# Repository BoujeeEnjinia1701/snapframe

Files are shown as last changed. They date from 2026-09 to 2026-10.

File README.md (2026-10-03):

# SnapFrame

     

**Area:** Situational Field Hardware · **TRL:** 3 of 9 (proof of concept on paper) · **Value-engineering target:** about $445 USD for the frame kit · **Difficulty:** 2 of 5

Frame kit of standard EMT conduit joined by printed or cast nodes, with parametric nodes generated for several shelter sizes.

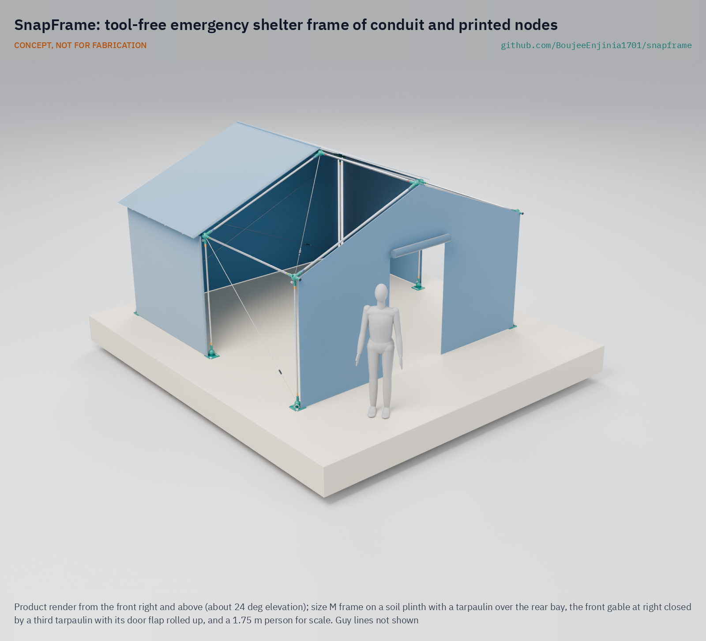
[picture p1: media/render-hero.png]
SnapFrame: tool-free emergency shelter frame of conduit and printed nodes, product render


[Exploded render](media/render-exploded.png) · [Detail render](media/render-detail.png) · [Interactive 3D model](media/viewer.html) · [Concept blueprint (PDF)](media/concept-blueprint.pdf) · [General arrangement (PDF)](cad/drawings/SNF-DWG-001.pdf) · [Calculations](docs/04-calcs/01-sizing.md) · [Prototype build plan](docs/05-build-plan.md) · [Design decisions](docs/06-design-decisions.md) · [Review note](docs/REVIEW.md)

## Concept rationale

A shelter frame has to arrive where the tarpaulins already are, go up by hand on the first day and be fixable by whoever is on site. SnapFrame therefore uses only straight, cut and drilled EMT conduit, a tube sold in hardware stores and electrical wholesalers across much of the world, and puts all the geometry into the nodes. The nodes are generated from a few parameters, so one open model gives the whole family of shelter sizes, and each node locks with the same spring button used in tent poles, so no tools, bolts or skilled labor are needed.

Keeping the design open and garage-buildable matters because relief supply chains break at the moment they are needed most. A local print farm, makerspace or small foundry can make the nodes from the published files, and a fabricator with a saw and a drill can cut the tubes, so a response does not wait for one supplier's crates or spare parts.

## Burning platform

Disasters triggered [45.8 million internal displacements in 2024, up from 26.8 million in 2023 and nearly double the annual average of the past decade](https://news.un.org/en/story/2025/05/1163176), according to the Internal Displacement Monitoring Centre, and a record 83.4 million people were living in internal displacement at the end of the year. Each of those households needs covered space quickly; the humanitarian minimum is [3.5 m² of covered living space per person](https://emergency.unhcr.org/emergency-assistance/shelter-camp-and-settlement/shelter-and-housing/emergency-shelter-solutions-and-standards).

The standard first response is still plastic sheeting. The IFRC and ICRC [shelter kit](https://itemscatalogue.redcross.int/relief--4/shelter-and-construction-materials--23/shelter-and-construction-kits--104/shelter-kit--KRELSHEK02.aspx) supplies two 4 x 6 m tarpaulins, rope, fixings and tools, but leaves the frame to local timber or bamboo, which is often scarce or already used up after a large event. The gap between a tarpaulin and a shelter that stands up to wind is a frame.

## Where it could be used

### By industry

| Industry | Use |
| --- | --- |
| Humanitarian shelter (relief agencies, NGOs) | Pre-positioned frame kits that fit existing tarpaulin stock in the first weeks after a disaster |
| Civil protection and emergency management | Mass care, reception and distribution points put up by volunteers without tools |
| Health and education in emergencies | Size L frames (about 24 m²) for temporary clinics, classrooms and child-friendly spaces |
| Events and temporary structures | Reusable shade and weather cover from one parametric kit, in place of bolted conduit frames |
| Agriculture | Shade, drying and storage shelters that later take better cladding |

### By country or region

| Country or region | Why it matters there |
| --- | --- |
| Pakistan | The 2022 floods affected [an estimated 33 million people and damaged nearly one million homes](https://news.un.org/en/story/2022/08/1125752), a scale at which local timber for frames runs out |
| Türkiye | The February 2023 earthquakes left [about 1.5 million people homeless in southern Türkiye](https://news.un.org/en/story/2023/02/1133717), with at least 500,000 new homes needed for reconstruction, so emergency shelter has to bridge years, not weeks |
| Mozambique | After Cyclone Idai in 2019, [more than 93,000 people were relocated to resettlement sites](https://www.unhcr.org/us/news/stories/one-year-people-displaced-cyclone-idai-struggle-rebuild) in the worst-affected region, and each of them needed a shelter |
| United States | A high-income example: the United States accounted for [about a quarter of the world's disaster displacements in 2024](https://news.un.org/en/story/2025/05/1163176), and EMT is stocked in hardware stores nationwide, so kits could be made near the response |

## What sparked the idea

The idea traces back to the MERO system, the "MEngeringhausen ROhrbauweise" (tube construction method) that Max Mengeringhausen developed in Germany at the end of the 1930s, as [economical building solutions made from industrially prefabricated series elements](https://mero.de/en/the-company/). The company's own patents describe the result: space frames of tubular rods screwed into near-spherical node pieces, citing Mengeringhausen's book *Raumfachwerke aus Stäben und Knoten* (Space frames of bars and nodes) ([EP0475216B1, MERO Raumstruktur](https://patents.google.com/patent/EP0475216B1/de)). MERO showed that when all the angles live in a mass-produced node, the members can be plain, identical tubes. SnapFrame takes that principle down to the scale of a family shelter: the tubes are trade-size conduit from a hardware store, the nodes are printed from a parametric model, and the screwed joints of MERO give way to spring buttons that lock by hand.

## Problem

Emergency shelters need frames that ship flat and go up without tools. Relief agencies stock standard 4 x 6 m tarpaulins, but the frame is usually left to scarce local timber, and purpose-built flat-pack shelters are costly and tied to one supplier. Design with, not for: requirements must come from co-design sessions and field trials with the intended users through a local partner.

## Concept

Frame kit of standard EMT conduit joined by printed or cast nodes, with parametric nodes generated for several shelter sizes.

The reference size M is a 4.0 x 4.0 m (16 m²) gable frame with a 2.6 m ridge: 18 straight EMT tubes (1 in rafters and ridge tubes, 3/4 in posts and eave tubes), 15 printed nodes in four variants with spring-button sockets, cable bracing, hand-turned screw anchors, and standard tarpaulins from agency stock (two, and part of a third for the front gable), and a folding step for the ridge sockets. The TRL 3 calculation note puts the constructable frame kit at about 46.2 kg and $701 ($256 over the $445 value-engineering target, mostly the nodes in filled nylon) and the wind rating at about 19.5 m/s, just short of the 20 m/s target, with the 3/4 in posts governing in the frame analysis. See the [design decisions register](docs/06-design-decisions.md) for decisions and open items.

Full design precis: [docs/02-concept.md](docs/02-concept.md)

## Key components

- EMT conduit in four cut lengths: 1 in rafters and ridge tubes, 3/4 in posts and eave tubes
- Printed nodes in filled PA12-class nylon, three types (four printed variants, none handed), castable in aluminum later
- Spring snap buttons and hitch pins
- Wire-rope brace cables with hand tensioners, clipped to anchor eyes and to steel rings on bolts through the nodes
- Three 4 x 6 m relief tarpaulins (agency stock): two whole, and part of a third, cut with a door flap, for the front gable
- Screw ground anchors (two longer ones at the rear corners) and guy lines
- A folding step to reach the ridge sockets

The working bill of materials is in [bom/bom.csv](bom/bom.csv).

## Building the prototype

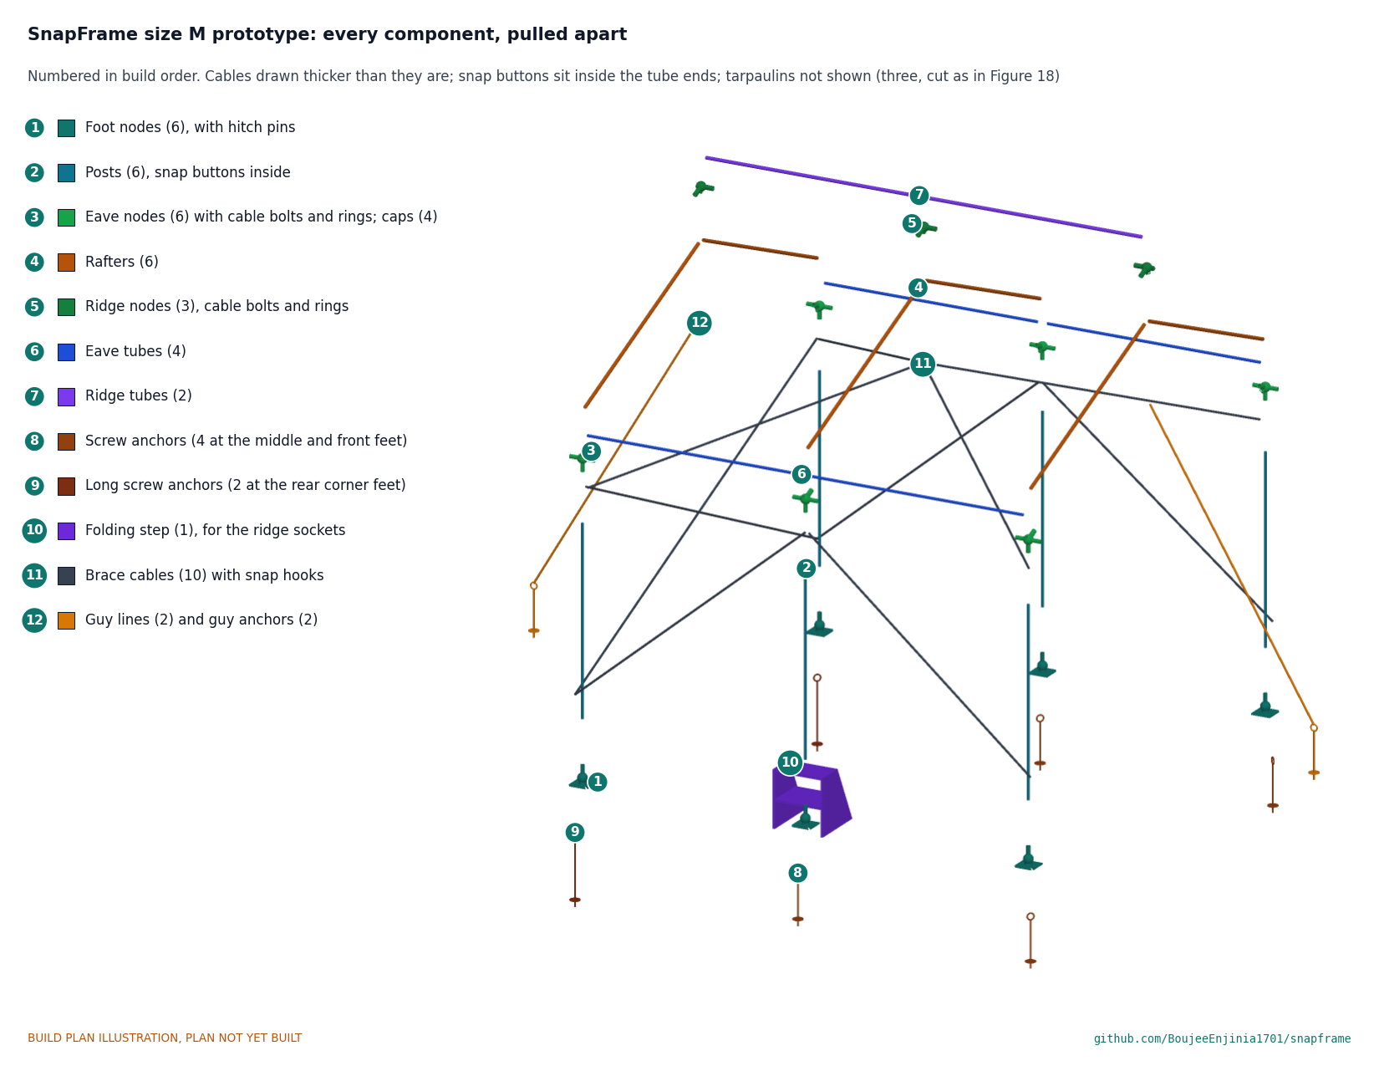
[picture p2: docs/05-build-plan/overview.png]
SnapFrame prototype: every component pulled apart and numbered in build order


The [prototype build plan](docs/05-build-plan.md) (SNF-BLD-001) shows, in pictures, how to make each of the nine made components and put the size M frame up in thirteen steps, with the tarpaulin cutting plan and the packing of the three packages; nothing has been built yet. The tubes are cut and drilled conduit with snap buttons fitted, the nodes are printed and each eave and ridge node gets a stainless cable bolt with a steel ring, and the brace cables are made up from wire rope. Writing the plan made the design buildable: the button and hitch pin moved apart inside the tube ends, the printed cable tabs became through-bolted rings, the cables now clip to the anchor eyes, the foot plate has two anchor slots, and the frames slide onto the tubes before the anchors go in (SNF-DDR-003, open for Amish's review). Every picture is drawn from the model, and the model checks that each part touches what it should and clears what it should not.

## Safety

> **Safety:** SnapFrame is an emergency shelter frame, not a storm refuge. By calculation it stays elastic with a factor of 1.5 only up to gusts of about 19.5 m/s (70 km/h), and about 14.7 m/s (53 km/h) with the door flap open and wind blowing into it, and it is not rated for snow. Leave the shelter in storms, clear snow and standing water, keep open flames outside (polyethylene tarpaulins burn), and rate the frame for local wind and snow before relying on it.

## Repository layout

| Folder | Contents |
| --- | --- |
| `docs/` | Problem, concept, requirements, calculations and design decisions |
| `cad/src/` | build123d Python source, the source of truth for all geometry |
| `cad/step/`, `cad/stl/` | Exported models for FreeCAD, other CAD tools and printing |
| `cad/drawings/` | 2D sketches and dimensioned drawings |
| `bom/` | Bill of materials |
| `electronics/` | KiCad schematics and PCB layouts |
| `firmware/` | Microcontroller code |
| `media/` | Renders, perspectives and photos |
| `build-log/` | Dated prototyping notes |

## Documentation

Controlled documents follow the portfolio [documentation standard](.kit/STANDARDS.md). Each carries a document ID (SNF-PRC-001 for the precis), a version and a revision history. Branded PDFs are built with `python .kit/render.py` and attached to GitHub Releases when a document is tagged, for example `SNF-PRC-001/v1.0`.

## Credits

Designed by Amish Chadha, with contributions from Ashok Kumar Chadha. See [CONTRIBUTORS.md](CONTRIBUTORS.md) for roles. To cite this design, use [CITATION.cff](CITATION.cff) (GitHub shows it as "Cite this repository").

AI assistance (Claude) was used to accelerate concept renders, prototype documentation and first-pass sizing calculations. Design direction and all decisions are Amish Chadha's, recorded in this repository's decision records (`docs/decisions/`).

## Licenses

- **Hardware** (CAD, drawings, BOM, electronics): [CERN-OHL-S v2](LICENSE)
- **Software** (firmware, scripts, notebooks): [MIT](LICENSE-SOFTWARE)

A project of the [Design Molecule](https://designmolecule.com) lab.

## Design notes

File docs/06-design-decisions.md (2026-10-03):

---
doc_id: SNF-DEC-001
title: SnapFrame design decisions register
project: SnapFrame
doc_type: Design decisions register
version: "0.4"
status: Draft
date: '2026-10-03'
author: Amish Chadha
license: CERN-OHL-S-2.0
revisions:
- version: "0.1"
  date: '2026-10-01'
  author: Amish Chadha
  change: Register opened with the build plan; open items from SNF-DDR-001 to SNF-DDR-003 and the review note; budget treated as a value-engineering target
- version: "0.2"
  date: '2026-10-02'
  author: Amish Chadha
  change: "Amish approved the recommendations for all ten open decisions (SNF-DDR-003 accepted); moved to decisions made; To confirm items 4 and 6 and the value engineering note updated"
- version: "0.3"
  date: '2026-10-02'
  author: Amish Chadha
  change: "Decisions carried into the design: value engineering restated at $700.56 (nodes in filled nylon, folding step, long anchors, straps); two new points found while doing so, proposed and awaiting Amish (node print cost, 1 in posts); To confirm items updated"
- version: "0.4"
  date: '2026-10-03'
  author: Amish Chadha
  change: "Amish accepted the cost overrun against the value-engineering target on 2026-10-03; row added to decisions made; value engineering section updated"
---

# SnapFrame design decisions register

Every design decision still to be made, and every decision made, in one place. Each decision is argued in full in its decision record under `docs/decisions/`; this register is the index Amish works from. The build plan (`docs/05-build-plan.md`) describes the design as it stands and does not list open decisions.

## Open decisions

Open decision 11 (cost) was decided on 2026-10-03. One new point found on 2026-10-02 while carrying the decisions of that day into the design is still open:

| # | Decision | Options | Recommendation | What it affects in the build | Source |
| --- | --- | --- | --- | --- | --- |
| 12 | Posts: the frame analysis is run (SNF-CAL-001 v0.6) and the windward 3/4 in post governs at a factor of 1.43 at 20 m/s (rating 19.5 m/s; 20.3 m/s with 1 in posts, about $30 more). The decision of 2026-10-02 fits 1 in posts only if the analysis had not been run, so the posts stay 3/4 in. | (a) keep 3/4 in posts and rate the kit at 19.5 m/s, as decided; (b) fit 1 in posts (6 sticks at $14.00 instead of $9.00, the 12 post sockets of the foot and eave nodes at 30.1 mm) and rate it at 20.3 m/s; (c) keep 3/4 in and test the knee fixity at TRL 4, which would give 20.0 m/s at best | (a) now, with (c) at TRL 4 and (b) held in reserve | Posts, foot nodes and eave nodes (model, BOM lines 1, 5, 6) | SNF-DDR-002 O8; SNF-CAL-001 v0.6 section 5 |

## To confirm when parts are bought

| # | What to confirm | Why it matters | Source |
| --- | --- | --- | --- |
| 1 | Snap buttons for 3/4 in and 1 in EMT: the spring reaches no more than 45 mm deeper than the button, and the button stands at least 3.5 mm above the tube surface | The spring must clear the hitch pin 15 mm from the tube end, and the button must stand proud in its finger recess | SNF-DDR-003, C1 and C2 |
| 2 | Snap hooks: the gate opens at least 14 mm, to pass the 12 mm wire of the anchor eye, and they fit the 6 mm ring | Every cable end clips to an anchor eye or a ring | SNF-DDR-003, C3 and C4 |
| 3 | Welded 6 mm ring of 32 mm bore: working load at least 2 kN; hand tensioner for 4 mm wire: working load at least 1.5 kN | The highest cable tension is 1.21 kN at 20 m/s; the tensioner rating has been unknown since TRL 3 | SNF-CAL-001, section 6 |
| 4 | Screw anchor: eye wire about 12 mm and eye about 56 mm across, so it straddles the 18 mm slot; holding capacity in the soils of the first site; a longer anchor of the same eye for the two rear corner feet | The eye clamps the foot plate; R8 needs 1.5 kN at the two rear corner feet and 1.0 kN at the others (decided 2026-10-02) | SNF-DDR-003, C5; R8 |
| 5 | EMT yield strength and dimensions from the supplier | The wind rating assumes 275 MPa yield | SNF-CAL-001, A3 |
| 6 | Print farm bed at least 230 mm, and that it can print glass- or carbon-filled PA12-class nylon (decided 2026-10-02), with a quote per kilogram | The eave and middle ridge nodes are 220 mm across; the node prices assume $55/kg and $1.50 a node | SNF-DDR-003; decision of 2026-10-02 on the node polymer; SNF-CAL-001 A12 |
| 7 | Folding step: top tread 0.50 m, about 1.5 kg, rated for 100 kg or more, folded 0.50 x 0.45 x 0.08 m | A person standing on the floor reaches about 2.2 m and the ridge sockets are at 2.6 m | SNF-DDR-003 A1 (decided 2026-10-02); BOM line 15 |
| 8 | Long screw anchor, 560 mm, rated 1.5 kN in firm soil, same 12 mm wire eye as the standard anchor | The two rear corner feet carry up to 1.28 kN | SNF-CAL-001 section 6; R8; BOM line 16 |

## Value engineering

Value-engineering target: USD 445. Estimated cost of the constructable design: USD 700.56 (USD 255.56 over the target). This is the size M frame kit; the target is a hypothetical control target, not a limit. Tarpaulins are agency stock and costed separately (three, USD 75.00). The estimate rose from USD 469.14 (SNF-CAL-001 v0.5) because of decisions made on 2026-10-02. Main cost drivers and savings worth trying:

Amish accepted this overrun on 2026-10-03: the estimated cost of USD 700.56 against the USD 445 target (USD 255.56 over), with the nodes in filled nylon (open decision 11, option a). Amish: "Cost over target - i accept all the cost variations and overruns". It stays reported against the target as an accepted overrun, and the savings below remain worth trying.

- The largest lines are the 15 printed nodes (USD 316.16 in filled PA12-class nylon, of which the six foot nodes are USD 160.86), the tubes (USD 202.00 for 18 sticks, 39 % of the tube bought ends up as offcut), the brace cables (USD 42.00), the anchors (USD 36.00, six standard and two long), the folding step (USD 25.00), the buttons, pins and caps (USD 24.00) and the cable bolt sets (USD 23.40).
- What changed on 2026-10-02: the nodes rose by USD 196.42 (filled nylon at USD 55/kg and 1,200 kg/m³ instead of ASA at USD 22/kg and 1,070 kg/m³, and USD 1.50 of machine time a node instead of USD 1.00); the folding step added USD 25.00; the two long anchors added USD 4.00 net of the two standard anchors they replace; the second set of straps added USD 6.00.
- Savings worth trying: a print farm quote for the filled nylon (open decision 11, accepted as an overrun on 2026-10-03, so the quote is optional); lower infill on the low-stress ridge nodes once their coupons are tested; a lighter foot plate, since the foot node is the most expensive print (USD 26.81 each); bulk or 6 m metric tube, which also cuts the offcut (the 39 % offcut is accepted for the prototype, decided 2026-10-02); casting the nodes in aluminum later; and stainless hardware bought by the hundred for the cable bolt sets.

## Decisions made

| Date | Decision | Decided by | Record |
| --- | --- | --- | --- |
| 2026-09-25 | TRL 2 review items D1 to D7: budget covers the frame kit, tarpaulins from agency stock; 1 in EMT rafters; print nodes, design for casting; spring buttons plus hitch pins at the 12 tension joints; gable with cable bracing; sizes S, M and L with M as reference; snow and cyclone out of scope | Amish: "proceed with all of your recommendations across all batches. Make sure we don't proceed to TRL 4 on any of them." | SNF-DDR-001 |
| 2026-09-25 | D8: 1 in EMT ridge tubes, frame analysis before any decision on posts. D9: one four-socket eave node at all six positions, the corner socket past the gable left blank and capped | Amish: "i accept all your recommendations, go with them across all repos." | SNF-DDR-002 |
| 2026-09-26 | Budget set to $445 to cover the priced frame kit (O4 closed) | Amish: "i approve all the budget items." | SNF-DDR-002 v0.2 |
| 2026-09-30 | Prototype build plan in the approved format; outstanding decisions kept out of the build plan and in this register | Amish: "this is the correct build plan ... this is a good quality document format. Extend this across all the other repos"; "don't log outstanding decisions in this build plan - that is not the place for it" | `.kit/STANDARDS.md` section 18 |
| 2026-09-30 | Fix the design where it cannot be built as drawn, keeping what it does | Amish: "If you are realising that the design cannot be built as per concept - fix the design assumptions to match and be physically feasible as you draw the illustrations." | SNF-DDR-003 (the changes themselves are open decision 1) |
| 2026-10-01 | `budget_usd` is a value-engineering target, not a limit; cost reported as over or under it | Amish: "the budgets are a hypothethical control target to ensure we are thinking along a value engineering lens" | `.kit/STANDARDS.md` section 18 |
| 2026-10-02 | Design for construction accepted: the nine changes C1 to C9 as made (open item 1) | Amish: "i approve your recommendations for all 555 open decisions." | SNF-DDR-003, C1 to C9 |
| 2026-10-02 | Ridge tubes: the first prototype uses a folding step; guiding from the ground with a spare tube (option b) is timed in the TRL 4 user trial, and the step stays in the kit if ground guiding is slower or needs a third person (open item 2) | Amish: "i approve your recommendations for all 555 open decisions." | SNF-DDR-003, A1 |
| 2026-10-02 | Front gable closed with part of a third tarpaulin from agency stock, cut to include a door flap; the corner cable hem is settled in the same cutting plan; R7 restated to match (open item 3) | Amish: "i approve your recommendations for all 555 open decisions." | SNF-DDR-001, O3; SNF-DDR-003, A2; SNF-REQ-001 R7 |
| 2026-10-02 | Posts: the frame analysis is run now, as paper work at TRL 3; if it has not been run when the prototype tubes are bought, 1 in posts are fitted (open item 4) | Amish: "i approve your recommendations for all 555 open decisions." | SNF-DDR-002, O8 |
| 2026-10-02 | Packages: the tubes are split into two bundles (16.5 and 12.1 kg) and R5 restated as three packages of 25 kg or less; R11 is counted on the frame kit alone (43.3 kg against 50 kg), since the tarpaulins are issued separately from agency stock (open item 5) | Amish: "i approve your recommendations for all 555 open decisions." | SNF-DDR-002, O5; SNF-DDR-003 |
| 2026-10-02 | Node polymer: a glass- or carbon-filled nylon of the PA12 class, with printed coupons tested for pin bearing at 70 °C at TRL 4; PETG dropped (open item 6) | Amish: "i approve your recommendations for all 555 open decisions." | SNF-DDR-002, O6 |
| 2026-10-02 | Anchors: the target at the two rear corner feet is raised to 1.5 kN, with longer anchors there; 1.0 kN is kept at the other feet (open item 7) | Amish: "i approve your recommendations for all 555 open decisions." | SNF-DDR-002, O7 |
| 2026-10-02 | Tube offcut of 39 % accepted for the prototype on US 10 ft stock; the choice between 1.50 m posts and 6 m metric stock is made once the first region's tube source is known (open item 8) | Amish: "i approve your recommendations for all 555 open decisions." | SNF-DDR-001, O1 |
| 2026-10-02 | Partners: the IFRC Shelter Research Unit is the first candidate to approach for a technical review of the kit with standard relief tarpaulins, and Field Ready as the printing partner; the region is taken from the first warm-climate response the review points to (open item 9) | Amish: "i approve your recommendations for all 555 open decisions." | SNF-DDR-001, O2 |
| 2026-10-02 | Renders: the first three render choices accepted (tube split at the detail node, hero without guy lines, foot plate grip ribs and size mark as appearance only); the fourth (brace cable start at the detail node) withdrawn when the renders are redone (open item 10) | Amish: "i approve your recommendations for all 555 open decisions." | `docs/REVIEW.md`, 2026-09-26 render session, items 1 to 4 |
| 2026-10-03 | Cost overrun accepted: the estimated cost of USD 700.56 against the USD 445 target (USD 255.56 over), with the nodes in filled nylon (open decision 11, option a) | Amish: "Cost over target - i accept all the cost variations and overruns" | [REVIEW.md](REVIEW.md), session 2026-10-03 |

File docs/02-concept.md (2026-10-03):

---
doc_id: SNF-PRC-001
title: SnapFrame design precis
project: SnapFrame
doc_type: Design precis
version: "0.8"
status: Draft
date: '2026-10-02'
author: Amish Chadha
license: CERN-OHL-S-2.0
revisions:
- version: "0.1"
  date: '2026-09-24'
  author: Amish Chadha
  change: Initial scaffold
- version: "0.2"
  date: '2026-09-25'
  author: Amish Chadha
  change: Populate to TRL 2 (architecture, sizes, first-order numbers, design choices, safety, media)
- version: "0.3"
  date: '2026-09-25'
  author: Amish Chadha
  change: Apply SNF-DDR-001 (1 in rafters, frame kit budget, decided design choices); numbers from SNF-CAL-001; parametric model and SNF-DWG-001
- version: "0.4"
  date: '2026-09-25'
  author: Amish Chadha
  change: Recommendations accepted by Amish (DDR-002)
- version: "0.5"
  date: '2026-09-26'
  author: Amish Chadha
  change: Budget approved by Amish ($445, SNF-DDR-002); cost figure restated against it
- version: "0.6"
  date: '2026-10-01'
  author: Amish Chadha
  change: Design for construction (SNF-DDR-003, Draft) applied; erection order, joints and cable fixings updated; cost against the value-engineering target
- version: "0.7"
  date: '2026-10-02'
  author: Amish Chadha
  change: "Gable, packages, polymer, anchors, posts, offcut and partner decided by Amish on 2026-10-02 (SNF-DEC-001)"
- version: "0.8"
  date: '2026-10-02'
  author: Amish Chadha
  change: "Decisions of 2026-10-02 carried into the design: folding step, three tarpaulins with the cutting plan, long rear anchors, filled nylon nodes, frame analysis (rating 19.5 m/s), two tube bundles; mass, packages and cost from SNF-CAL-001 v0.6"
---

# SnapFrame design precis

SnapFrame is a gable-roof shelter frame of straight EMT conduit joined by printed nodes: 1 in EMT rafters and ridge tubes, and 3/4 in EMT posts and eave tubes. Each tube end carries a spring button that snaps into a hole in the node socket, so two adults can put the frame up by hand. The reference size M covers 4.0 x 4.0 m (16 m²) with a 2.6 m ridge and takes three standard 4 x 6 m relief tarpaulins from agency stock as its skin (two for the roof, side walls and rear gable, the third cut for the front gable with a door flap). The TRL 3 calculation note SNF-CAL-001 v0.6 puts the constructable frame kit (SNF-DDR-003) at about 46.2 kg and $701, $256 over the $445 value-engineering target (the nodes are in filled PA12-class nylon), and rates the frame at about 19.5 m/s (70 km/h, 44 mph), just short of the 20 m/s target, with the 3/4 in posts governing in the frame analysis.

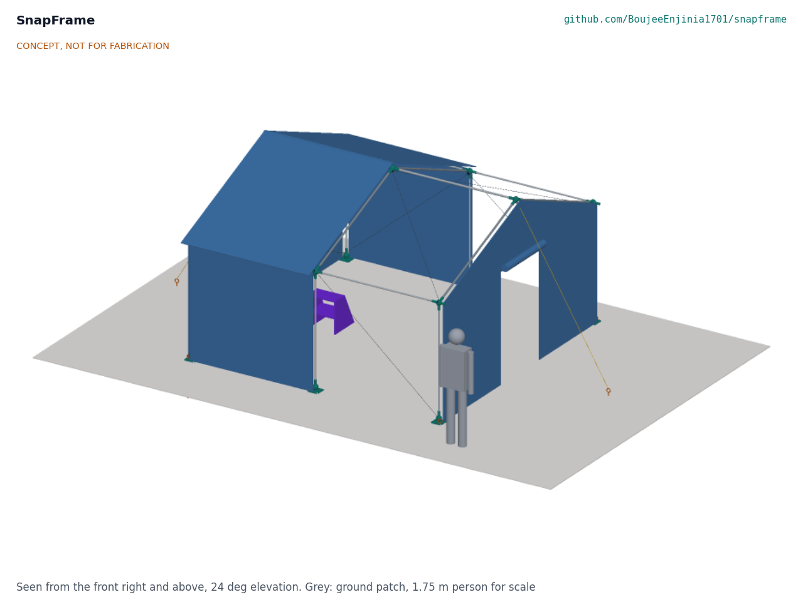
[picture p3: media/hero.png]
Hero render


*Figure 1. SnapFrame size M with a 1.75 m person for scale. The tarpaulin skin is shown on the rear bay and the front gable (door flap rolled up), so the frame, nodes and bracing stay visible between them. Generated from the parametric model `cad/src/model.py`.*

## How it works

1. **Unpack.** The frame kit arrives as two strapped bundles of straight tubes (18 in all, four types, color-coded at the ends, snap buttons fitted) and a bag with 15 nodes (three families, four printed variants, cable bolts fitted to the eave and ridge nodes), 10 brace cables, 8 screw anchors (two of them longer), 2 guy lines, a folding step, hitch pins and caps. Three tarpaulins come from agency stock.
2. **Mark out.** Six pegs mark the feet with a knotted layout cord (4.0 x 4.0 m, diagonals equal).
3. **Build the frames.** Each of the three gable frames is two posts, two rafters, two eave nodes, one ridge node and two foot nodes, assembled flat on the ground. Every joint closes with a click as the spring button finds its hole; hitch pins go in at the feet and the eave post sockets.
4. **Stand and join the frames.** The rear frame is walked up and stood on its marks. The ridge and eave tubes go into it, and the middle frame, stood 70 mm short of its marks, slides 65 mm on its feet onto the three tube ends; the front bay follows the same way (SNF-DDR-003 C7). A folding step in the kit reaches the ridge sockets at 2.6 m (decided 2026-10-02; guiding from the ground is timed at TRL 4). Then the frame is squared, and a screw anchor is turned in by hand through a slot in each foot plate, using a spare tube through its eye as a lever, until the eye sits down on the plate.
5. **Brace.** Brace cables with hand tensioners go into the rear gable, one bay of each side wall and one diagonal per bay in each roof plane. Their snap hooks clip to the anchor eyes at the feet and to the steel ring on each eave and ridge node's cable bolt, and they are pulled snug. Guy lines run from the rings of the two end ridge nodes to anchors 1.5 m beyond each gable.
6. **Skin.** One tarpaulin goes over the ridge as the roof; the second is cut into three strips that close both side walls and the lower rear gable. Part of a third tarpaulin from agency stock, cut to include a door flap, closes the front gable, and the gable tops come from its offcut (R7, decided 2026-10-02; cutting plan in the build plan, Figure 18). The blank socket on each corner eave node takes a push-in cap. Tarpaulins are tied through their eyelets to the tubes, never to the nodes.
7. **Strike and reuse.** Pressing each button in its finger recess releases its joint. Tubes and nodes go back in the bundle and bag, or the frame stays and carries better cladding later.

## Main components

Table 1. Main components. Numbers match `bom/bom.csv`, Figure 2 and drawing SNF-DWG-001.

| # | Component | Choice | Notes |
| --- | --- | --- | --- |
| 1 | Posts (6) | 3/4 in EMT, 1.650 m | One 3.05 m (10 ft) stick each |
| 2 | Rafters (6) | 1 in EMT, 2.064 m | SNF-DDR-001 D2; second socket bore on eave and ridge nodes |
| 3 | Ridge tubes (2) | 1 in EMT, 1.910 m | SNF-DDR-002 D8 (were 3/4 in and governed the wind rating) |
| 4 | Eave tubes (4) | 3/4 in EMT, 1.910 m | Same length as item 3, smaller tube; different end color for the guide |
| 5 | Foot nodes (6) | Printed in filled PA12-class nylon, one socket, 170 x 170 x 12 mm plate with two anchor slots at 45° | About 460 g each |
| 6 | Eave nodes (6) | Printed, four sockets and a cable bolt hole, one variant | At the corners the socket past the gable stays blank and capped (SNF-DDR-002 D9); about 287 g |
| 7 | Ridge nodes (3) | Printed, three or four sockets, all 30.1 mm bore, and a cable bolt hole | About 277 to 304 g |
| 8 | Brace cables (10) | 4 mm galvanized wire rope, thimble loop, hand tensioner, snap hook at each end | 29.5 m eye to eye |
| 9 | Screw ground anchors (6) | 380 mm galvanized screw anchor with eye | Four at the middle and front feet, two for guys |
| 10 | Guy lines (2) | 6 mm polyester rope with slide tensioner | From end ridge nodes |
| 11 | Skin | Three 4 x 6 m reinforced polyethylene tarpaulins | Agency stock, outside the kit budget (SNF-DDR-001 D1); the third closes the front gable with a door flap |
| 12 | Snap buttons, hitch pins and caps | 36 spring buttons (one per tube end), 12 hitch pins on lanyards, 4 socket caps | Hitch pins at the 12 tension joints (SNF-DDR-001 D4) |
| 13 | Bundle straps and bag | Four cam straps, two for each tube bundle; one duffel bag | |
| 14 | Cable bolt sets (9) | Stainless M10 bolt through each eave and ridge node, with spacer, washers, nyloc nut and a welded 6 mm ring | The cables and guy lines clip to the ring (SNF-DDR-003 C3) |
| 15 | Folding step (1) | Two-tread steel or aluminum step, top tread 0.50 m, about 1.5 kg | Reaches the ridge sockets at 2.6 m (SNF-DDR-003 A1, decided 2026-10-02) |
| 16 | Long screw anchors (2) | 560 mm galvanized screw anchor with the same eye, rated 1.5 kN | One at each rear corner foot (R8, raised 2026-10-02) |

### Node concept

A node is a spherical core (84 mm diameter) with one socket per member. Each socket is 110 mm long from the node center; the tube end stops 45 mm from the center, so it engages 65 mm. The bore is the tube outside diameter plus 0.6 mm (24.0 mm for 3/4 in, 30.1 mm for 1 in) and the socket wall is 5 mm. One eave node serves all six eave positions; it is symmetric about its own frame line, so it is not handed, and at the corners its outward socket stays empty under a cap. A 6 mm spring button hole sits 40 mm from the tube end, in a 16 mm finger recess so the button can be pressed by hand; at the feet and eave post sockets an 8 mm hitch pin hole sits 15 mm from the tube end, clear of the button's spring inside the tube (SNF-DDR-003 C1, C2). Each socket mouth has a lead-in chamfer. Each eave and ridge node carries a through-bolted M10 cable bolt with a steel ring, and the foot plate has two anchor slots, so the cables never load the print in bending (SNF-DDR-003 C3 to C6). Socket axes are computed from the node positions, so a new width, length or pitch produces a new set of printable nodes. The prototype prints the nodes, and the printed node is intended to become a pattern for sand-cast aluminum later (SNF-DDR-001 D3); castability is not checked at TRL 3.

## Sizes

Table 2. Size family generated from the same parameters (SNF-DDR-001 D6). The model exports the node set of every size.

| Size | Floor | Bays | Eave and ridge | People at 3.5 m² each | Members | Nodes |
| --- | --- | --- | --- | --- | --- | --- |
| S | 3.0 x 3.0 m (9 m²) | 2 x 1.5 m | 1.8 m, 2.4 m | 2 | 18 | 15 (new angles) |
| M (reference) | 4.0 x 4.0 m (16 m²) | 2 x 2.0 m | 1.8 m, 2.6 m | 4 | 18 | 15 |
| L | 4.0 x 6.0 m (24 m²) | 3 x 2.0 m | 1.8 m, 2.6 m | 6 | 25 | 20 (same types as M) |

## Key numbers

All values are from SNF-CAL-001, which lists its assumptions. They are calculations on paper, not measurements.

Table 3. Geometry, mass, cost and wind, size M.

| Quantity | Value | Requirement |
| --- | --- | --- |
| Floor area | 16.0 m² | R1 met |
| Headroom 2.0 m or more | 73 % of floor | R2 met |
| Tube length in the kit | 33.7 m (54.9 m bought, 39 % offcut) | |
| Frame kit mass | 46.2 kg (102 lb); 59.9 kg with three tarpaulins | R11 met: frame kit alone counted since 2026-10-02 (tarpaulins issued separately) |
| Packages | Two tube bundles, 16.7 and 12.3 kg, 0.017 and 0.013 m³; bag 17.2 kg, 0.075 m³ (30.9 kg with three tarpaulins) | R5 met (three packages, restated 2026-10-02) |
| Erection time | About 46 min for two adults (estimate) | R4 not verifiable at TRL 3 |
| Skin area | 51.4 m² for full enclosure; the cutting plan uses 59.6 m² of the 72 m² in three tarpaulins | R7 met, cutting plan drawn (third tarpaulin decided 2026-10-02) |
| Frame kit cost | About $701; value-engineering target $445 | R10: $256 over the value-engineering target (nodes $316 in filled nylon, $120 in ASA) |
| Dynamic pressure at 20 m/s | 245 Pa | |
| Rafter (1 in) at 20 m/s | 142 N·m, 166 MPa, factor 1.66 | Meets 1.5 |
| Ridge tube (1 in) at 20 m/s | 106 N·m, 124 MPa, factor 2.22 | Meets 1.5 (1.18 with 3/4 in) |
| Post (3/4 in) at 20 m/s | 86 N·m and 369 N axial, 192 MPa, factor 1.43 (frame analysis; 1.46 bending only) | R6 **not met** |
| Wind rating | 19.5 m/s (70 km/h, 44 mph); 14.7 m/s with the door flap open and wind into it | R6 **not met** (posts govern) |
| Worst foot anchor uplift | 1.28 kN at a rear corner, before pretension | R8 at risk (1.5 kN target at the rear corner feet since 2026-10-02) |
| Snow | Not rated; 0.5 kPa would put 416 MPa in a 1 in rafter | Out of scope |

The TRL 2 estimates (factor 1.70 for posts, 1.26 for 3/4 in rafters, about 18 m/s) spread half of each panel uniformly over the frames. SNF-CAL-001 uses 45° tributary lines, which peak at midspan and give higher moments. On that basis, a 3/4 in rafter would reach only 0.89.

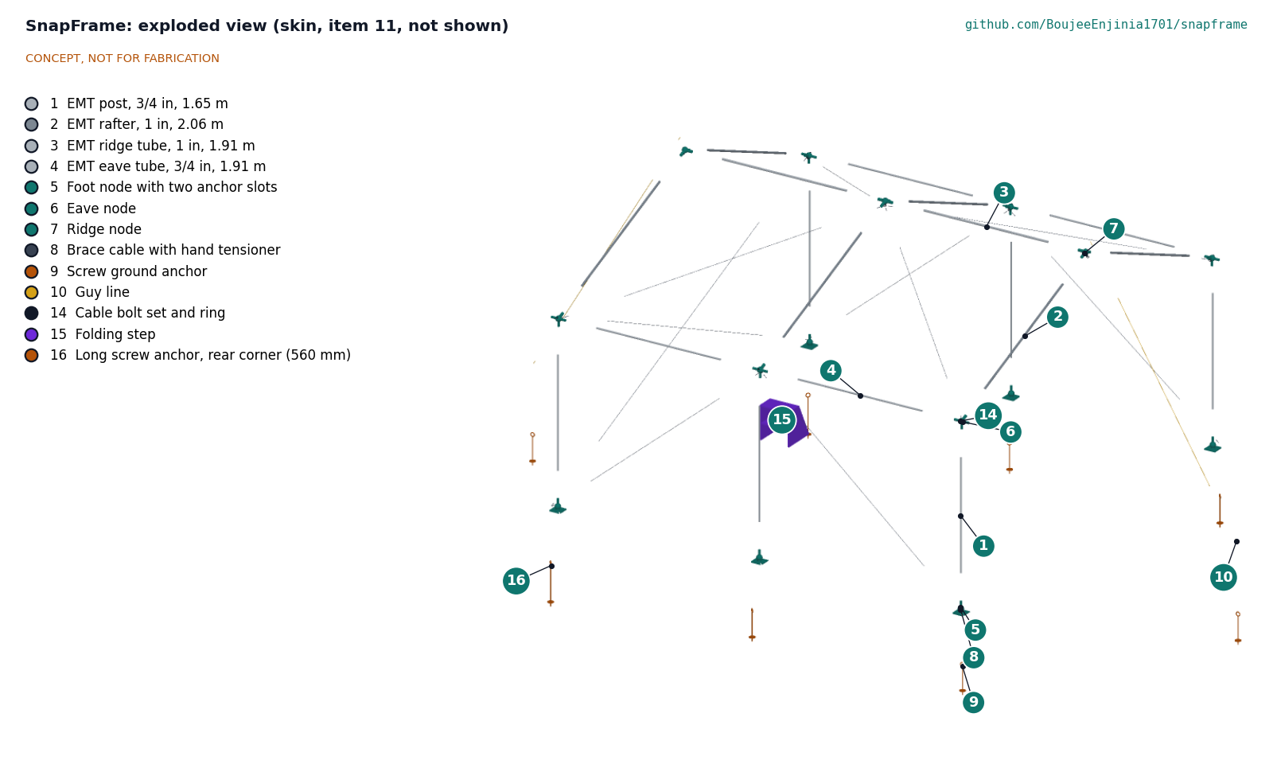
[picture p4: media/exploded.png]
Exploded view


*Figure 2. Exploded view with BOM numbers. The skin (item 11) is left out so the frame parts stay visible; items 12 and 13 are not modeled; item 15 is the folding step and item 16 the long rear anchors.*

## Design choices

Decided by Amish on 2026-09-25 (SNF-DDR-001):

- **Tube size (D2).** 1 in EMT rafters, with the wind rating stated on the kit.
- **Budget scope (D1).** The budget covers the frame kit; Amish set it at $445 on 2026-09-26 (SNF-DDR-002) and on 2026-10-01 made it a value-engineering target, not a limit. Tarpaulins come from agency stock and are costed separately.
- **Node process (D3).** Print for the first prototype, design every node to be castable from the printed pattern.
- **Joint locking (D4).** Spring buttons at every tube end, hitch pins at the 12 tension joints.
- **Frame form (D5).** Gable roof with pinned nodes and cable bracing, not a dome, barrel vault or rigid nodes.
- **Sizes (D6)** S, M and L, with M as the reference, and **scope (D7)** without snow or cyclone rating in the first release.

Decided by Amish on 2026-09-25, going with the recommendations (SNF-DDR-002):

- **Ridge tubes (D8).** 1 in EMT ridge tubes as well, which lifts the rating from 17.8 to 19.7 m/s by the member check, and to 19.5 m/s once the frame analysis (run 2026-10-02) adds axial force. The posts stay 3/4 in; 1 in posts would give 20.3 m/s for about $30 more.
- **One eave node (D9).** The four-socket eave node is used at the corners with one blank, capped socket, so there are no handed nodes and R12 is met.
- **Wind rating on the kit (D2 with D8).** Until R6 is met the kit label states 19.5 m/s (70 km/h) and about 14.7 m/s with the door flap open and wind into it.

Decided by Amish on 2026-10-02 (SNF-DEC-001): the design for construction changes of SNF-DDR-003 are accepted; the 39 % tube offcut is accepted for the prototype, with 1.50 m posts or 6 m metric stock chosen once the first region's tube source is known; the IFRC Shelter Research Unit is the first candidate to approach for a technical review and Field Ready for printing; part of a third tarpaulin closes the front gable (R7); the frame analysis is run now (done in SNF-CAL-001 v0.6, posts stay 3/4 in) (R6); a folding step joins the kit for the first prototype; the tubes go in two bundles, R5 is three packages and R11 counts the frame kit alone; the nodes are printed in glass- or carbon-filled PA12-class nylon (R9); and the rear corner anchors are rated 1.5 kN (R8). Cost is followed against the value-engineering target in the register rather than as a decision.

## Safety

> **Safety:** SnapFrame is an emergency shelter frame, not a storm refuge. By calculation (SNF-CAL-001) it stays elastic with a factor of 1.5 only up to gusts of about 19.5 m/s (70 km/h, 44 mph), and about 14.7 m/s (53 km/h) when wind blows into the open door. Above that, or when a storm warning is issued, occupants should drop the skin, leave the shelter and follow local evacuation guidance. A collapsing steel frame can injure people inside.

> **Safety:** The frame is not rated for snow. Snow or ponding water on the roof can overload the rafters within hours. Clear the roof, or leave the shelter, whenever snow or standing water collects.

> **Safety:** Polyethylene tarpaulins burn quickly and drip. Keep cooking fires, candles, kerosene lamps and stoves outside the shelter or behind a non-combustible screen, keep at least 2 m between shelters where the site allows, and keep the doorway clear. A fire-retardant tarpaulin option is an open requirement (R13).

- **Erection.** Walking a frame up takes two people. Keep hands clear of sockets as tubes drop in (pinch points), and never erect or strike the frame in strong wind, when the tarpaulin acts as a sail.
- **Tube ends.** Cut EMT ends are sharp. Every tube is deburred during kit preparation, and ends sit inside sockets once assembled.
- **Guy lines and anchors.** Guy lines are a trip hazard at night; mark them with reflective tape. Screw anchors must be clear of buried cables and pipes.
- **Electrical.** The frame is conductive steel. Any lighting inside must be low-voltage DC (for example solar lanterns); mains cables must not be run on or near the frame.
- **Lightning.** A steel frame gives no reliable lightning protection. Leave it during thunderstorms where a solid building is available.

## Open questions

- R6: with 1 in ridge tubes the 3/4 in posts (factor 1.43 in the frame analysis) still fall short at 20 m/s. Whether a real socket gives the knee fixity that would lift the factor to 1.49 or more is a TRL 4 test; 1 in posts remain an option (SNF-CAL-001 v0.6).
- R5 and R11: decided 2026-10-02, two tube bundles of 16.7 and 12.3 kg (three packages) and the carried mass counted on the frame kit alone, 46.2 kg (SNF-DEC-001).
- Confirm EMT yield strength and dimensions from supplier data for the first region, and whether metric thin-wall tube of about 25 mm is stocked where EMT is not.
- Node polymer: glass- or carbon-filled PA12-class nylon chosen on 2026-10-02; printed coupons to be tested for pin bearing at 70 °C, and its strength under UV over two years confirmed (R9).
- Anchor holding capacity in sand, clay and gravel, and the rating of the hand cable tensioners (R8).
- Fire-retardant tarpaulin sources and cost (R13).
- Picture-only erection guide: test with users who have not seen the kit.
- Validate floor area, headroom, erection time, wind exposure and price with users through a local partner.

Drawings and media: [prototype build plan SNF-BLD-001](05-build-plan.md), [design decisions register SNF-DEC-001](06-design-decisions.md), [general arrangement SNF-DWG-001](../cad/drawings/SNF-DWG-001.pdf), [blueprint sheet](../media/concept-blueprint.pdf), [interactive 3D model](../media/viewer.html).

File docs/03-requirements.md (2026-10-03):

---
doc_id: SNF-REQ-001
title: SnapFrame requirements
project: SnapFrame
doc_type: Requirements
version: "0.8"
status: Draft
date: '2026-10-02'
author: Amish Chadha
license: CERN-OHL-S-2.0
revisions:
- version: "0.1"
  date: '2026-09-24'
  author: Amish Chadha
  change: Initial scaffold
- version: "0.2"
  date: '2026-09-25'
  author: Amish Chadha
  change: First measurable requirements for TRL 2, with status against the concept estimates
- version: "0.3"
  date: '2026-09-25'
  author: Amish Chadha
  change: Apply SNF-DDR-001 (R10 redefined as the frame kit; 1 in rafters); status from SNF-CAL-001
- version: "0.4"
  date: '2026-09-25'
  author: Amish Chadha
  change: Recommendations accepted by Amish (DDR-002)
- version: "0.5"
  date: '2026-09-26'
  author: Amish Chadha
  change: Budget approved by Amish
- version: "0.6"
  date: '2026-10-01'
  author: Amish Chadha
  change: Status from SNF-CAL-001 v0.4 after the design for construction (SNF-DDR-003); R10 reported against the value-engineering target
- version: "0.7"
  date: '2026-10-02'
  author: Amish Chadha
  change: "R5, R7, R8 and R11 restated and R6 and R9 status notes updated after Amish's decisions of 2026-10-02 (SNF-DEC-001)"
- version: "0.8"
  date: '2026-10-02'
  author: Amish Chadha
  change: "Status from SNF-CAL-001 v0.6 after the approved decisions were carried into the design: frame analysis run (R6 19.7 to 19.5 m/s), cutting plan drawn (R7 met), long rear anchors (R8), nodes in filled nylon, folding step, packages and mass (R5, R11), cost $700.56 (R10)"
---

# SnapFrame requirements

These are first-pass requirements for the concept. Targets are proposals for review, not user-validated needs, and will be revised after co-design sessions. The status column comes from the TRL 3 calculation note SNF-CAL-001 v0.6, for the constructable size M frame of SNF-DDR-003 with 1 in EMT rafters (SNF-DDR-001 D2) and ridge tubes (SNF-DDR-002 D8), 3/4 in EMT posts and eave tubes, and one eave node variant (SNF-DDR-002 D9). Two requirements are **not met**: R6 (wind) and R13 (fire). Two are at risk: R8 (anchors) and R9 (nodes). R1, R2, R3, R5, R7, R11 and R12 are met, R5, R7 and R11 as restated by Amish on 2026-10-02 (SNF-DEC-001): three packages, a third tarpaulin for the front gable, and the carried mass counted on the frame kit alone. R8 was restated the same day (1.5 kN at the two rear corner feet). R10 is reported against its value-engineering target: the constructable frame kit is $255.56 over it, mostly because the nodes are now in filled PA12-class nylon ($316 against $120 in ASA).

| ID | Requirement | Target | Status (SNF-CAL-001) | Verification (TRL 3 or later) |
| --- | --- | --- | --- | --- |
| R1 | Give enough covered living space | Size M: 16 m² floor or more, which is 3.5 m² per person for four people (Sphere minimum) | Met: 4.0 x 4.0 m = 16.0 m² | Geometry |
| R2 | Give standing headroom | 2.0 m or more over at least 60 % of the floor | Met: 73 % of the floor, measured to the rafter underside | Geometry |
| R3 | Cover several sizes from one design | At least three sizes (S about 9 m², M 16 m², L about 24 m²) generated from one parametric node model; M and L share every tube length | Met: `cad/src/model.py` generates and exports the S, M and L node sets | Parametric model |
| R4 | Go up without tools | Two adults with no tools and no prior training, using a picture guide, erect frame and skin of size M in 60 min or less | Not verifiable at TRL 3: estimate about 46 min | Time study in a later user trial (TRL 4 or later) |
| R5 | Ship flat | No member longer than 2.1 m; all members straight; kit in three packages (two tube bundles and a bag), each 25 kg (55 lb) or less and 0.10 m³ or less (restated 2026-10-02, SNF-DEC-001) | Met on paper: longest member 2.064 m; tube bundles about 16.7 and 12.3 kg (0.017 and 0.013 m³); bag 17.2 kg and 0.075 m³ without tarpaulins, which are issued from agency stock | Massing model, then weighing |
| R6 | Resist wind with the skin on | Every member stays elastic with a safety factor of 1.5 or more on yield in gusts of 20 m/s (72 km/h, 45 mph) | **Not met:** rating about 19.5 m/s (70 km/h, 44 mph) with 1 in ridge tubes (SNF-DDR-002 D8); by the frame analysis run on 2026-10-02 (axial force added to bending) 3/4 in posts reach 1.43 at 20 m/s (1.46 bending only); 1 in rafters 1.62 and 1 in ridge tubes 2.22. The analysis has been run, so the posts stay 3/4 in; 1 in posts would give 20.3 m/s for about $30 | Wind load calculation (CAL), then frame analysis |
| R7 | Fit standard relief tarpaulins | Two 4 x 6 m tarpaulins close the roof, both side walls and the rear gable, and part of a third, cut to include a door flap, closes the front gable; all from agency stock (restated 2026-10-02, SNF-DEC-001) | Met: the cutting plan is drawn and checked (build plan Figure 18); full enclosure needs about 51.4 m² and the pieces use 59.6 m² of the 72 m² in three tarpaulins, with a door flap of 1.0 x 1.7 m and corner cable hems of 0.40 x 0.20 m | Cutting and folding plan |
| R8 | Anchor without a hammer | Every foot and guy anchored by hand; each anchor holds 1.0 kN uplift in firm soil, and each of the two rear corner feet 1.5 kN with longer anchors (raised 2026-10-02, SNF-DEC-001) | **At risk:** estimated demand up to 1.28 kN at a rear corner foot before cable pretension (the gable and side wall cables clip to that anchor's eye), inside the 1.5 kN target there, where the kit now has two longer 560 mm anchors rated 1.5 kN (BOM item 16); holding capacity not verifiable at TRL 3 | Anchor pull-out data for the chosen anchor and soils |
| R9 | Keep nodes strong in sun and cold | Nodes carry the socket forces from R6 with a factor of 2 after two years outdoors, from -10 to 70 °C surface temperature | **At risk:** hitch pin bearing on the socket about 32 MPa with the factor of 2; polymer chosen on 2026-10-02 (glass- or carbon-filled PA12-class nylon, SNF-DEC-001), printed coupons to be tested for pin bearing at 70 °C at TRL 4 | Material data, then node load tests (TRL 4) |
| R10 | Keep to the value-engineering target | Size M frame kit at or below the $445 value-engineering target (`budget_usd`, a control target, not a limit; Amish, 2026-10-01) in prototype quantities, excluding tarpaulins, which come from agency stock and are costed separately (SNF-DDR-001 D1; SNF-DDR-002) | Frame kit about $701 for the constructable design ($700.56), $255.56 over the value-engineering target; three tarpaulins about $75 extra | Priced BOM |
| R11 | Be carried by two people | Complete size M frame kit, 50 kg (110 lb) or less; tarpaulins are issued separately from agency stock and not counted (restated 2026-10-02, SNF-DEC-001) | Met on paper: frame kit about 46.2 kg (59.9 kg with three tarpaulins) | Massing model, then weighing |
| R12 | Be repairable in the field | Any member or node replaced by hand in 5 min or less; four tube types and three node types only | Met: four tube types; three node types in four printed variants, none handed (one eave node with a blank capped socket at the corners, SNF-DDR-002 D9). Replacement time not verifiable at TRL 3 | Design review |
| R13 | Limit fire spread | Skin meets a recognized flame spread test for tents (for example CPAI-84) or the kit ships with a fire-retardant tarpaulin option | **Not met** with standard polyethylene relief tarpaulins, which are usually not flame retardant | Material data for the chosen tarpaulin |

## Assumptions

- Reference size M (SNF-DDR-001 D6): 4.0 x 4.0 m floor, two 2.0 m bays, eave 1.8 m, ridge 2.6 m (roof pitch 21.8°), three gable frames.
- Tube (SNF-DDR-001 D2, SNF-DDR-002 D8): 1 in EMT rafters and ridge tubes (OD 29.54 mm, wall 1.448 mm, 1.003 kg/m) and 3/4 in EMT posts and eave tubes (OD 23.42 mm, wall 1.245 mm, 0.681 kg/m), ANSI C80.3 nominal dimensions. Yield strength assumed 275 MPa, to be confirmed from supplier data.
- Wind: q = ½ρv² with ρ = 1.225 kg/m³; windward wall +0.8, leeward wall -0.5, roof suction -0.7 (first-order values in the style of ASCE/SEI 7, not a code check). Each tarpaulin panel shares its load between its four edge members by 45° tributary lines. See SNF-CAL-001 for the full list.
- Members are treated as simply supported between node centers; node fixity is ignored, which is conservative for bending. The frame analysis of the middle frame (SNF-CAL-001 v0.6) keeps pinned knees as its design basis and shows rigid knees only as a bound.
- Snow and cyclone rating are out of scope for the first release (SNF-DDR-001 D7).
- Value-engineering target: $445 is the `budget_usd` in `project.yaml` (raised from $400 when Amish approved the budget on 2026-09-26), applied to one size M frame kit including anchors, cables, cable bolt sets and bags, and excluding tarpaulins (SNF-DDR-001 D1). It is a hypothetical control target, not a limit (Amish, 2026-10-01).

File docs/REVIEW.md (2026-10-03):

# Review note: SnapFrame

## Session 2026-09-25: /populate to a strong TRL 2

### What was done

- `docs/01-problem.md` (SNF-PRB-001 v0.2): problem, users (displaced households, agency shelter teams, local fabricators, transitional shelter, public buildings), constraints, out of scope, prior work with sources, open questions; co-design checklist added in the portfolio's standard form (the scaffold had none).
- `docs/03-requirements.md` (SNF-REQ-001 v0.2): 13 measurable requirements (R1 to R13) with targets, estimated status and assumptions.
- `docs/02-concept.md` (SNF-PRC-001 v0.2): how it works, numbered components, node concept, size family (S, M, L), first-order numbers (geometry, mass, cost, wind, anchors, snow), design choices, safety, open questions.
- `cad/src/concept_media.py`: massing model of size M (18 EMT members, 15 nodes, 10 brace cables, 8 screw anchors, 2 guy lines, tarpaulin skin on the rear bay), each part carrying its BOM number. Hero uses a ground patch and a 1.75 m person as context parts so the below-ground anchors do not shift the figure's floor.
- `media/`: `hero.png`, `concept-blueprint.png`, `.pdf` and `.svg`, `exploded.png` with callouts 1 to 10, `model.glb` and `viewer.html`. Temporary `_views` folders deleted.
- `bom/bom.csv`: 13 lines with indicative prices, numbered to match the exploded view; `bom/bom-notes.md` updated with totals.
- `README.md`: hero image and links line before "## Problem"; problem, concept, key components and safety brought in line with the concept.
- `docs/pdf/`: branded PDFs of the three controlled documents.

### Key results (estimates, to be checked at TRL 3)

| Quantity | Estimate | Requirement |
| --- | --- | --- |
| Floor, size M | 4.0 x 4.0 m, 16 m² (four people at 3.5 m²) | R1 met |
| Headroom 2.0 m or more | 75 % of floor | R2 met |
| Members, nodes | 18 tubes (4 types), 15 nodes (3 types) | R12 met |
| Longest member, packages | 2.06 m; tube bundle about 24 kg, bag about 21 kg | R5 met |
| Kit mass | about 45 kg | R11 met |
| Erection time, two adults | about 40 min | R4 unverified |
| Rafter safety factor at 20 m/s gusts, 3/4 in EMT | about 1.26 (218 MPa against assumed 275 MPa yield) | **R6 not met** |
| Wind rating with 3/4 in rafters | about 18 m/s (65 km/h, 41 mph) | |
| Rafter safety factor at 20 m/s, 1 in EMT | about 2.4 | Would meet R6 |
| Skin area for full enclosure | about 51 m² against 48 m² from two tarpaulins | **R7 partly met** |
| Parts cost, complete kit | about $437 | **R10 not met, 9 % over** |
| Frame kit without tarpaulins | about $387 | Would meet R10 |
| Tube offcut | 39 % of 18 sticks bought | |
| Anchor uplift | up to about 0.6 kN per foot anchor, before pretension | R8 unverified (1.0 kN target) |

Requirements not met or at risk:

- **R6 (wind) not met:** 3/4 in rafters reach a factor of about 1.26 at 20 m/s; rating about 18 m/s.
- **R10 (cost) not met:** about $437 against $400.
- **R13 (fire) not met:** standard polyethylene relief tarpaulins are usually not flame retardant.
- **R7 (skin) partly met:** two tarpaulins close the roof, both side walls and one gable only.
- **R3 (sizes) partly met:** only size M is modeled; S and L are defined by parameters.
- **R4, R8, R9 unverified:** erection time, anchor holding and node material need data or trials.

### Proposed, awaiting Amish

1. **Budget (R10).** Options: (a) define the $400 as the frame kit and treat tarpaulins as agency stock (about $387, meets); (b) cut cost with bulk EMT or cheaper filament; (c) raise `budget_usd` to about $450. Recommendation: (a), reporting tarpaulin cost separately. `project.yaml` budget is unchanged.
2. **Rafter tube size (R6).** Options: 3/4 in everywhere with an 18 m/s rating; 1 in EMT rafters (about $30 more per kit, second socket bore); four frames at 1.33 m spacing. Recommendation: 1 in rafters.
3. **Node material and process.** Printed polymer first, cast aluminum from printed patterns later. Recommendation: print for the prototype, design for casting.
4. **Joint locking.** Spring buttons everywhere plus hitch pins at the 12 tension joints. Recommendation as stated.
5. **Frame form.** Gable with cable bracing, rather than a dome, barrel vault or rigid nodes. Recommendation: gable.
6. **Tube offcuts.** Accept 39 % offcut, shorten posts to 1.50 m (eave 1.65 m), or use 6 m metric stock. Recommendation: decide once the first region's tube source is known.
7. **Reference size and size family** (S 9 m², M 16 m², L 24 m²), with M as reference.
8. **Out of scope:** snow and cyclone rating in the first release.
9. **First partner and region** for co-design.

No change was made to `pitch` or `problem` in `project.yaml`; the numbers found do not contradict them.

### Safety concerns

- Frame collapse in wind above about 18 m/s, or under snow or ponded water; the frame is an emergency shelter, not a storm refuge.
- Fire: polyethylene tarpaulins burn and drip; cooking and open flames must stay outside.
- Pinch points while dropping tubes into sockets, sharp cut tube ends, trip hazards from guy lines, and buried services when turning in anchors.
- A conductive steel frame near mains cables, and no lightning protection.

### Problems and notes

- **Sources not re-verified this session.** Web search had reached its session limit and page fetches were blocked, so the citations in SNF-PRB-001 (IFRC, UNHCR, Sphere, Better Shelter, Desert Domes, ASCE) and the EMT dimensions and prices come from prior knowledge. Several links point to an organization's home page rather than the exact document. Check each figure and deep link before release.
- No cutaway: at shelter scale the section shows nothing that the hero and exploded views do not. The node interior matters, but belongs in a TRL 3 node drawing.
- No flow diagram: the concept does not move energy or material. A wind load path diagram could be added as a suggestion at TRL 3.
- The exploded view leaves out the skin (item 11) because it hid the frame; it is rendered with a kit helper called after `render_all`. Items 12 and 13 are not modeled.
- The legacy `cad/src/model.py` placeholder is untouched (TRL 3 work).

### Recommended next step

Review this note and the media, then decide items 1 and 2. If approved, run `/advance-trl3` to verify EMT properties and sources, do the wind and anchor calculation note, model the parametric nodes for S, M and L with STEP export, and produce the drawing sheet.

## Session 2026-09-25: TRL 3

Amish approved the TRL 2 review on 2026-09-25 ("proceed with all of your recommendations across all batches. Make sure we don't proceed to TRL 4 on any of them."). This session advanced SnapFrame to TRL 3 and stopped there.

### What was done

- `docs/decisions/0001-trl2-review-decisions.md` (SNF-DDR-001 v0.1): decisions D1 to D7 recorded as "Decided by Amish, 2026-09-25: go with recommendation"; items O1 to O3 left open.
- `docs/04-calcs/01-sizing.md` (SNF-CAL-001 v0.1) and `docs/04-calcs/sizing.py`: geometry, EMT sections, wind with 45° tributary load share, bracing, anchors, joints, node mass and cost, mass, packages, cost, skin and erection time, with a results table for R1 to R13. The script imports the CAD model and prints every number the note quotes.
- `cad/src/model.py`: parametric build123d model (sizes S, M, L; tube, node and anchor parameters). Exports `cad/step/snapframe-M-assembly.step`, `cad/step/snapframe-{S,M,L}-nodes.step` and 18 node STLs in `cad/stl/` (six variants per size).
- `cad/src/sheets.py` and `cad/drawings/SNF-DWG-001.svg`, `.pdf`, `.png`: general arrangement at Rev P1, 1:50, with node details and key dimensions; marked "CONCEPT, NOT FOR FABRICATION" and "PRELIMINARY, NOT FOR FABRICATION". The concept sheet keeps SNF-DWG-010, so DWG-001 was free.
- `bom/bom.csv` and `bom/bom-notes.md`: all 13 lines priced with supplier types; node prices from the model volumes.
- `cad/src/concept_media.py`: now built from `model.py`; `media/hero.png`, `exploded.png`, `concept-blueprint.*`, `model.glb` and `viewer.html` regenerated and checked. Temporary `_views` folders deleted.
- `docs/01-problem.md`, `docs/02-concept.md`, `docs/03-requirements.md` moved to v0.3; `README.md` and `project.yaml` (trl 3, trl_target 3, evidence list) updated. `pitch`, `problem` and `budget_usd` (400) are unchanged, as the TRL 2 review recommended.

### Requirements (SNF-CAL-001, size M)

4 met, 5 not met, 3 at risk, 1 not verifiable at TRL 3.

| ID | Value | Target | Status |
| --- | --- | --- | --- |
| R5 | Tube bundle 27.4 kg | 25 kg per package | **Not met** |
| R6 | Rating 17.8 m/s; ridge tube 1.18, post 1.46 at 20 m/s | Factor 1.5 at 20 m/s | **Not met** |
| R7 | One gable open (51.4 m² needed, 48 m² available) | Both gables closed | **Not met** (open item O3) |
| R10 | Frame kit $431 | $400, tarpaulins excluded | **Not met** (7.8 % over) |
| R13 | Standard polyethylene tarpaulins | Fire-retardant option | **Not met** |
| R8 | Anchor demand up to 1.28 kN | 1.0 kN per anchor | At risk |
| R9 | Pin bearing on polymer 32 MPa with factor 2 | Factor 2 at 70 °C after two years | At risk |
| R12 | Six printed node variants (handed corners) | Three node types | At risk |
| R4 | About 46 min estimated | 60 min | Not verifiable at TRL 3 |
| R1, R2, R3, R11 | 16.0 m²; 73 % headroom; S, M, L generated; 40.6 kg (49.8 kg with tarpaulins) | | Met |

Key finding: the TRL 2 wind estimate spread half of each tarpaulin panel uniformly over the frames. The 45° tributary rule used here peaks at midspan, so the 3/4 in ridge tubes (not the rafters) now govern, and 1 in rafters alone do not reach 20 m/s. With the open gable facing the wind, the rating falls to about 13.3 m/s. The TRL 2 figures in SNF-PRC-001 v0.2 (post factor 1.70, 18 m/s, $437 complete, 45 kg, 0.6 kN anchors) were replaced with the CAL values.

### Decisions recorded (SNF-DDR-001)

Decided by Amish, 2026-09-25, going with the recommendation: D1 budget covers the frame kit, tarpaulins are agency stock; D2 1 in EMT rafters; D3 print nodes, design for casting; D4 buttons plus hitch pins at 12 tension joints; D5 gable with cable bracing; D6 S, M, L with M as reference; D7 snow and cyclone out of scope.

### Still awaiting Amish

1. **O1 Tube offcuts** (39 %): the recommendation was to decide once the first region's tube source is known, so it stays open.
2. **O2 First co-design partner and region**: no recommendation.
3. **O3 Open gable (R7)**: no recommendation; the open gable also sets the 13.3 m/s open-door wind case.
4. **New, R6 wind.** Options: (a) 1 in ridge tubes as well (+2 sticks, about $10; rating 19.7 m/s, posts then govern); (b) 1 in ridge tubes and posts (about $40 more; 20.3 m/s); (c) keep D2 and rate the kit at 17.5 m/s. Recommendation: (a) now and a frame analysis before deciding on posts. Decided by Amish, 2026-09-25: go with recommendation (SNF-DDR-002 D8).
5. **New, R10 cost ($431).** Options: bulk EMT pricing, a lighter foot plate (foot nodes are $10.29 each), or raise `budget_usd`. No change was made. Decided by Amish, 2026-09-26: budget set to $445 (SNF-DDR-002 v0.2).
6. **New, R5 tube bundle (27.4 kg).** Options: two tube bundles (15.2 kg and 12.1 kg, three packages), or relax R5 to 30 kg for a two-person carry. Proposed, awaiting Amish.
7. **New, R12 node variants.** Using the four-socket middle eave node at the corners with one blank socket would remove the handed corner nodes. Decided by Amish, 2026-09-25: go with recommendation (SNF-DDR-002 D9).
8. **New, node polymer (R9)** and **R8 anchor target**: the 1.0 kN target is below the 1.28 kN calculated demand. Proposed, awaiting Amish.

### Safety concerns

- Frame collapse above about 17.8 m/s, or about 13 m/s with wind into the open gable; not a storm refuge. Snow at 0.5 kPa would yield a 1 in rafter.
- Fire: polyethylene tarpaulins burn and drip (R13 not met).
- Anchor pull-out at the rear corner feet under combined suction and cable forces (R8).
- Printed sockets at 70 °C in sun may lose strength at the hitch pins (R9).
- Pinch points, sharp tube ends, guy line trip hazards, buried services, a conductive frame near mains and no lightning protection, as before.

### Citations

Checked this session with web search and fetch: IFRC and ICRC shelter kit (two 4 x 6 m tarpaulins), UNHCR family tent (16 m² plus vestibules), Better Shelter RHU (17.5 m²; panel and frame life), Zurich 2015 fire concerns (Humanosphere), UNHCR shelter standards citing Sphere (3.5 m² per person), and EMT OD and ID (Engineering ToolBox). Links in SNF-PRB-001 now point to those pages. Not verified: the Domerama strut-flattening page (found by search, not fetched), the ASCE link (home page only), the 275 MPa EMT yield, the 8.0 kN wire rope rating and all prices.

### Problems and notes

- No TRL 4 material exists in the repo (`build-log/` holds only its README and `.gitkeep`).
- The model uses hollow tubes and bored sockets, so `concept_media.py` takes about 8 min to run.
- The exploded view leaves out the skin; items 12 and 13 are not modeled.

### Recommended next step

TRL 4 is on hold by Amish's instruction; do not start it. Next, Amish decides items 4 to 8 above, and SNF-CAL-001 is revised to v0.2 if the tube sizes change. For reference only, TRL 4 would need: a built frame kit and printed nodes, node and anchor load tests with a test report (TST, `environment: lab`), a timed erection with users, and build log entries.

## Session 2026-09-25: recommendations accepted

On 2026-09-25 Amish wrote: "i accept all your recommendations, go with them across all repos." Every item from the TRL 3 session that carried a recommendation is now "Decided by Amish, 2026-09-25: go with recommendation" and is recorded in `docs/decisions/0002-recommendations-accepted.md` (SNF-DDR-002 v0.1). Items without a recommendation stay "Proposed, awaiting Amish". The trl and trl_target stay at 3.

### Decisions applied and what changed

| # | Decision | Before | After |
| --- | --- | --- | --- |
| D8 (item 4, R6 wind) | Decided by Amish, 2026-09-25: go with recommendation. (a) 1 in EMT ridge tubes now; frame analysis before deciding on posts | 3/4 in ridge tubes; rating 17.8 m/s, ridge tube governs (factor 1.18); open-gable case 13.3 m/s | 1 in ridge tubes; rating 19.7 m/s, 3/4 in post governs (factor 1.46); ridge tube 2.22; open-gable case 14.7 m/s |
| D9 (item 7, R12 node variants) | Decided by Amish, 2026-09-25: go with recommendation. Four-socket eave node at the corners with one blank, capped socket | Six printed variants per size (handed corner eave nodes) | Four printed variants per size, none handed; R12 at risk to met |

Knock-on numbers, size M (SNF-CAL-001 v0.1 to v0.2): frame kit $431.09 to $443.30 (7.8 % to 10.8 % over the $400 budget); frame kit mass 40.6 to 42.0 kg; with tarpaulins 49.8 to 51.1 kg (R11 met to **not met**); tube bundle 27.4 to 28.6 kg; nodes 4.87 kg and $122.09 to 4.97 kg and $124.30. `budget_usd` stays 400 under SNF-DDR-001 D1; `pitch` and `problem` are unchanged because no accepted recommendation touched them.

Files changed: `cad/src/model.py` (1 in ridge tubes, single eave node), `cad/step/` and `cad/stl/` re-exported (the six `eave-corner-L/R` and three `eave-middle` STLs replaced by `snapframe-{S,M,L}-eave.stl`), `cad/src/sheets.py` and SNF-DWG-001 Rev P1 to P2, `docs/04-calcs/sizing.py` and SNF-CAL-001 v0.1 to v0.2, SNF-PRC-001 v0.3 to v0.4, SNF-REQ-001 v0.3 to v0.4, SNF-PRB-001 v0.3 to v0.4 (updated rating; MERO added to prior work), `bom/bom.csv` (items 3, 6, 7, 12) and `bom/bom-notes.md`, `cad/src/concept_media.py` and all of `media/`, `README.md` (numbers, and the new sections Concept rationale, Burning platform, Where it could be used and What sparked the idea), `project.yaml` (DDR-002 added to trl_evidence). All PDFs in `docs/pdf/`, the drawing and the concept media were regenerated so every footer shows designmolecule.com.

### Requirement status (SNF-CAL-001 v0.2, size M)

4 met, 6 not met, 2 at risk, 1 not verifiable at TRL 3 (was 4, 5, 3, 1).

| ID | Value | Target | Status |
| --- | --- | --- | --- |
| R5 | Tube bundle 28.6 kg | 25 kg per package | **Not met** |
| R6 | Rating 19.7 m/s; post 1.46 at 20 m/s | Factor 1.5 at 20 m/s | **Not met** (frame analysis pending) |
| R7 | One gable open (51.4 m² needed, 48 m² available) | Both gables closed | **Not met** |
| R10 | Frame kit $443 | $400, tarpaulins excluded | **Not met** (10.8 % over) |
| R11 | 51.1 kg with tarpaulins | 50 kg | **Not met** (new, from the 1 in ridge tubes) |
| R13 | Standard polyethylene tarpaulins | Fire-retardant option | **Not met** |
| R8 | Anchor demand up to 1.28 kN | 1.0 kN per anchor | At risk |
| R9 | Pin bearing on polymer 32 MPa with factor 2 | Factor 2 at 70 °C after two years | At risk |
| R4 | About 46 min estimated | 60 min | Not verifiable at TRL 3 |
| R1, R2, R3, R12 | 16.0 m²; 73 % headroom; S, M, L generated; four node variants, none handed | | Met |

### Still awaiting Amish

1. **O1 Tube offcuts** (39 %): decide once the first region's tube source is known.
2. **O2 First co-design partner and region**: no recommendation.
3. **O3 Open front gable (R7)**: no recommendation.
4. **O4 R10 cost ($443)**: bulk EMT pricing, a lighter foot plate, or raise `budget_usd`; no recommendation. Decided by Amish, 2026-09-26: budget set to $445 (SNF-DDR-002 v0.2).
5. **O5 R5 package and R11 carried mass**: two tube bundles (16.5 and 12.1 kg) or relax R5 to 30 kg; R11 is now 1.1 kg over and needs a choice too; no recommendation.
6. **O6 Node polymer (R9)** and **O7 R8 anchor target** (1.0 kN against 1.28 kN demand): no recommendation.
7. **O8 1 in posts**: per D8, after the frame analysis (20.3 m/s by member check, about $30 more).

### Cross-repo actions

None. No accepted recommendation for SnapFrame needs another repo to change.

### TRL 4

TRL 4 remains on hold by Amish's instruction. No build, test, purchasing or build-log material was created. The frame analysis that D8 calls for is TRL 3 paper work; it was not run in this session and is the recommended next step.

## Session 2026-09-26: sources strengthened

- **What sparked the idea (README):** the Wikipedia "Space frame" link (and the "first space truss system" claim it carried) was removed. The MERO account now rests on the company's own history page ([mero.de](https://mero.de/en/the-company/)), restated to what that page says (end of the 1930s, industrially prefabricated series elements), plus MERO Raumstruktur's patent [EP0475216B1](https://patents.google.com/patent/EP0475216B1/de) for the tubular rods and near-spherical node pieces.
- **`docs/01-problem.md` (SNF-PRB-001 v0.5):** the same MERO prior-work line now cites the patent for the tube and node description, since the MERO history page does not describe the nodes.
- `INSPIRATIONS.md`: the SnapFrame line now names the patent as a source. Country rows were already cited; no rows replaced. No budget change.

## Session 2026-09-26: budget approved

On 2026-09-26 Amish wrote: "i approve all the budget items." Open item O4 (R10 cost) is decided: budget set to $445 to cover the priced BOM, recorded in SNF-DDR-002 v0.2.

- `project.yaml`: `budget_usd` 400 to 445. The priced frame kit is $443.32 (tarpaulins excluded, SNF-DDR-001 D1), so the figure covers it.
- R10: **not met** (10.8 % over $400) to **met** ($1.70 under $445). Requirement status is now 5 met, 5 not met, 2 at risk and 1 not verifiable.
- `docs/04-calcs/sizing.py` now checks against $445 and was rerun; SNF-CAL-001 v0.3, SNF-REQ-001 v0.5, SNF-PRC-001 v0.5, SNF-PRB-001 v0.6, `README.md` and `bom/bom-notes.md` quote the new figure. The concept blueprint key figure now reads "budget $445", and `media/` was regenerated.
- Still awaiting Amish: O1 tube offcuts, O2 co-design partner, O3 open gable, O5 packages and carried mass, O6 node polymer, O7 anchor target, O8 1 in posts.

## Session 2026-09-26: product appearance model and photoreal renders

Amish chose this repo for the first batch of product renders on 2026-09-26. This session added `cad/src/product_model.py`, an appearance model of the size M frame for photoreal renders, and pointed the README hero image at `media/render-hero.png` with a link to `media/render-exploded.png`. The render files are produced later by the orchestrator.

What `product_model.py` adds:

- `product_parts()`: 144 parts in four groups (shell, internal, accessory, context), each with a colour, material, BOM line and exploded-view offset; `TITLE` and three `RENDER_VIEWS` (hero, exploded, detail).
- Galvanized EMT tubes with colour bands just outside each socket mouth, one colour per tube type (posts, rafters, ridge tubes, eave tubes), as the BOM's "color band at ends".
- The printed nodes from `model.node_variants()` in the kit teal, with fillets at the core-to-socket junctions, the socket mouths and the foot plate edges; grip ribs and a size mark on each foot plate.
- Stainless spring buttons showing in every tube socket hole, hitch pins with pull rings at the 12 tension joints, and ribbed push-in caps on the four blank corner eave sockets (item 12).
- Brace cables with hand cam tensioners and swaged sleeves, a snap hook on the front right corner eave node's cable tab, screw anchors at the feet, and guy lines with slide tensioners and reflective tape.
- Context: a compact soil plinth, one tarpaulin fitted over the rear bay with a hem and eyelets (agency stock, item 11, as in `concept_media.py`), and the shared clay mannequin standing beside the open front gable for scale.
- A "detail" view of one joint: the front right corner eave node and the ends of its post, rafter and eave tube, with buttons, hitch pin, cap and snap hook.

Places where the appearance model differs from `model.py`:

1. **Tube ends at the detail node.** The three tubes that meet the front right corner eave node are drawn as two pieces each, split 300 mm from the node centre, so the detail view can frame the joint alone. The joint between the two pieces is a flush butt that does not show in the renders; tube lengths and positions are unchanged. Proposed, awaiting Amish: keep the split as a render device. Recommendation: keep it; no document quotes it.
2. **Guy lines and guy anchors not in the hero.** They sit in the "accessory" group, so the hero shows the frame on a compact plinth; they appear in the exploded view. Proposed, awaiting Amish: accept the hero without guy lines, or add them and a wider plinth (the frame then fills less of the image). Recommendation: accept, with the hero caption saying guy lines are not shown.
3. **Appearance hardware not modeled in `model.py`.** Colour bands, spring buttons, hitch pins with rings, socket caps, cable tensioners, sleeves and snap hook, guy tensioners and foot plate ribs and marks are appearance additions with indicative sizes; the foot plate size mark and grip ribs are not in the BOM spec. Proposed, awaiting Amish: whether the foot plate ribs and size mark should become part of the node concept. Recommendation: keep them as appearance only until the node polymer (O6) is chosen.
4. **Brace cable at the detail node** starts 48 mm outside the node core rather than at the node centre, so it does not cross the snap hook in close-ups. Proposed, awaiting Amish. Recommendation: accept; the node-to-node cable length in SNF-CAL-001 is unchanged.

This is an appearance model only: no tolerances, no fabrication detail and no change to `model.py`, the BOM or the controlled documents. `trl` stays 3, and TRL 4 remains on hold.

## Session 2026-09-27: kit 1.5.0 and image quality

- Kit 1.5.0 synced: STANDARDS v1.5 (sections 12 to 15: product renders, storefront images and image quality, public release, authorship and signing), `.kit/cards.py`, `.kit/image_qc.py`, `.kit/release_gate.py`, issue templates, and the `/render-product` and `/release` commands. `CLAUDE.md` now matches `.kit/CLAUDE.md`.
- Every `media/render-*.png` recaptioned from its original render with the new layout: the title, concept label and repository sit in a band above the render and the view note in a band below it, each line wrapped to the image width, so no text overlaps other text or the render or runs off the image. `media/card.png` and `media/social-preview.png` regenerated with the same rules.
- `python .kit/image_qc.py` and `python .kit/release_gate.py` pass. trl stays 3.

## Session 2026-10-01: design for construction and illustrated build plan (BLD-001)

Kit 1.7.0 installed (`.kit/`, `.claude/commands/`, `CLAUDE.md`). Amish approved the build plan format on 2026-09-30 and asked for it across all repos, with outstanding decisions kept in a separate register; on 2026-10-01 he set `budget_usd` as a value-engineering target. This session made the SnapFrame design constructable, wrote the illustrated build plan and opened the design decisions register. No hardware was built; `trl` stays 3.

### What was done

- `cad/src/model.py`: constructable model with the bought hardware (snap buttons with their spring envelope, hitch pins, caps, cable bolt sets with rings, snap hooks, anchors turned down onto the plates) and 203 constructability checks (`python cad/src/model.py --check`): all 203 pass. STEP (`cad/step/`) and STL (`cad/stl/`) regenerated.
- `docs/decisions/0003-design-for-construction.md` (SNF-DDR-003 v0.1, Draft): every change, made under Amish's 2026-09-30 instruction to make the design physically buildable; open for his review.
- `docs/05-build-plan.md` (SNF-BLD-001 v0.1): plain-English build plan, components in build order, 13 assembly steps, first checks, safety stops, tools; no open decisions.
- `docs/06-design-decisions.md` (SNF-DEC-001 v0.1): 10 open decisions, 6 items to confirm when parts are bought, a value-engineering section and the decisions made with Amish's words.
- `cad/src/build_plan_media.py`: overview, nine making sketches `cad/drawings/SNF-DWG-101` to `109`, six joint close-ups, 13 step pictures and a cable make-up picture in `docs/05-build-plan/`.
- `docs/04-calcs/sizing.py` and SNF-CAL-001 v0.4 (cable bolt check, pin shear-out, cable lengths, mass and cost); SNF-REQ-001 v0.6; SNF-PRC-001 v0.6; `bom/bom.csv` (lines 1 to 10 and 12 updated, new line 14) and `bom/bom-notes.md`; SNF-DWG-001 Rev P4 (`cad/src/sheets.py`); concept media regenerated (`cad/src/concept_media.py`).
- `project.yaml`: `design_state: constructable`; DDR-003, the build plan, the register, the overview picture and the picture script added to `trl_evidence`. `budget_usd` unchanged (445). `README.md`: links line, value-engineering target in the header line, and a "Building the prototype" section before "Safety".

### Design changes made for construction (SNF-DDR-003)

1. **C1** Spring button moved from 25 to 40 mm and hitch pin from 50 to 15 mm from the tube end: the button's spring ran through the pin.
2. **C2** A 16 mm finger recess round every button hole and a 1.5 mm chamfer at every socket mouth: the button can be pressed by hand and rides in.
3. **C3** Printed cable and guy tabs replaced by a through-bolted stainless M10 cable bolt with a spacer and a welded 6 mm ring on every eave and ridge node (171 MPa in the shank, factor 2.6).
4. **C4** Lower cable ends clip to the anchor eyes at the feet.
5. **C5** Anchor eyes turned down onto the foot plates (they stood 32 mm clear).
6. **C6** Two anchor slots at 45° in the foot plate, so the gable cable clears the foot node; still one foot node, not handed.
7. **C7** Erection order: frames stand unanchored and slide 65 mm onto the eave and ridge tubes; anchors go in last (a 1,910 mm tube cannot fit between fixed sockets 1,780 mm apart).
8. **C8** Guy lines tie to the end ridge node rings.
9. **C9** One drilling rule: the two button holes of every tube on opposite sides of one marked line.

### Key results and requirements

- Frame kit 43.3 kg (was 42.0); 52.5 kg with tarpaulins, so R11 is **not met** by 2.5 kg (was 1.1 kg).
- Frame kit cost $469.14 against the $445 value-engineering target: $24.14 over (was $443.30). R10 is reported against the target.
- Not met: R5, R6, R7, R11, R13. At risk: R8, R9. Not verifiable: R4. Met: R1, R2, R3, R12.
- Wind, anchor and snow figures are unchanged; EMT shear-out behind the pin falls to 9.0 kN, seven times the 1.28 kN worst foot load.

### Proposed, awaiting Amish (all in SNF-DEC-001)

1. Accept the design for construction changes C1 to C9 (recommended).
2. A1: guiding the ridge tubes at 2.6 m during the slide-on (R4). Recommendation: from the ground with a spare tube, timed at TRL 4; the first prototype uses a step.
3. A2: the side wall tarpaulin passing the cables at the corner anchors; settle in the R7 tarpaulin plan (O3).
4. Carried over: O1 offcuts, O2 partner and region, O3 open gable, O5 packages and carried mass, O6 node polymer, O7 anchor target, O8 1 in posts, and the four appearance-model choices of 2026-09-26.

### Pictures and checks

- Every build plan picture, making sketch and the general arrangement was looked at one by one; leaders that pointed at the wrong part, labels sitting on lines, a duplicated footer on SNF-DWG-109, the general arrangement's isometric view running under its revision table and its title block date were fixed and redrawn. `python3 .kit/drawing.py --check-text` finds no overlapping text.
- Known limit: the title block of SNF-DWG-109 (cable make-up, not to scale) reads "1:1"; the kit's title block has no "not to scale" entry. The picture itself is labelled "Not to scale".
- PDFs of every controlled document are in `docs/pdf/`.
- Concept media regenerated from the constructable model (`media/hero.png`, `media/exploded.png`, `media/concept-blueprint.*`, `media/model.glb`). The cable bolts and rings roughly double the viewer model, to about 19.9 MB (was 9.4 MB); worth a coarser export setting if the website load time matters.

### Stale, to regenerate on Amish's Mac

- `media/render-hero.png`, `media/render-exploded.png`, `media/render-detail.png` (not in this cloud copy) and `media/card.png`, `media/social-preview.png` show the printed cable tabs, the old button and pin positions and the single anchor slot.
- `cad/src/product_model.py` still draws the concept tabs and the snap hook on the eave node tab; update it to the cable bolt, ring, anchor slots and new hole positions before re-rendering.

### Safety concerns

- Raising and joining frames: a standing frame is unbraced until step 9; one person holds it until the next frame is joined, and nobody works in strong wind.
- Tensioning cables: stand out of line with a cable; hand tension only.
- Anchors: check for buried services before turning one in.
- Printing ASA-class polymer gives off fumes; print in a ventilated space.
- The shelter safety notes (wind rating, snow, fire, lightning) are unchanged.

### Recommended next step

Amish reviews SNF-DDR-003, the illustrated plan and the register, and decides open decisions 1 and 2. The renders and `product_model.py` can then be brought up to the constructable design on his Mac. Building to the plan is TRL 4 work and stays on hold.

## Session 2026-10-02: open decisions decided

Amish approved every recommendation for the open decisions on 2026-10-02: "i approve your recommendations for all 555 open decisions."

### Decisions recorded

Ten, all moved to "Decisions made" in SNF-DEC-001 (open items 1 to 10): design for construction accepted (SNF-DDR-003, C1 to C9); a folding step for the first prototype, with ground guiding timed at TRL 4; the front gable closed with part of a third tarpaulin cut to include a door flap, and R7 restated; the frame analysis run now, with 1 in posts if it has not been run when the tubes are bought; two tube bundles, R5 restated as three packages and R11 counted on the frame kit alone; nodes in glass- or carbon-filled PA12-class nylon, PETG dropped; 1.5 kN anchors at the two rear corner feet; the 39 % offcut accepted for the prototype; the IFRC Shelter Research Unit as the first candidate to approach for a technical review and Field Ready for printing; the first three render choices accepted and the fourth withdrawn.

### Documents changed

- `docs/06-design-decisions.md` SNF-DEC-001 v0.2: decisions made; open decisions section now reads "None"; To confirm items 4 and 6 and the value engineering note updated.
- `docs/decisions/0003-design-for-construction.md` SNF-DDR-003 v0.2: accepted (status Draft kept); A1 sharpened, A2 as recommended.
- `docs/03-requirements.md` SNF-REQ-001 v0.7: R5, R7, R8 and R11 restated; R6 and R9 status notes; now 7 met, 2 not met (R6, R13), 2 at risk, 1 not verifiable.
- `docs/04-calcs/01-sizing.md` SNF-CAL-001 v0.5: status table and summary against the restated targets; polymer assumption noted; no figures changed.
- `docs/02-concept.md` SNF-PRC-001 v0.7 and `docs/01-problem.md` SNF-PRB-001 v0.7: skin, packages, polymer, anchors, posts, offcut and first candidate partners.
- `docs/05-build-plan.md` SNF-BLD-001 v0.2: node polymer, printer and fume notes.
- `README.md`: key components and summary name the third tarpaulin for the front gable.
- `bom/bom-notes.md`: offcut, polymer, anchors, step, bundles and third tarpaulin noted.

### Follow-up actions to carry approved decisions into the design

1. Decision 2 (BOM, pictures): add the folding step to the bill of materials for the first prototype and show it in steps 5 to 7.
2. Decision 3 (drawings, pictures): draw the cutting plan for three tarpaulins with the door flap and the corner cable hem; redraw step 13 and the skin in the model and concept media.
3. Decision 3 (BOM): tarpaulins line from two to three (agency stock, outside the frame kit), with its separate cost.
4. Decision 4 (calculations): run the frame analysis named in SNF-DDR-002 D8; if it has not been run when the prototype tubes are bought, change the posts to 1 in in the model, foot nodes, eave node post sockets and BOM.
5. Decision 5 (BOM, pictures): a second set of bundle straps (line 13) and the packing picture for two tube bundles.
6. Decision 6 (calculations, BOM): re-estimate node masses and print prices for filled PA12-class nylon (assumption A12, node lines of the BOM); add coupon tests for pin bearing at 70 °C to the TRL 4 plan.
7. Decision 7 (BOM, model): longer screw anchors at the two rear corner feet, rated 1.5 kN.
8. Decision 10 (pictures): re-render on Amish's Mac with the first three choices kept and the brace cable start at the detail node withdrawn.

### Points found in the review

- Five requirements are not met (R5, R6, R7, R11, R13); R13 (fire spread) has no open decision, though the problem statement asks whether partners stock a fire-retardant tarpaulin. It should be added to the register.
- Item 3 and item 5 interact: a third tarpaulin adds several kilograms to whatever carries it, which is why R11 is best counted on the frame kit alone.
- Cost is $469.14 against the $445 target, $24.14 over, and the frame analysis item may add about $30 more.

## Session 2026-10-02: approved follow-ups carried out

Amish approved on 2026-10-02 that every follow-up action from the open-decision sign-off be carried out. The eight follow-ups listed above were worked through; this section records them.

### Approved follow-ups carried out

1. Decision 2, folding step: done. Model part and checks (214 checks pass, was 203), BOM line 15 ($25.00, 1.5 kg), shown in steps 5 to 7 and the overview.
2. Decision 3, cutting plan: done. `cad/src/skin_plan.py` (19 checks), `docs/05-build-plan/cutting-plan.png`, build plan section 3.11, step 13 and the concept media redrawn with the front gable and door flap; corner cable hem 0.40 x 0.20 m settled (SNF-DDR-003 A2).
3. Decision 3, BOM: done. Tarpaulins line 11 from two to three ($75.00, outside the frame kit).
4. Decision 4, frame analysis: done. Section 5 of SNF-CAL-001 v0.6: windward post 1.43 at 20 m/s, rating 19.7 to 19.5 m/s. The analysis has been run, so the 1 in post fallback is not triggered and the posts stay 3/4 in. 1 in posts (20.3 m/s, about $30) are proposed in the register as open decision 12.
5. Decision 5, straps and packing: done. BOM line 13 now four straps ($26.00); `docs/05-build-plan/packing.png` and build plan section 3.12 (bundles 16.7 and 12.3 kg, bag 17.2 kg).
6. Decision 6, nodes in filled nylon: done for the re-estimate (A12: 5.34 kg and $316.16, was 4.76 kg and $119.74; BOM lines 5 to 7). Not done: coupon tests for pin bearing at 70 °C in the TRL 4 plan, because it is TRL 4 work.
7. Decision 7, long anchors: done. Model, BOM line 16 (two at $6.00, 560 mm, 1.5 kN), line 9 cut to six.
8. Decision 10, re-render: render scenes exported for Amish's Mac (hero, exploded, detail) from the updated appearance model; photoreal images, `card.png` and `social-preview.png` not regenerated, as instructed.

### Key results

- Requirement changes: R6 stays not met, rating 19.7 to 19.5 m/s. R7 from "met by area" to met, cutting plan drawn. R5 and R11 stay met (bundles 16.7 and 12.3 kg, bag 17.2 kg; frame kit 46.2 kg, was 43.3 kg). R8, R9 stay at risk. R10: frame kit $700.56, $255.56 over the $445 target (was $24.14); budget_usd unchanged.
- Cost basis: the nodes in filled nylon assume $55/kg, 1,200 kg/m3 and $1.50 a node, all indicative.
- Appearance model `cad/src/product_model.py` updated: front gable with rolled-up door flap, long rear anchors with the eye down on the plate, folding step in the exploded view.

### Documents changed

SNF-CAL-001 v0.6, SNF-REQ-001 v0.8, SNF-PRC-001 v0.8, SNF-BLD-001 v0.3, SNF-DEC-001 v0.3 (value engineering restated; open decisions 11 and 12 proposed, awaiting Amish), `bom/bom.csv`, `bom/bom-notes.md`, README, SNF-DWG-001 Rev P5, concept media (SNF-DWG-010 Rev P2), build plan pictures (overview, steps 5 to 8 and 13, SNF-DWG-101, 103, 105 and 106, cutting plan, packing).

### Decisions proposed and awaiting Amish

- Open decision 11: the $255.56 overrun from filled nylon nodes (recommended: print farm quote first).
- Open decision 12: 3/4 in or 1 in posts now that the analysis is run (recommended: keep 3/4 in, test knee fixity at TRL 4).

### Cross-repo actions

None for this repo.

### Recommended next step

Amish re-renders on his Mac from the exported scenes, and decides open decisions 11 and 12.

## 2026-10-02: photoreal renders redone on the constructable design

Rendered with Blender Cycles on Amish's Mac from the updated appearance model; captioned with `.kit/photo_caption.py`; `media/card.png` and `media/social-preview.png` regenerated with `.kit/cards.py`. Views: hero, exploded, detail. image_qc passes. Appearance deviations are those logged above as proposed, awaiting Amish.

## 2026-10-03: decisions recorded

Amish decided on 2026-10-03: "Cost over target - i accept all the cost variations and overruns". Recorded for this repo: the estimated cost of USD 700.56 against the USD 445 target (USD 255.56 over), with the nodes in filled nylon (open decision 11, option a).

- `docs/06-design-decisions.md`: row added to decisions made; value engineering section says the overrun was accepted by Amish on 2026-10-03.

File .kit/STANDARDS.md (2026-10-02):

---
doc_id: OHP-STD-001
title: Documentation and drawing standard
project: Open Hardware Portfolio
doc_type: Standard
version: "1.7"
status: Released
date: 2026-09-30
author: Amish Chadha
license: CC-BY-SA-4.0
revisions:
  - version: "1.0"
    date: 2026-09-24
    author: Amish Chadha
    change: First release of the standard
  - version: "1.1"
    date: 2026-09-24
    author: Amish Chadha
    change: Adopt Technology Readiness Levels (section 9) for project maturity
  - version: "1.2"
    date: 2026-09-24
    author: Amish Chadha
    change: Portfolio phase cap (section 10), concept media standard (section 11), CLAUDE.md guardrails
  - version: "1.3"
    date: 2026-09-24
    author: Amish Chadha
    change: Scale figure, interactive 3D viewer and flow diagrams added to concept media; session slash commands
  - version: "1.4"
    date: 2026-09-26
    author: Amish Chadha
    change: Every sheet and render names the project and its GitHub repository; overall dimensions, ISO centre lines and 300 dpi PNG on sheets; titles name the device and view labels state the viewing direction; optional photoreal renders with Blender
  - version: "1.5"
    date: 2026-09-27
    author: Amish Chadha
    change: Product renders (section 12), storefront images and image quality check (section 13), public release and release gate (section 14), authorship, citation and commit signing (section 15)
  - version: "1.6"
    date: 2026-09-29
    author: Amish Chadha
    change: Licensing metadata with REUSE (section 16), Zenodo DOI and Software Heritage archiving (section 17), release gate checks REUSE and a single CITATION.cff license, archive.py
  - version: "1.7"
    date: 2026-09-30
    author: Amish Chadha
    change: Concept and constructable design states; design decisions register (DEC) kept apart from the build plan; prototype build plan (BLD, section 18) with pictures by component is required TRL 3 evidence; every repo targets TRL 3 during the populate phase; build_views.py; /to-trl3 and /build-plan commands
---

# Documentation and drawing standard

Every project in the portfolio uses this standard, so that each precis, write-up and sketch looks the same and carries its own version history. The standard ships as a kit in each repo's `.kit/` folder. The kit version is in `.kit/KIT_VERSION`.

## 1. Document types and IDs

Every controlled document has a unique ID in the form `PRJ-TYP-NNN`.

- `PRJ` is the three-letter project code listed in section 7.
- `TYP` is the document type code from the table below.
- `NNN` is a sequence number within that project and type, starting at 001.

| Code | Type | Typical file |
| --- | --- | --- |
| PRC | Design precis | `docs/02-concept.md` |
| PRB | Problem statement | `docs/01-problem.md` |
| REQ | Requirements | `docs/03-requirements.md` |
| CAL | Calculation or sizing note | `docs/04-calcs/*.md` |
| DDR | Design decision record | `docs/decisions/*.md` |
| BOM | Bill of materials | `bom/bom.csv` |
| DWG | Drawing or sketch sheet | `cad/drawings/*.svg` |
| BLD | Prototype build plan (section 18) | `docs/05-build-plan.md` |
| DEC | Design decisions register (section 18) | `docs/06-design-decisions.md` |
| TST | Test plan or test report (front matter adds `environment: lab` or `relevant`) | `docs/05-tests/*.md` |

Example: `TBK-PRC-001` is the ThermaBrick design precis.

## 2. Revision scheme

| Artifact | While in draft | When released | Change after release |
| --- | --- | --- | --- |
| Documents | 0.1, 0.2, 0.3 ... | 1.0 | 1.1 for minor edits, 2.0 for a design change |
| Drawings | Rev P1, P2 ... (preliminary) | Rev A | Rev B, C ... |

- Every change to a controlled document adds a row to its revision history before the commit.
- The `version` field in front matter always equals the newest row in `revisions`. The renderer rejects a document where they differ.
- Status is one of `Draft`, `In review`, `Released` or `Superseded`. Draft and In review documents print with a status band on every page.
- Every release is tagged in Git as `<doc_id>/v<version>`, for example `TBK-PRC-001/v1.0`. Drawings are tagged `TBK-DWG-001/revA`.
- Git history is the full audit trail. The in-document revision table is the human-readable summary.

## 3. Document front matter

Every Markdown document under version control starts with this block:

```yaml
---
doc_id: TBK-PRC-001
title: ThermaBrick design precis
project: ThermaBrick
doc_type: Precis
version: "0.1"
status: Draft
date: 2026-09-24
author: Amish Chadha
license: CERN-OHL-S-2.0
revisions:
  - version: "0.1"
    date: 2026-09-24
    author: Amish Chadha
    change: Initial draft
---
```

Quote version numbers so YAML keeps `1.0` as text instead of turning it into a number. List revisions newest last.

## 4. Writing style

- Chicago Manual of Style.
- No em dashes. Restructure the sentence instead.
- Lead each section with its conclusion, then support it.
- SI units throughout, in the form `12 kW`, `450 °C`, `3.2 m`. Imperial values may follow in parentheses.
- Number every figure and table ("Figure 2", "Table 1") and give each a caption.
- State every assumption in the calculation that depends on it.
- Put safety notes in a blockquote starting with **Safety:**.

## 5. Visual identity

| Element | Specification |
| --- | --- |
| Typeface | IBM Plex Sans for text, IBM Plex Mono for code and values (SIL Open Font License, bundled in `.kit/fonts`) |
| Ink | `#111827` |
| Secondary text | `#4B5563` |
| Rules and grid | `#D1D5DB` |
| Accent (one only) | `#0F766E` teal |
| Document page | US Letter, 20 mm margins |
| Drawing sheet | ANSI B landscape (431.8 x 279.4 mm) |
| Footer | Document ID, version, status, license and designmolecule.com on every page |

## 6. Drawing and sketch conventions

- Units are millimeters unless the title block says otherwise.
- Third-angle projection, marked with the symbol in the title block.
- Line weights: visible outlines 0.5 mm, hidden lines 0.25 mm dashed, center lines 0.18 mm chain.
- The title block contains the project, title, drawing number, revision, scale, units, projection, sheet, author, date, material or notes, and license.
- Every sheet and every render names the project and its GitHub repository (from `repo:` in `project.yaml`), at the top of the sheet and in the title block, so a printed or forwarded sheet is never anonymous.
- The drawing title names the device, not only the drawing type (for example "Handheld near-infrared resin scanner: general arrangement").
- Every view label states its scale and viewing direction (for example "Scale 1:1; side elevation looking along +Y"), and every isometric or render states where it is seen from.
- Orthographic views generated with `add_ortho` carry overall dimensions (length and depth on the top view, height on the front view) and ISO 128 centre lines on cylinders; hidden lines are dashed. Tolerances are not shown before TRL 4.
- Sheets are exported as SVG, PDF and a 300 dpi PNG.
- The revision table in the top right of the sheet lists every revision.
- Concept sketches use the same sheet and title block and carry the label "CONCEPT, NOT FOR FABRICATION".
- Geometry comes from `cad/src/*.py` (build123d). Sheets are generated by `.kit/drawing.py` and never edited by hand.

## 7. Project codes

| Code | Project | Code | Project | Code | Project |
| --- | --- | --- | --- | --- | --- |
| TBK | ThermaBrick | PCF | PicoFlow | HLT | HelioLite |
| CCB | CharCube | DRN | DustRunner | TRT | TremorTrace |
| STC | StepCue | FXH | FlexHand | CPD | ColdPod |
| SCL | SunClave | STR | SteamRoot | GGD | GrainGuard |
| SDL | SeedLine | ZBX | ZeerBox | RMS | RootMesh |
| DWD | DewDrive | SSK | StillStack | PPR | PotPress |
| WWT | WaterWatch | LMF | LumaFlow | FCL | FieldCell |
| CNP | ConePro | CVC | CulvertCrawl | EGD | EmberGuard |
| SNF | SnapFrame | CGM | CargoMule | SCM | StepClimber |
| SWC | SwapCell | PLP | PalletPilot | FTK | FlatTrike |
| WWK | WaterWalker | GRR | GrowRider | SSP | SunSpoke |
| SGN | StepGen | PBX | PowerBox | WML | WasteWise-ml |
| WSC | WasteWise Scan | RFE | ReflowEconomy | | |
| OHP | Portfolio-wide | | | | |

## 8. Build and publish

- `python .kit/render.py` checks every controlled document and renders it to `docs/pdf/<doc_id>_v<version>.pdf`.
- `python .kit/drawing.py` (called from each project's `cad/src/sheets.py`) builds drawing sheets as SVG and PDF in `cad/drawings/`.
- The GitHub Action in `.github/workflows/docs.yml` runs the checks on every push and attaches PDFs to a GitHub Release whenever a release tag is pushed.
- Public releases follow section 14: `python .kit/release_gate.py` must pass, and the release tag is `v0.<TRL>.0` (for example `v0.3.0` at TRL 3).

## 9. Technology Readiness Level (TRL)

Each project states its maturity as a Technology Readiness Level on the NASA and US DOE 1 to 9 scale. The TRL rates this specific design, not the underlying technology. A sand battery is commercial elsewhere, but a new sand battery design starts at TRL 2 until evidence shows otherwise.

| TRL | Definition | Evidence the repo must contain |
| --- | --- | --- |
| 1 | Basic principles observed | Problem statement (PRB) |
| 2 | Technology concept formulated | Draft precis (PRC) and requirements (REQ) |
| 3 | Analytical or experimental proof of concept | Calculation note (CAL), working build123d model with STEP export, drawing sheet (DWG), priced BOM with every unit cost filled in, prototype build plan (BLD) with pictures, `design_state: constructable` |
| 4 | Components validated in the lab | Test report (TST) with `environment: lab`, build log entries |
| 5 | Validated in a relevant environment | Test report (TST) with `environment: relevant` |
| 6 | System prototype demonstrated in a relevant environment | Precis at version 1.0 or later with status Released, a drawing at a lettered revision (Rev A or later), and a system-level TST with `environment: relevant` |
| 7 to 9 | Operational demonstration through proven in service | Beyond portfolio scope; claim only with a named deployment partner and evidence |

Rules:

- `project.yaml` records `trl` (current level), `trl_target` (the level the current effort aims for) and `trl_evidence` (the files that support the claim).
- `python .kit/render.py --check` fails if the evidence for the claimed TRL is missing. CI runs this check on every push.
- Documentation alone cannot go past TRL 3. TRL 4 and above require hardware and a test report.
- TRL and visibility are independent. A repo can be public at TRL 3 as a documented design ready to build.
- A change of TRL is recorded in the build log with the date and the evidence that justified it.

## 10. Portfolio phase and TRL cap

`.kit/PHASE.yaml` sets the current phase. During the **populate** phase every repo is capped at **TRL 3**: `trl` and `trl_target` may not exceed 3, and the check fails if they do. Every repo targets the cap: `trl_target` must equal 3, so a new repo is taken all the way to TRL 3 (scaffold, populate and advance, see `/to-trl3`). Work that belongs to TRL 4 or later (building or testing hardware, test articles, test plans and reports, build-log entries, purchasing lists, PCB layouts) must not be started. The prototype build plan (BLD, section 18) is TRL 3 paper work and is required. Where it already exists it is kept, flagged in the check output, and not extended. Only Amish changes `PHASE.yaml`.

Every repo carries a `CLAUDE.md` with the working rules for AI sessions: the TRL cap, decision rights (nothing is recorded as decided unless Amish decided it), one step per session, and a mandatory `docs/REVIEW.md` before stopping.

## 11. Concept media

Every repo at TRL 2 or above explains its idea visually. Media are generated from a build123d massing model with `.kit/concept.py`, never drawn by hand, so they stay in step with the design.

| File | Required | Purpose |
| --- | --- | --- |
| `media/hero.png` | TRL 2+ | Shaded isometric render with a 1.75 m person for scale; the website card image |
| `media/concept-blueprint.png` and `.pdf` | TRL 2+ | Blueprint concept sheet: orthographic and isometric views, scale, key figures, title block |
| `media/model.glb` and `media/viewer.html` | TRL 2+ | Interactive 3D viewer (glTF plus model-viewer) for the website |
| `media/cutaway.png` | When the inside matters | Section view showing internal parts |
| `media/exploded.png` | Recommended | Exploded view with numbered callouts matching the BOM |
| `media/flow.png` | When energy or material moves | System, energy or material flow diagram with losses |

Session commands in `.claude/commands/` (`/populate`, `/advance-trl3`, `/rein-in`, `/refresh-media`) carry the standard prompts, so every Claude Code session starts from the same instructions.

At TRL 2 a massing model is enough: correct overall proportions and main components. All concept media carry "CONCEPT, NOT FOR FABRICATION". The check warns when required media are missing at TRL 2 and fails at TRL 3.

## 12. Product renders

Every repo at TRL 3 shows the product as it would look, not only as a massing model.

- `cad/src/product_model.py` is the appearance model. It defines `product_parts()` (named parts with a shape and a material), `TITLE` ("Name: what it is") and `RENDER_VIEWS`. It is for renders only: every main dimension comes from `cad/src/model.py`, never typed in again.
- Where the appearance model departs from `model.py` (a chamfer, a label, a fastener drawn for realism), record the deviation in `docs/REVIEW.md` as "Proposed, awaiting Amish".
- Scale comes from context, not from a floating figure: a hand or forearm for handheld objects, and the posed mannequin (`mannequin()` in `.kit/context_parts.py`: stand, walk, push, ride, sit, reach) for anything a person uses at body scale.
- Renders are made with `.kit/export_views.py` (one scene per view) and `.kit/photoreal.py` (Blender Cycles), then captioned with `.kit/photo_caption.py`. Files are `media/render-<view>.png`; `media/render-hero.png` is required.
- Every caption names the project, the repository and the viewing direction, and carries "CONCEPT, NOT FOR FABRICATION".
- Captions never sit on the render. `.kit/photo_caption.py` adds a header band (title, concept label, repository) above the render and a footer band (view note) below it, wraps every line to the image width, and steps the font down to a floor before adding a line.
- The README opens with `media/render-hero.png`.
- Software-only and scene repositories (no single product) may use a scene render as the hero instead of a product model.

## 13. Storefront images

Two images, both made from `media/render-hero.png` by `python .kit/cards.py .`:

| File | Size | Purpose |
| --- | --- | --- |
| `media/card.png` | 800 x 800 | Square thumbnail for the organization profile page |
| `media/social-preview.png` | 1280 x 640, under 1 MB | GitHub social preview, shown when a repository link is shared |

- The social preview shows the area, name, one-line description, the first sentence of the pitch, the brand line and the repository address. Design Molecule repos read "Design Molecule · open hardware concept, TRL n"; OpenRatio repos read "OpenRatio · research and educational prototype, TRL n".
- GitHub has no API for the social preview. Upload it under the repository's Settings, Social preview, on release day.
- Regenerate both images whenever `render-hero.png` changes.

### Image quality

Every render, card and social preview must be clear and readable. `python .kit/image_qc.py` checks each one, and the release gate blocks on any failure:

| Check | Rule |
| --- | --- |
| Layout | Made by the current `photo_caption.py` or `cards.py`, which store the text layout in the PNG |
| Text inside the image | Every line at least 1.2 % of the image width from each edge; nothing runs off the side |
| No overlap | No line of text touches another line, and no caption text sits on the render |
| Text size | Render captions at least 1.05 % of the image width in pixel height (17 px at 1600 px); social preview text at least 16 px |
| Resolution | Renders at least 1200 px wide; card 800 x 800; social preview 1280 x 640 and under 1 MB |
| Sharpness | The render is not blurred or upscaled (edge sharpness at least 15 on the `image_qc.py` scale) |

Long titles and notes wrap to more lines rather than shrinking below the floor. The social preview shortens the pitch sentence with an ellipsis only if it cannot fit at the smallest size.

## 14. Public release

A repository goes public only when Amish approves it, and only after `python .kit/release_gate.py` passes. The gate checks:

1. `render.py --check` passes (document control, TRL cap, concept media).
2. Storefront: hero render, card, social preview under 1 MB, README leading with the hero, and every image passing the image quality check (section 13).
3. Issue templates in `.github/ISSUE_TEMPLATE/`: question, build report, design suggestion. The build report template restates that the design is a TRL 3 concept, not released for fabrication (OpenRatio: a research and educational prototype, not a medical device).
4. `CITATION.cff` valid, with an author ORCID.
5. License files match `project.yaml`.
6. No em dashes in the repository's own text.
7. BioMedical and OpenRatio repos use soft, non-clinical wording: "research and educational prototype, not a medical device".
8. No secrets anywhere in the history (gitleaks).
9. No links to sibling repositories that are still private.
10. REUSE files present (`REUSE.toml`, `LICENSES/`, `.github/workflows/reuse.yml`) and `reuse lint` passes (section 16).
11. `CITATION.cff` names exactly one license, because Zenodo rejects a list (section 17).

It warns, without blocking, when the README lacks a Safety heading or a "not for fabrication" statement, when `CITATION.cff` has no DOI yet, and when the README lacks the Zenodo DOI, REUSE or Software Heritage badge, so a person can confirm.

On release day, per repository:

- A signed, annotated tag `v0.<TRL>.0` on `main`.
- A GitHub release with short notes (what it is, TRL, status, licenses, how to cite) and a design pack, `<repo>-v0.<TRL>.0-design-pack.zip`, holding `cad/step`, `cad/drawings`, `docs/pdf`, `bom`, README, licenses and `CITATION.cff`.
- Description from the first sentences of `pitch` (350 characters at most), website `https://designmolecule.com` (OpenRatio: `https://openratio.ai`), topics from `project.yaml`.
- Before the first release, the repository is switched on in Zenodo (section 17), so the release is archived and gets a DOI.
- Visibility switched to public last, after the release exists.
- The social preview uploaded and the organization profile updated with the new cards.
- After the release: the concept DOI written to `CITATION.cff` and a Software Heritage save requested (section 17).

The internal working files (`CLAUDE.md`, `.kit/CLAUDE.md`, `.claude/commands/`, `docs/REVIEW.md`) stay public, and open "Proposed, awaiting Amish" items stay visible as open questions (Amish, 2026-09-27).

## 15. Authorship, citation and signing

- Amish Chadha is the author of every design, ORCID 0009-0000-8079-7141. Commits are authored as Amish Chadha <amish@designmolecule.com>.
- `CITATION.cff` lists Amish (with ORCID) first, then any credited contributors; `CONTRIBUTORS.md` and the README Credits section agree with it.
- `CITATION.cff` names one license: the hardware license (CERN-OHL-S-2.0), or the software license in a software-only repository. The full split between hardware and software licenses lives in `REUSE.toml` and the README. Once the repository is archived, `CITATION.cff` carries the concept DOI in `doi:`.
- Work done with Claude carries the trailer `Co-Authored-By: Claude <noreply@anthropic.com>` (with the model name), and the README Credits section says designs are developed with AI assistance.
- Every commit and tag pushed to GitHub is signed with Amish's SSH signing key, so GitHub shows it as Verified. Commits prepared elsewhere are re-signed on Amish's Mac before they are pushed.
- Once a repository is public, its history is never rewritten.

## 16. Licensing metadata (REUSE)

Every file states its copyright and license in a machine-readable way, following the REUSE Specification 3.3 (https://reuse.software). A repository is set up with:

```
python .kit/archive.py reuse
```

This writes three things and adds the REUSE and Software Heritage badges to the README badge line:

- `REUSE.toml`, built from the licenses in `project.yaml`. Everything is under the hardware license by default. Scripts, firmware, notebooks, web viewers, workflows and agent commands are under the software license. `cad/` and `electronics/` stay under the hardware license even where they are written as Python. The bundled IBM Plex fonts are OFL-1.1 (IBM Corp.). Copyright is "<first commit year> Amish Chadha".
- `LICENSES/`, with the full text of each license used (`reuse download`). The root `LICENSE` and `LICENSE-SOFTWARE` files stay for GitHub's license detection.
- `.github/workflows/reuse.yml`, which runs the REUSE check (fsfe/reuse-action) on every push and drives the README badge.

A new kind of file that falls outside these rules gets a new annotation in `REUSE.toml` rather than a header comment. `reuse lint` must pass before every commit that adds files, and the release gate enforces it.

## 17. Archiving and DOI (Zenodo and Software Heritage)

Every public repository is archived twice, so the design stays citable and retrievable if GitHub changes.

Zenodo (a citable DOI for each release):

1. Amish's Zenodo account is linked to GitHub. Before the first release, Amish switches the repository on in Zenodo (Account, GitHub). Only Amish changes Zenodo or GitHub settings.
2. Run `python .kit/archive.py zenodo`: it makes sure `CITATION.cff` names one license and adds the Zenodo DOI badge, which uses the GitHub repository ID and always points at the latest version. Zenodo reads its metadata (title, authors with ORCID, license, keywords) from `CITATION.cff`, and rejects the whole archive when that file lists several licenses.
3. Publish the GitHub release (section 14). Zenodo archives it within minutes and mints two DOIs: a version DOI for that release and a concept DOI that stands for all versions.
4. Check the Zenodo record: title, author and ORCID, license, keywords. If Zenodo shows "Citation metadata load failed", fix `CITATION.cff`, validate it with cffconvert and publish a new patch release (for example `v0.3.2`); a failed release is never re-used.
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

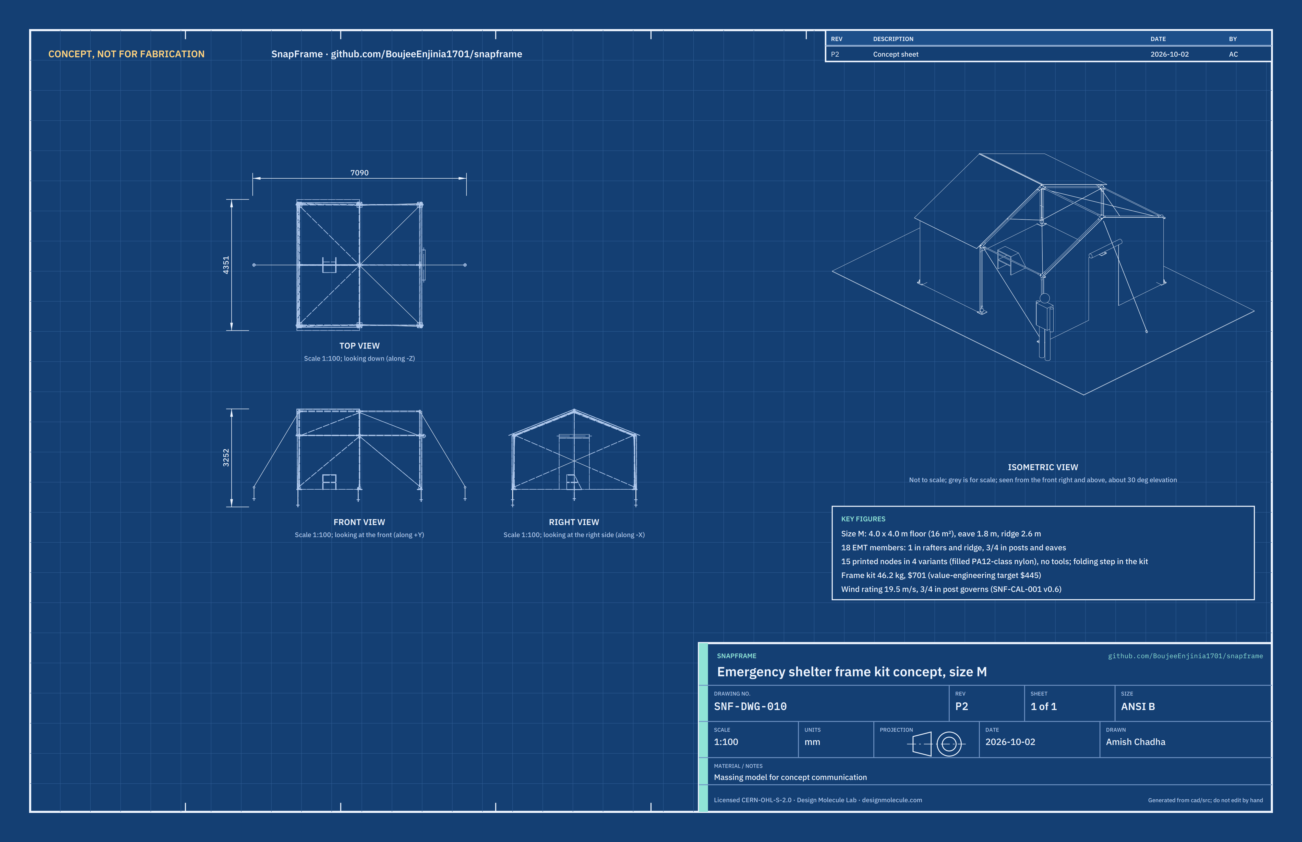
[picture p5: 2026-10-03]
media/concept-blueprint.png

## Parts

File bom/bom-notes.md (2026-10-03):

# BOM notes

Costs are indicative prototype prices for one size M kit (September 2026 estimates), not quotes. Line numbers match the callouts in `media/exploded.png`, Table 1 of SNF-PRC-001 and drawing SNF-DWG-001. Node prices come from the model volumes in SNF-CAL-001 v0.6: filled PA12-class nylon at 1,200 kg/m3 and 55 % effective fill, filament at $55/kg plus $1.50 machine time and hardened nozzle wear per node.

- Frame kit (every line except item 11): **$700.57**. Value-engineering target: USD 445 (`budget_usd`, a hypothetical control target, not a limit). Estimated cost of the constructable design: USD 700.57 (USD 255.57 over the target). SNF-CAL-001 v0.6 quotes $700.56; the 1 cent difference comes from rounding node prices to the cent here.
- Carried out on 2026-10-02 from the decisions of that day (SNF-DEC-001), the frame kit rose from $469.13 to $700.57: lines 5 to 7, the nodes, repriced for filled nylon ($13.09 a node on average, of which $0.50 is machine time; $196.42 in all); new line 15, the folding step ($25.00); new line 16, two long rear corner anchors ($12.00) with line 9 cut from eight anchors to six ($8.00 less); line 13 now four cam straps, two for each tube bundle ($26.00, was $20.00).
- Design for construction (SNF-DDR-003, 2026-10-01) had changed the frame kit from $443.32 to $469.13: new line 14, nine cable bolt sets with rings ($23.40); line 8 now has a snap hook at each end, a thimble and clips ($4.20 a cable, was $3.50); lines 5 to 7 repriced from the new node volumes (printed tabs removed, finger recesses and bolt holes added: $4.56 less in all).
- Tarpaulins (item 11, three at $25): $75.00, from agency stock and outside the frame kit (SNF-DDR-001 D1). Two cover the roof, side walls and rear gable and the third is cut for the front gable with a door flap; the cutting plan is in docs/05-build-plan.md section 3.11.
- All 16 lines: $775.57.
- Price bases: the folding step ($25.00) is an indicative retail price for a light two-step folding step of about 1.5 kg; the long anchor ($6.00) scales the $4.00 standard anchor by length (560/380 x $4.00 = $5.89); the two extra cam straps are about $3.00 each; the nylon filament price and density are indicative until a print farm quotes (open decision 11 in SNF-DEC-001).
- Tube is priced per 3.05 m (10 ft) stick, one member per stick: 10 sticks of 3/4 in at $9.00 and 8 sticks of 1 in at $14.00. About 39 % of the tube bought is offcut; accepted for the prototype on US 10 ft stock on 2026-10-02, with 1.50 m posts or 6 m metric stock chosen once the first region's tube source is known (SNF-DEC-001). The posts stay 3/4 in: the frame analysis was run (SNF-CAL-001 v0.6); 1 in posts would add about $30 (open decision 12).
- The four push-in caps for the blank corner eave sockets are included in item 12 at no extra line cost.
- Items to confirm when buying (snap button spring length, snap hook gate opening, ring and tensioner ratings, anchor eye size, the 1.5 kN rating of the long anchors, the filled nylon quote) are listed in the design decisions register, SNF-DEC-001.
- Mass: frame kit 46.2 kg (SNF-CAL-001 v0.6), in two tube bundles of 16.7 and 12.3 kg and a bag of 17.2 kg; the three tarpaulins add 13.7 kg.

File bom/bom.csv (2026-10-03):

item | qty | spec | supplier | unit_cost_usd | make_buy | notes
1 EMT post | 6 | 3/4 in EMT (ANSI C80.3, OD 23.42 mm, wall 1.245 mm), cut to 1650 mm, deburred; 6 mm button hole 40 mm from each end, the two on opposite sides of the tube; 8 mm hitch pin hole through both walls 15 mm from each end, on the same line; color band at ends; 3/4 in snap button in each end | Hardware store or electrical wholesaler | 9.00 | buy | Indicative price per 3.05 m (10 ft) stick; one member per stick; offcut 1.40 m; hole layout per SNF-DDR-003 C1 and C9 (SNF-DWG-102)
2 EMT rafter | 6 | 1 in EMT (ANSI C80.3, OD 29.54 mm, wall 1.448 mm), cut to 2064 mm, deburred; 6 mm button hole 40 mm from each end on opposite sides; no pin holes; color band at ends; 1 in snap button in each end | Hardware store or electrical wholesaler | 14.00 | buy | Indicative price per 3.05 m stick; 1 in rafters per SNF-DDR-001 D2 (SNF-DWG-104)
3 EMT ridge tube | 2 | 1 in EMT (ANSI C80.3, OD 29.54 mm, wall 1.448 mm), cut to 1910 mm, drilled as item 2, color banded | Hardware store or electrical wholesaler | 14.00 | buy | Indicative price per 3.05 m stick; 1 in ridge tubes per SNF-DDR-002 D8 (SNF-DWG-108)
4 EMT eave tube | 4 | 3/4 in EMT cut to 1910 mm, drilled as item 2 (no pin holes), color banded | Hardware store or electrical wholesaler | 9.00 | buy | Indicative price per stick (SNF-DWG-107)
5 Foot node | 6 | Printed node: 84 mm core, one 24.0 mm bore socket 110 mm long with flat stop, mouth chamfer, 6 mm button hole in a 16 mm finger recess and 8 mm pin hole; 170 x 170 x 12 mm plate with two 18 mm anchor slots at 45 degrees open to the corners; model volume 697 cm3, about 460 g at 55 % fill in filled PA12-class nylon | Local print farm or makerspace | 26.81 | make | Filled PA12-class nylon (glass- or carbon-filled, decided 2026-10-02, SNF-DEC-001) at 1,200 kg/m3 and 55 % effective fill; price basis: filament $55/kg plus $1.50 machine time and hardened nozzle wear per node (SNF-CAL-001 v0.6, A12); castable in aluminum later (SNF-DWG-101)
6 Eave node | 6 | Printed node, one variant for all six: 84 mm core, 24.0 mm bores for the post and two eave tubes, 30.1 mm bore for the rafter, each with flat stop, mouth chamfer and button hole in a finger recess; 10.5 mm cable bolt hole with spot face and nut recess; at the four corners the socket past the gable stays blank and takes a push-in cap; model volume 434 cm3, about 287 g in filled PA12-class nylon | Local print farm or makerspace | 17.27 | make | One variant replaces the handed corner nodes (SNF-DDR-002 D9); cable bolt, item 14 (SNF-DDR-003 C3; SNF-DWG-103); price basis as item 5 (filament $55/kg plus $1.50, 1,200 kg/m3, 55 % fill)
7 Ridge node | 3 | Printed node: 84 mm core, two 30.1 mm rafter bores, one or two 30.1 mm ridge bores, flat stops, mouth chamfers, button holes in finger recesses; 10.5 mm cable bolt hole straight down; about 277 to 304 g in filled PA12-class nylon | Local print farm or makerspace | 17.23 | make | Mean of end ($16.72) and middle ($18.25) variants (SNF-CAL-001 v0.6); cable bolt, item 14 (SNF-DWG-105, 106); price basis as item 5
8 Brace cable with hand tensioner | 10 | 4 mm galvanized 7x19 wire rope, eye to eye: 2 at 4230 mm (rear gable), 4 at 2520 mm (side walls), 4 at 2750 mm (roof); one end looped round a thimble with two wire rope clips, the other through a hand tensioner; a snap hook at each end with a gate opening of 14 mm or more | Rigging or hardware supplier | 4.20 | buy | Indicative price per assembled cable; tensioner rating unknown (to confirm, SNF-DEC-001); lower ends clip to the anchor eyes, upper ends to the cable bolt rings (SNF-DDR-003 C3, C4; SNF-DWG-109)
9 Screw ground anchor | 6 | 380 mm galvanized screw anchor (standard) with 90 mm helix and eye (about 12 mm wire, 56 mm across), turned by hand with a tube as lever until the eye sits on the foot plate | Hardware or farm supplier | 4.00 | buy | Indicative price; four at the front and middle feet and two for guys; holding capacity unverified; demand up to 0.63 kN at a middle foot (SNF-CAL-001); eye down on the plate per SNF-DDR-003 C5; the two rear corner feet take item 16
10 Guy line | 2 | 6 mm polyester rope, 3.5 m, slide tensioner, reflective tape; tied to the ring on the end ridge node's cable bolt | Outdoor or hardware supplier | 3.00 | buy | Indicative price
11 Tarpaulin | 3 | 4 x 6 m reinforced woven polyethylene with eyelets, relief agency specification class; two cover the roof, side walls and rear gable, the third is cut for the front gable with a door flap (SNF-DEC-001, 2026-10-02) | Relief supplier or agency stock | 25.00 | buy | Agency stock per SNF-DDR-001 D1; $25 each, $75.00 for three, excluded from the frame kit budget total; not flame retardant; cutting plan in docs/05-build-plan.md section 3.11; left out of the exploded view
12 Snap buttons and hitch pins | 1 | 36 stainless spring snap buttons (20 for 3/4 in EMT, 16 for 1 in EMT; spring no more than 45 mm beyond the button, button at least 3.5 mm proud), 12 hitch pins 8 mm with lanyards, 4 push-in caps for the blank corner eave sockets | Outdoor gear or hardware supplier | 24.00 | buy | Indicative price for the set; button fit per SNF-DDR-003 C1 and C2
13 Bundle straps and bag | 1 | Four 25 mm cam straps, two on each of the two tube bundles; one duffel bag about 0.08 m3 for nodes, cables, anchors, folding step and the cable bolt sets | Outdoor or hardware supplier | 26.00 | buy | Indicative price: four cam straps at about $3.00 each ($12.00 in all, $6.00 of it the second set added 2026-10-02) and the duffel at about $14.00; no exploded-view callout
14 Cable bolt set | 9 | Stainless A4-70 M10 x 90 hex bolt (26 mm thread), M10 nyloc nut, washers 30 mm, 24 mm and 20 mm OD, 14 mm OD x 10 mm spacer, welded 6 mm stainless ring of 32 mm bore | Fastener or rigging supplier | 2.60 | buy | Indicative price per set; one through each eave and ridge node; the cable snap hooks and guy lines clip to the ring (SNF-DDR-003 C3)
15 Folding step | 1 | Two-tread folding step of steel or aluminum, top tread 500 mm above the floor, about 450 x 500 mm footprint and 80 mm folded, about 1.5 kg, rated for 100 kg or more | Hardware or home supplier | 25.00 | buy | Indicative retail price for a light two-step folding step; decided 2026-10-02 for the first prototype (SNF-DDR-003 A1); stays in the kit if guiding from the ground is slower or needs a third person (timed at TRL 4); used at steps 5 and 7 to reach the ridge sockets
16 Long screw anchor | 2 | 560 mm galvanized screw anchor, same 90 mm helix and 12 mm wire eye (56 mm across) as item 9, rated for 1.5 kN uplift in firm soil | Hardware or farm supplier | 6.00 | buy | Indicative price scaled from item 9 by length (560/380 x $4.00 = $5.89, rounded to $6.00); one at each rear corner foot where demand is up to 1.28 kN (SNF-CAL-001; R8 raised to 1.5 kN there, SNF-DEC-001); rating to be confirmed when bought (SNF-DEC-001, to confirm item 4)

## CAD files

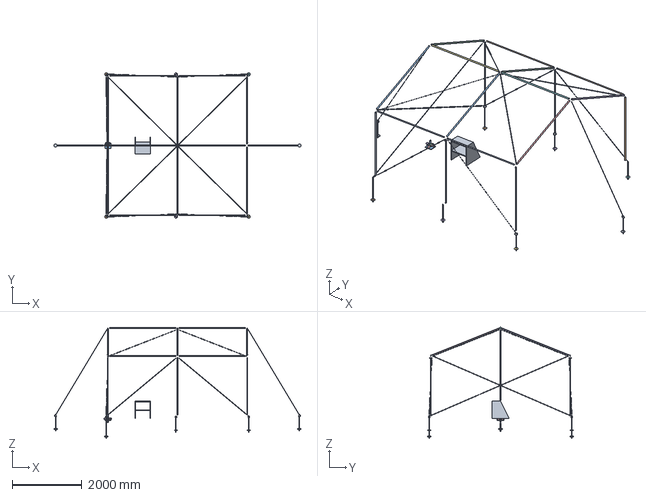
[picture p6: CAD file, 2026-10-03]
cad/step/snapframe-M-assembly.step
7089.9 x 4177.6 x 3188.0 mm

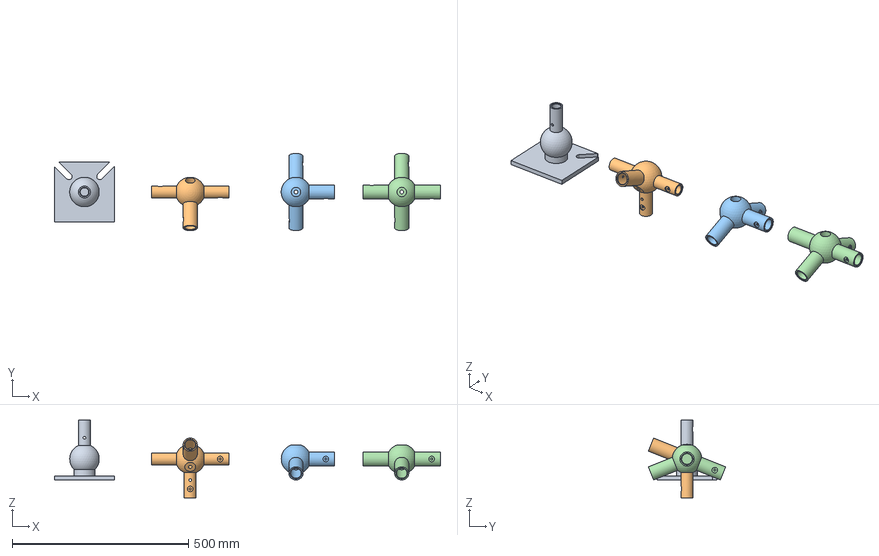
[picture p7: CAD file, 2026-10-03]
cad/step/snapframe-M-nodes.step
1095.0 x 219.2 x 220.0 mm
M foot x6
M eave x6
M ridge-end x2
M ridge-middle x1

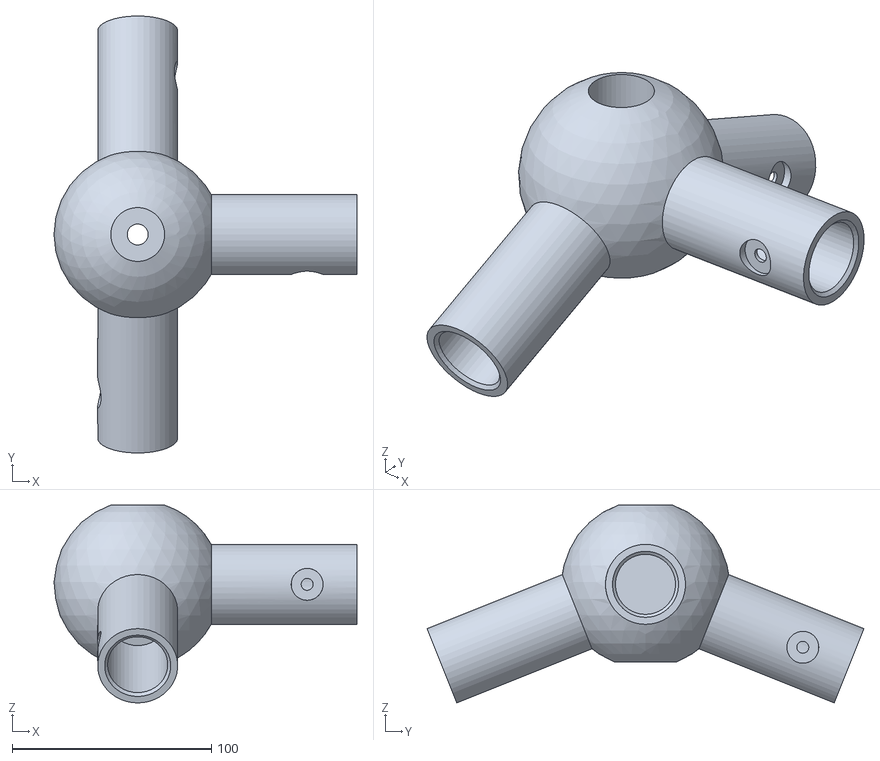
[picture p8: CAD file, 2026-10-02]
cad/stl/snapframe-L-ridge-end.stl
152.0 x 219.2 x 99.3

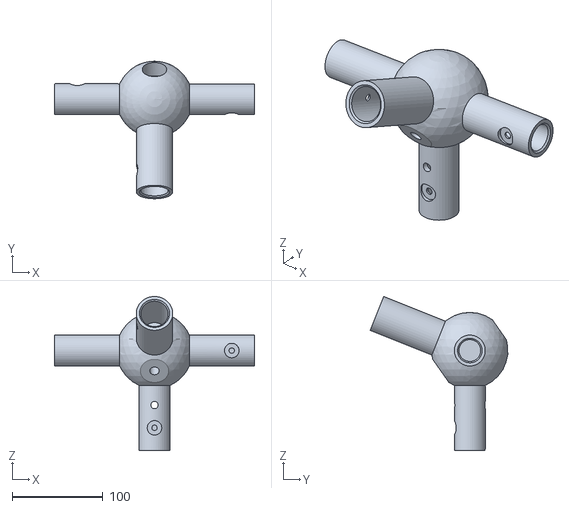
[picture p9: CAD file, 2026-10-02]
cad/stl/snapframe-L-eave.stl
220.0 x 151.4 x 169.5

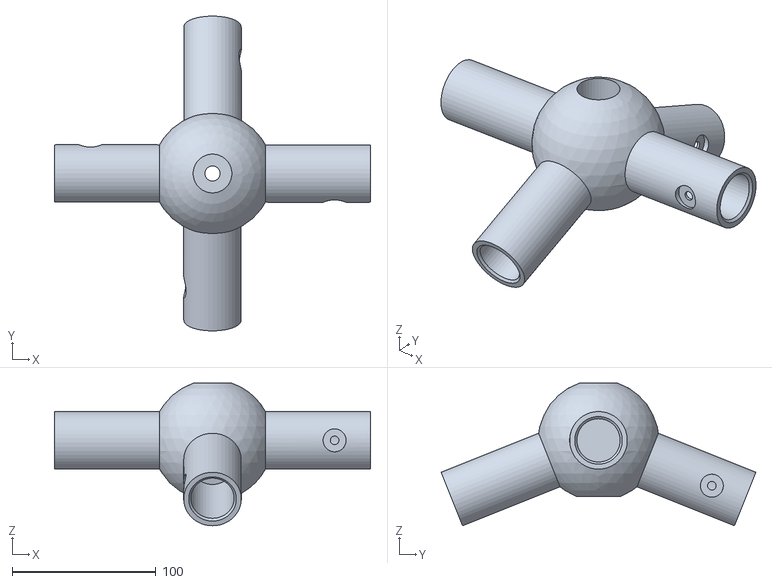
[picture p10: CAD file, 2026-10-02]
cad/stl/snapframe-M-ridge-middle.stl
220.0 x 219.2 x 99.3

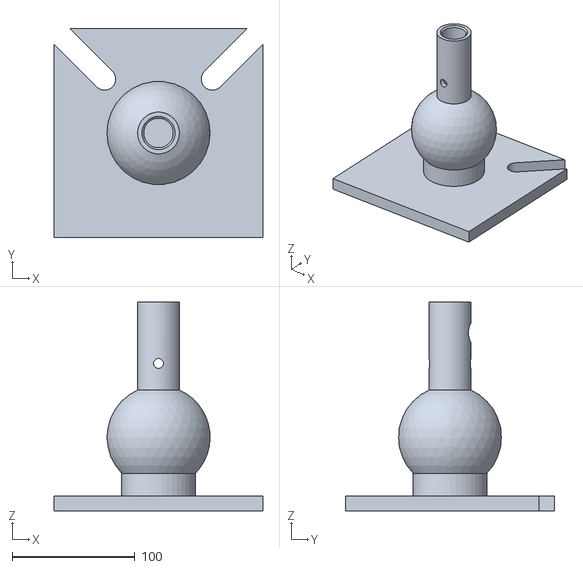
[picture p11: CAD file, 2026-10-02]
cad/stl/snapframe-S-foot.stl
170.0 x 170.0 x 170.0

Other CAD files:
cad/step/snapframe-S-nodes.step
cad/step/snapframe-L-nodes.step

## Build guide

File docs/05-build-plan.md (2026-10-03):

---
doc_id: SNF-BLD-001
title: SnapFrame prototype build plan
project: SnapFrame
doc_type: Build plan
version: "0.3"
status: Draft
date: '2026-10-02'
author: Amish Chadha
license: CERN-OHL-S-2.0
revisions:
  - version: "0.1"
    date: '2026-10-01'
    author: Amish Chadha
    change: First build plan, from the template with pictures by component and step; design made constructable (SNF-DDR-003)
  - version: "0.2"
    date: '2026-10-02'
    author: Amish Chadha
    change: "Node polymer changed to glass- or carbon-filled PA12-class nylon (decided by Amish on 2026-10-02); printer and fume notes to match"
  - version: "0.3"
    date: '2026-10-02'
    author: Amish Chadha
    change: "Decisions of 2026-10-02 carried into the plan: folding step, long rear anchors, three tarpaulins with a cutting plan and a door flap, two tube bundles and a packing picture, node masses in filled nylon; figures redrawn"
---

# SnapFrame prototype build plan

**Plan, not yet built.** How to build the first proof-of-concept prototype, component by component. Building and testing to it is TRL 4 work. Decisions still to be made are kept in the design decisions register ([docs/06-design-decisions.md](06-design-decisions.md)), not here.

## 1. What you are building

Figure 1. Every component, pulled apart and numbered in build order

*Figure 1. Every component of the size M frame kit, pulled apart and numbered in build order. The cables are drawn thicker than they are so they show.*

The prototype is one size M SnapFrame: a gable-roofed frame 4.0 m square, 1.8 m to the eaves and 2.6 m to the ridge, made of 18 straight steel conduit tubes that click into 15 printed nylon nodes, braced with ten steel cables and held down by eight screw anchors, with three relief tarpaulins tied over it and a folding step to reach the ridge. Figure 1 shows the components in the order you make or fit them. Nine kinds are made: the foot, eave and ridge nodes (printed, then fitted with a steel cable bolt), the posts, rafters, eave tubes and ridge tubes (cut and drilled conduit), and the brace cables (made up from wire rope). The anchors, guy lines, snap buttons, hitch pins, caps, folding step and tarpaulins are bought, and the tarpaulins are cut to a plan (section 3.11). The work is sawing and drilling thin-wall tube, 3D printing, bolting, and making up wire rope ends with clips. The frame kit's parts cost about $701 from the bill of materials, most of it the printed nodes in filled nylon.

> **Safety:** The finished frame is an emergency shelter frame, not a storm refuge: by calculation it stays elastic only up to gusts of about 19.5 m/s (70 km/h), and less with the door flap open and wind blowing into it. Never put it up, take it down or fit the tarpaulins in strong wind, when the tarpaulin acts as a sail. Cut conduit ends are sharp: deburr every end and wear gloves. Raising a frame takes two people; keep fingers out of the sockets as tubes go in. Check for buried cables and pipes before turning in an anchor.

## 2. What changed to make it buildable

The concept showed what the frame does; some of its parts could not be made, fixed or put up as drawn. Each change below keeps what the frame does. The first six are recorded in decision record SNF-DDR-003 and the last four are decisions Amish made on 2026-10-02 (SNF-DEC-001); both are accepted.

*Table 1. Changes from the concept.*

| Component | The concept had | The buildable design has | Why |
| --- | --- | --- | --- |
| Tube ends | Spring button 25 mm and hitch pin 50 mm from the tube end | Button 40 mm and hitch pin 15 mm from the end (Figure 6) | The button's spring runs about 45 mm into the tube; the pin went through it |
| Sockets | Button hole straight through a 5 mm wall; square socket mouths | A 16 mm finger recess round each button hole and a chamfer at each mouth (Figure 5) | A fingertip can press the button to undo the joint, and the button rides in |
| Eave and ridge nodes | A thin printed tab for the cables on the eave nodes, pointing away from them; nothing on the middle ridge node; cables drawn through the node cores | A stainless bolt through each node with a steel ring on a spacer; every cable and guy clips into a ring (Figures 8, 9 and 13) | A printed tab would bend and break; the bolt takes any pull and the ring swings to it |
| Foot nodes | Cables drawn to the node centres; the anchor eye 32 mm above the plate; one anchor slot, straight out | The lower cable ends clip to the anchor eye; the eye is turned down onto the plate; two slots, at 45° either way (Figure 3) | The cable pull goes straight into the anchor, the plate is held from the first turn, and the gable cable passes clear of the foot |
| Erection order | Anchors first, frames dropped onto the anchored feet, then the tubes between them | Frames stand unanchored; each next frame slides 65 mm on its feet onto the tube ends; anchors go in last (steps 4 to 8) | A tube cannot be fitted between two fixed sockets that are closer together than the tube is long |
| Tube drilling | Not stated | The two button holes of every tube on opposite sides, on one marked line (Figure 4) | One drilling rule; every tube of a kind fits any position |
| Reaching the ridge | A person guiding the ridge tubes in from the ground | A folding step in the kit, used at steps 5 to 7 (Figure 1 and the pictures of those steps) | The ridge sockets are at 2.6 m and a person on the ground reaches about 2.2 m |
| Front gable | Left open as the doorway | Closed by part of a third tarpaulin with a door flap, and the corner cable hems cut in the same plan (Figure 18) | One skin that closes the whole shelter from agency stock |
| Rear corner anchors | The same anchor at every foot | A longer 560 mm anchor at each rear corner foot (Figure 3) | The gable and side wall cables both pull on that anchor: up to 1.28 kN against 1.5 kN wanted |
| Packages | One strapped tube bundle of 28.6 kg | Two tube bundles of 16.7 and 12.3 kg, and a bag (Figure 19) | Each package is 25 kg or less |

## 3. Making the components

Make and check each component before the assembly step that needs it. Sizes are in millimetres. "Inboard" means toward the middle of the shelter and "outboard" away from it; the "rear" gable is the one without a door and the "front" gable is the one with the door flap. Workshop tolerance is 1 mm on tube lengths and 0.5 mm on hole positions unless a step says otherwise; drawings do not carry tolerances before TRL 4.

### 3.1 Foot nodes (make 6)

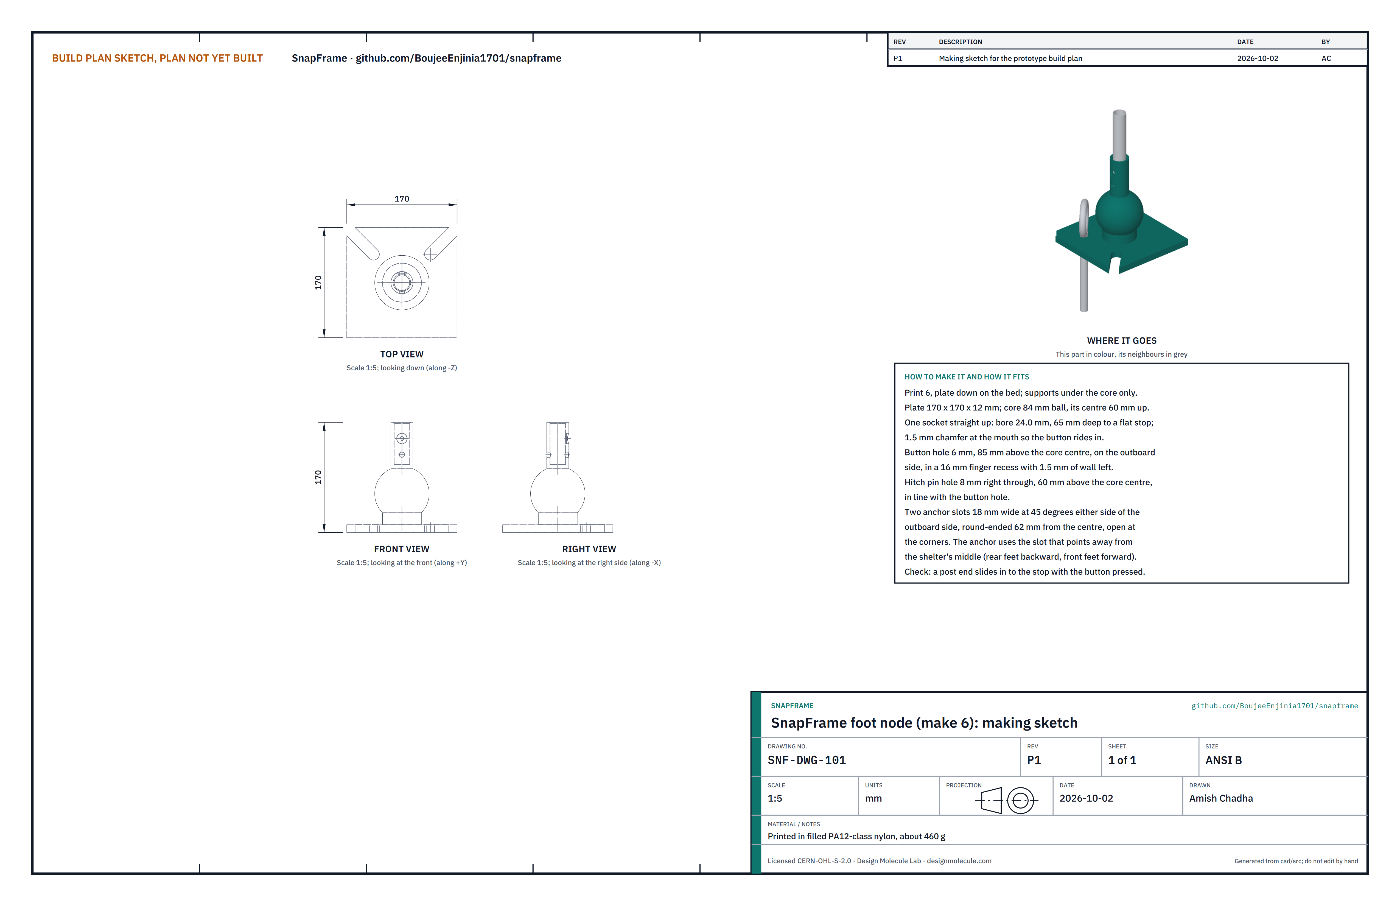
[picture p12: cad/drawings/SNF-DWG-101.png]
Figure 2. Making sketch of the foot node


*Figure 2. Foot node making sketch (SNF-DWG-101).*

**What it is and what it is made from.** The node the bottom of each post stands in: an 84 mm ball with one socket pointing straight up, on a square plate that lies on the ground and is held down by a screw anchor. Printed in a glass- or carbon-filled nylon of the PA12 class (decided 2026-10-02, SNF-DEC-001), about 460 g each.

**How to make it.**

1. Print six, plate down on the bed, with supports under the ball only. Use the print settings that give the calculation note's assumption of about 55 % solid: four or more walls, and 40 % infill or more.
2. Let each print cool on the bed so the plate stays flat. Remove the supports and clean the socket bore.
3. Check the socket bore with a short offcut of 3/4 in conduit: it must slide in to the flat stop at the bottom of the bore without force. Ream lightly if the print is tight.
4. Check the button hole and its finger recess on the outboard side of the socket, and the hitch pin hole through the socket in line with it; clear any stringing with a 6 mm and an 8 mm drill turned by hand.
5. Check both anchor slots: 18 mm wide, open to the plate corners at 45° either side of the outboard side, round-ended 62 mm from the centre.

**How it fits the parts next to it.** A post goes into the socket until its end sits on the flat stop; its button clicks into the hole and a hitch pin goes through (Figure 6, in section 3.2). The plate lies flat on the ground on its mark. A screw anchor goes down through one slot, the one that points away from the middle of the shelter (backward at the rear feet, forward at the front feet, either at the middle feet), and its eye is turned down until it sits on the plate across the slot. The two rear corner feet take the longer anchors:

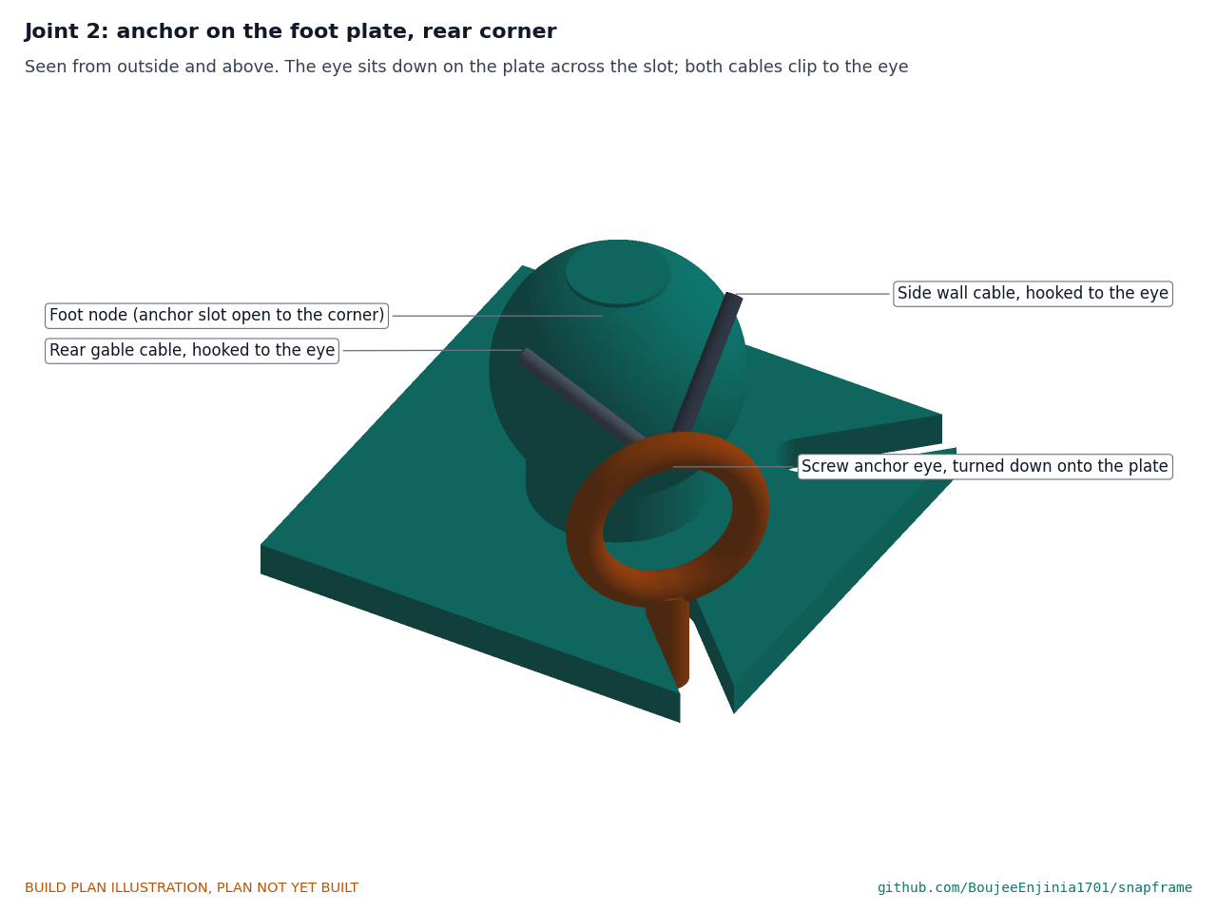
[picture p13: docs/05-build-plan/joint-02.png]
Figure 3. Joint 2: anchor eye on the foot plate, rear corner


*Figure 3. The anchor eye sits down on the plate across the slot; at a corner, the gable cable and the side wall cable clip to the same eye.*

**Check before moving on.** The plate lies flat on a flat floor without rocking; a post offcut clicks in and the hitch pin goes through.

### 3.2 Posts (make 6)

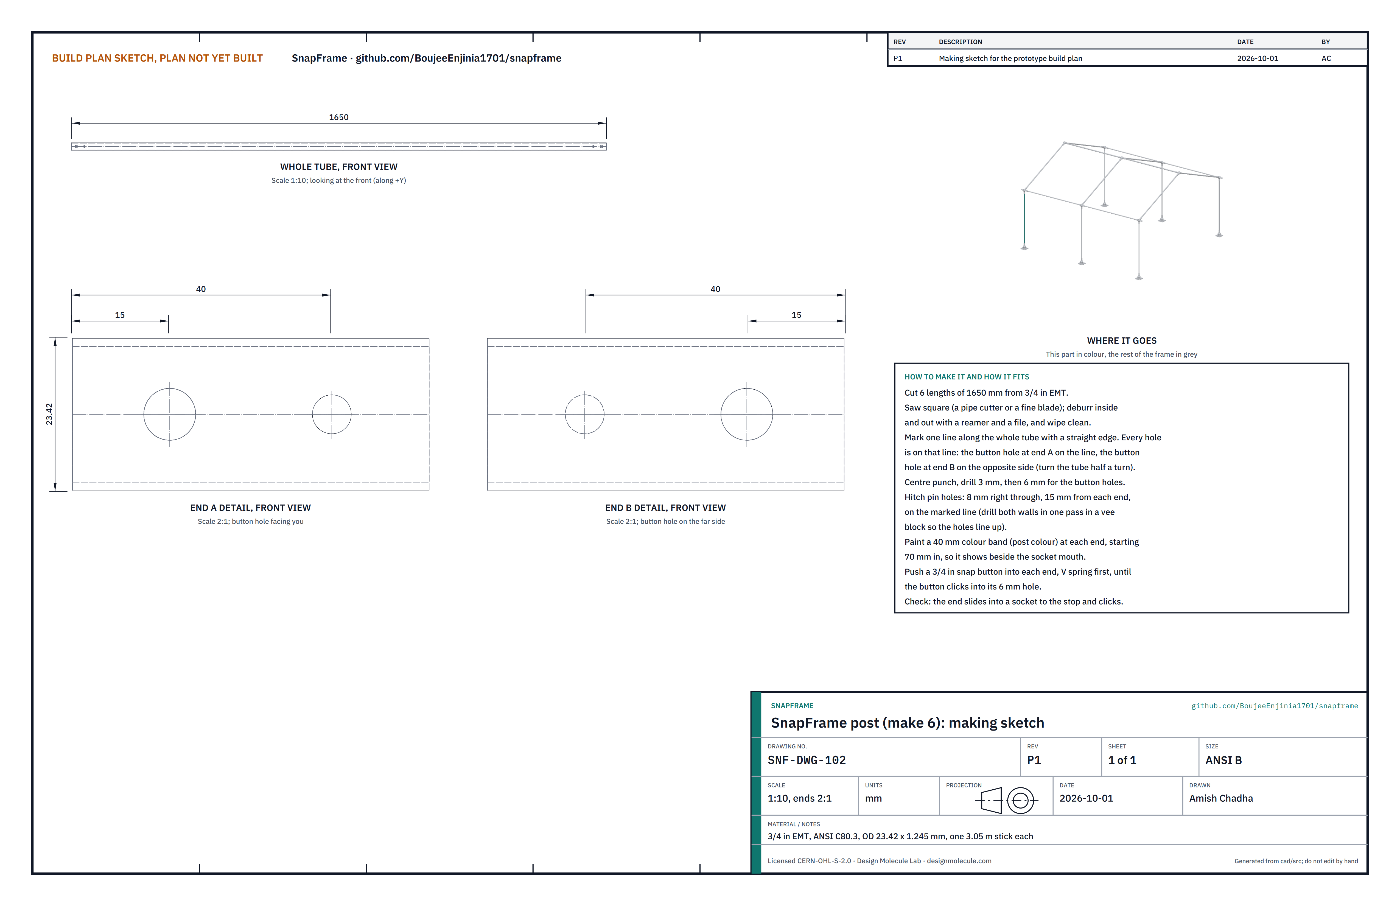
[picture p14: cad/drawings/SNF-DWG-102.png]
Figure 4. Making sketch of the post


*Figure 4. Post making sketch (SNF-DWG-102): the whole tube, and both ends drawn twice full size, with the button hole facing you at one end and on the far side at the other.*

**What it is and what it is made from.** The upright at each corner and in the middle of each side wall. 3/4 in EMT conduit (23.42 mm outside, 1.245 mm wall), cut to 1,650 mm, one from each 3.05 m stick.

**How to make it.**

1. Cut six lengths of 1,650 mm, square, with a pipe cutter or a fine-tooth blade. Ream the inside and file the outside edge of each end smooth, and wipe off the swarf.
2. Lay each tube on a straight edge and draw one line along its whole length.
3. Mark the holes on the line: a hitch pin hole 15 mm from each end, and a button hole 40 mm from end A. Turn the tube half a turn and mark the button hole 40 mm from end B, on the opposite side.
4. Centre punch every mark. In a vee block, drill the hitch pin holes 3 mm, then 8 mm, straight through both walls in one pass so the two sides line up. Drill the button holes 3 mm, then 6 mm, through one wall only.
5. Deburr every hole inside and out.
6. Paint a 40 mm colour band in the post colour round each end, starting 70 mm from the end, so it shows beside the socket mouth.
7. Squeeze a 3/4 in snap button, spring first, into each end and slide it in until the button clicks out through its hole.

**How it fits the parts next to it.**

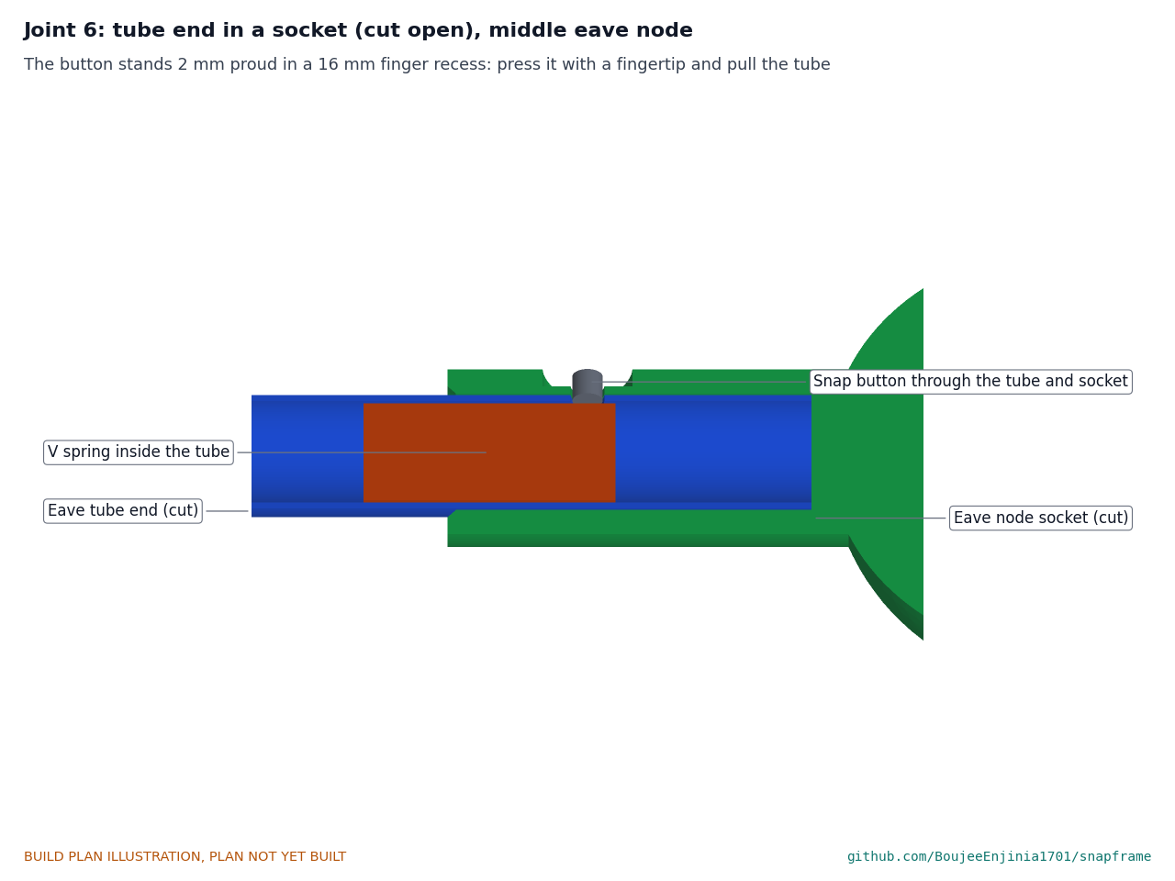
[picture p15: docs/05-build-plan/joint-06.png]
Figure 5. Joint 6: a tube end in its socket, cut open


*Figure 5. Every tube end fits its socket the same way (an eave tube shown): the end sits on the flat stop, the button stands about 2 mm proud in the finger recess, and the spring lies inside the tube.*

Each end slides into its socket with the button pressed, until the end sits on the flat stop 65 mm in, and the button clicks out into the socket's hole. The bore is 0.6 mm larger than the tube, so the tube slides by hand. To undo a joint, press the button down into its recess with a fingertip and pull the tube out. Both ends of a post are pinned: a hitch pin goes through the socket and the tube 15 mm from the tube end, clear of the button's spring:

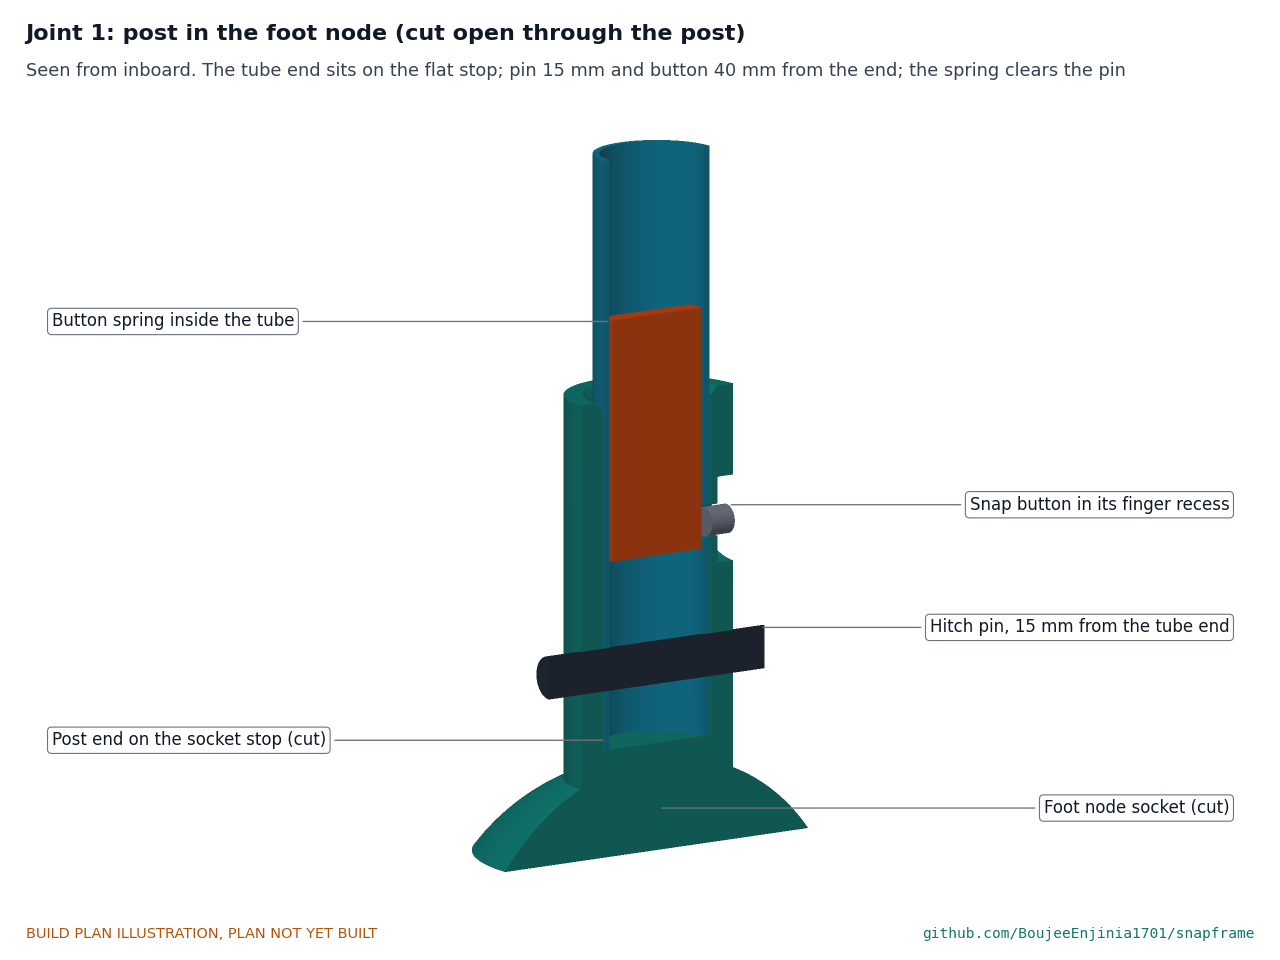
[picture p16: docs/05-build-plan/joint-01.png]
Figure 6. Joint 1: post in the foot node, cut open


*Figure 6. The bottom of a post in the foot node, cut open through the post. The eave end is pinned the same way.*

**Check before moving on.** Lengths within 1 mm; each end clicks into a test socket and comes out by hand; both hitch pin holes take an 8 mm pin straight through.

### 3.3 Eave nodes and their cable bolts (make 6)

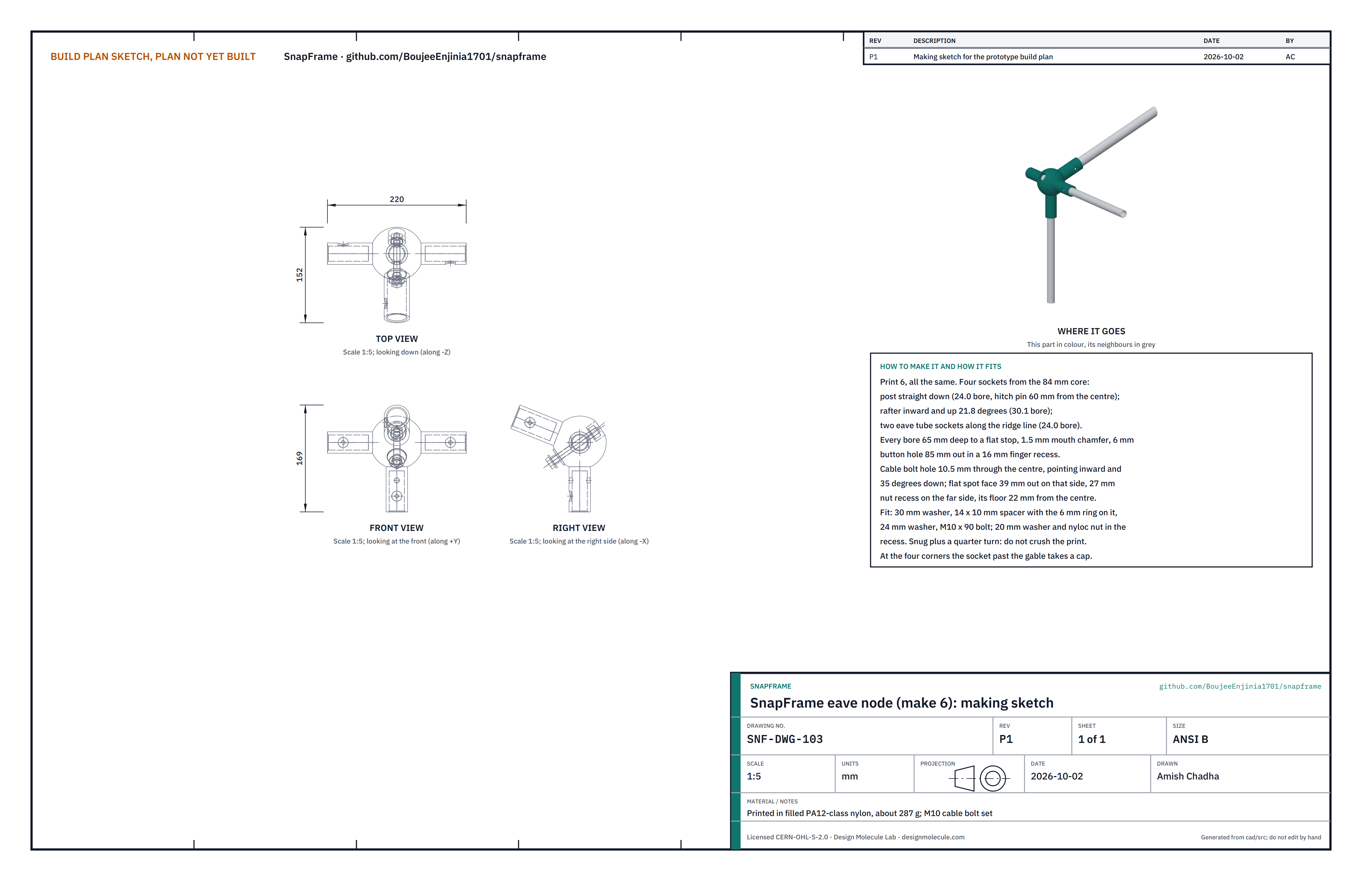
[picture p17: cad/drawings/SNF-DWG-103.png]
Figure 7. Making sketch of the eave node


*Figure 7. Eave node making sketch (SNF-DWG-103), with its cable bolt set.*

**What it is and what it is made from.** The node at the top of each post, where the post, the rafter and the eave tubes meet. One design serves all six places: at the four corners the socket that points past the gable is left empty and capped. Printed in the same nylon, about 287 g, with a bought stainless cable bolt set through it.

**How to make it.**

1. Print six, with supports. The node measures 220 x 152 x 169 mm, so the printer bed must be at least 230 mm across.
2. Clean and check each socket as for the foot node: the post socket (straight down) and the two eave tube sockets (level, along the ridge line) take 3/4 in conduit; the rafter socket (inboard, rising 21.8°) takes 1 in conduit. The post socket has a hitch pin hole.
3. Check the cable bolt hole: 10.5 mm, straight through the ball, pointing inboard and 35° down, with a flat spot face on that side and a 27 mm recess on the far side.
4. Fit the cable bolt set from the spot face side: the 30 mm washer on the spot face, the 14 mm spacer with the 6 mm steel ring threaded on it, the 24 mm washer, then the M10 x 90 bolt through all of them and the ball. In the recess fit the 20 mm washer and the M10 nyloc nut.
5. Tighten the nut with a deep socket until snug, then a further quarter turn. Do not crush the print: the bolt clamps the washer and spacer, not the ring.

**How it fits the parts next to it.**

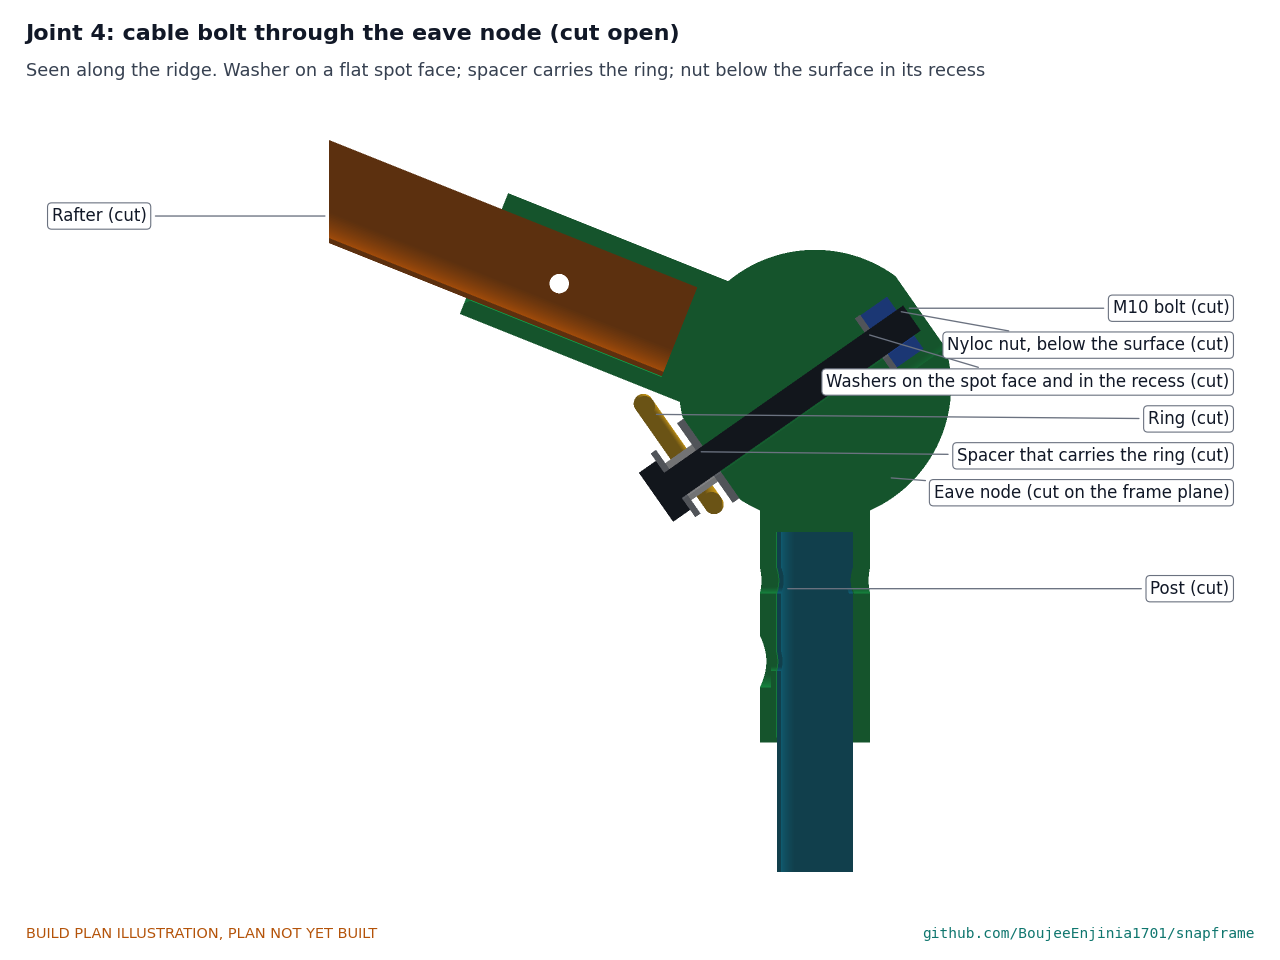
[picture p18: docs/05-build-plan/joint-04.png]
Figure 8. Joint 4: the cable bolt through the eave node, cut open


*Figure 8. The cable bolt through the eave node, cut open along the frame. The washer sits on a flat spot face, the spacer carries the ring, and the nut sits below the surface in its recess.*

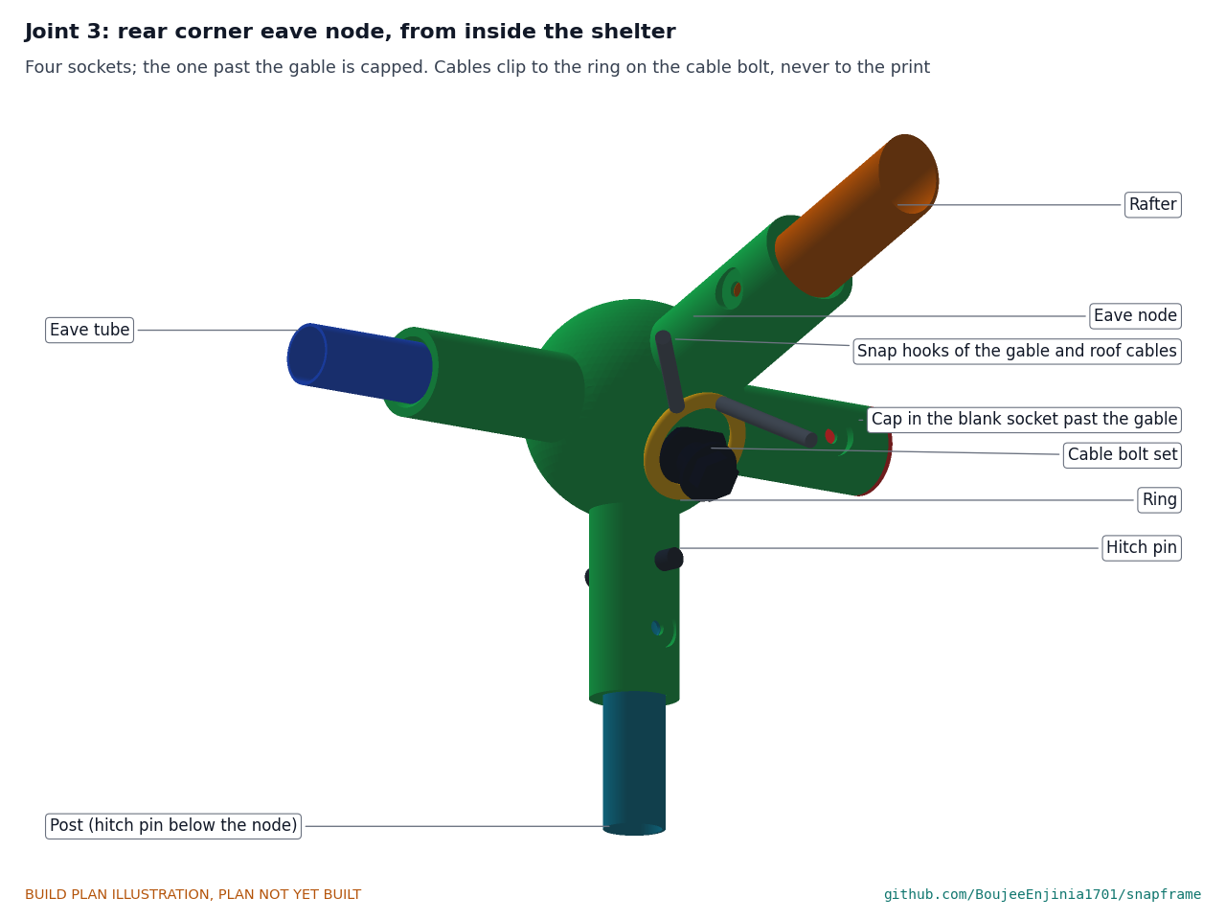
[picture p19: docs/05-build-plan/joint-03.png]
Figure 9. Joint 3: a rear corner eave node from inside the shelter


*Figure 9. A rear corner eave node: the post below (pinned), the rafter rising inboard, the eave tube along the side wall, the cap in the socket past the gable, and two cables clipped into the ring.*

The post, rafter and eave tubes click in as in Figure 5. The ring swings freely on the spacer and lines up with the cables clipped into it; the cables never touch the printed node.

**Check before moving on.** The ring swings all round the spacer by hand; nothing stands proud of the far side of the ball; every socket takes its tube to the stop.

### 3.4 Rafters (make 6)

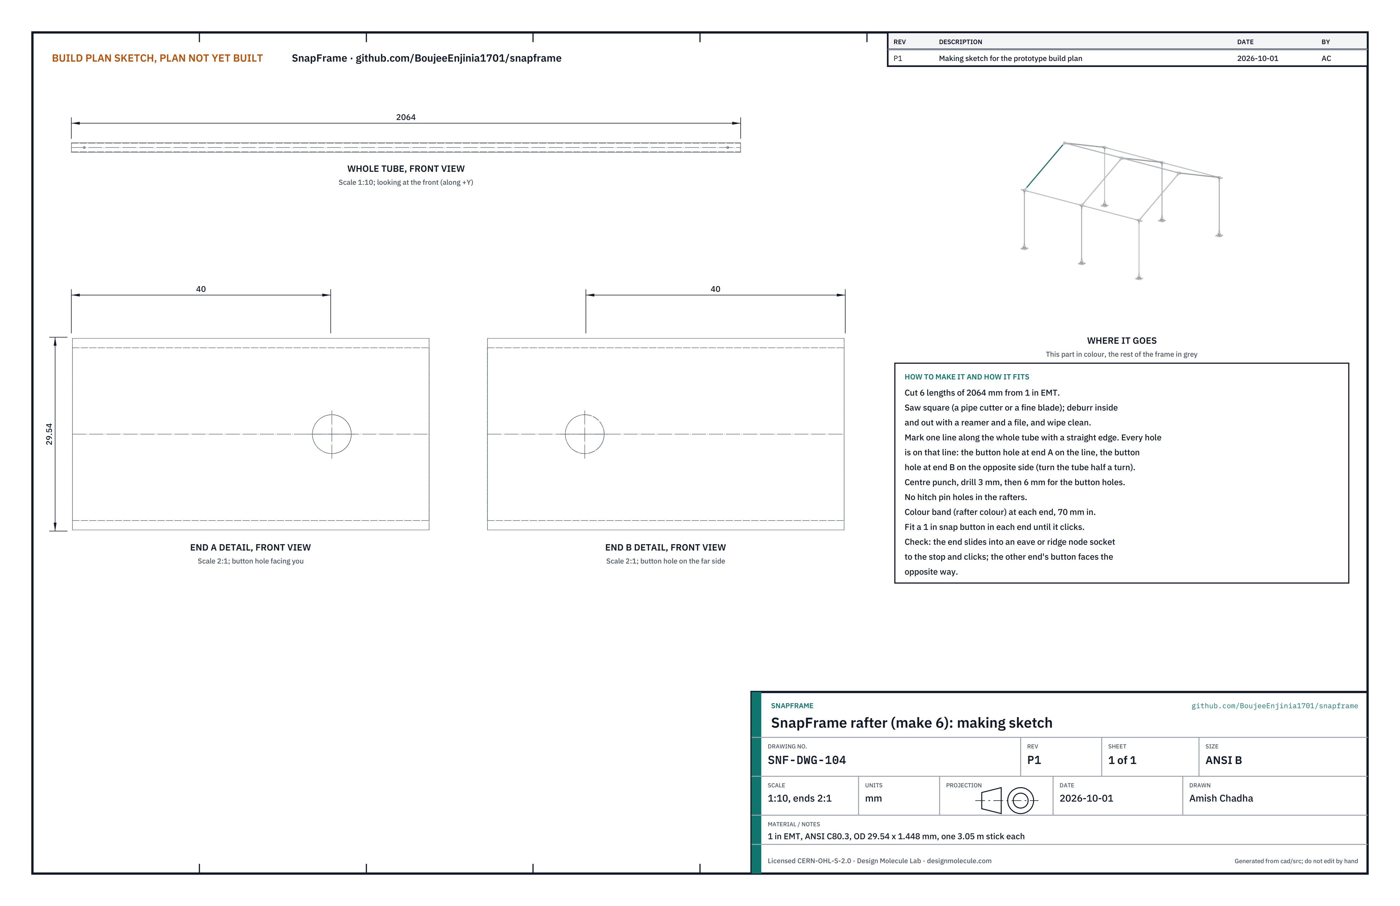
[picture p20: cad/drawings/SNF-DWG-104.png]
Figure 10. Making sketch of the rafter


*Figure 10. Rafter making sketch (SNF-DWG-104).*

**What it is and what it is made from.** The sloping tube from each eave node up to the ridge node. 1 in EMT conduit (29.54 mm outside, 1.448 mm wall), cut to 2,064 mm, one from each 3.05 m stick.

**How to make it.**

1. Cut six lengths of 2,064 mm; ream and file both ends.
2. Draw a line along each tube; mark a button hole 40 mm from end A on the line and 40 mm from end B on the opposite side. There are no hitch pin holes in the rafters.
3. Drill 3 mm, then 6 mm, through one wall; deburr.
4. Paint the rafter colour band at each end, 70 mm in.
5. Fit a 1 in snap button in each end until it clicks.

**How it fits the parts next to it.** The low end goes into the eave node's rafter socket and the high end into a ridge node socket, as in Figure 5. With the button at the low end facing one way, the button at the high end faces the other: that is how the sockets are made.

**Check before moving on.** Length within 1 mm; both ends click into 1 in sockets.

### 3.5 Ridge nodes, end (make 2)

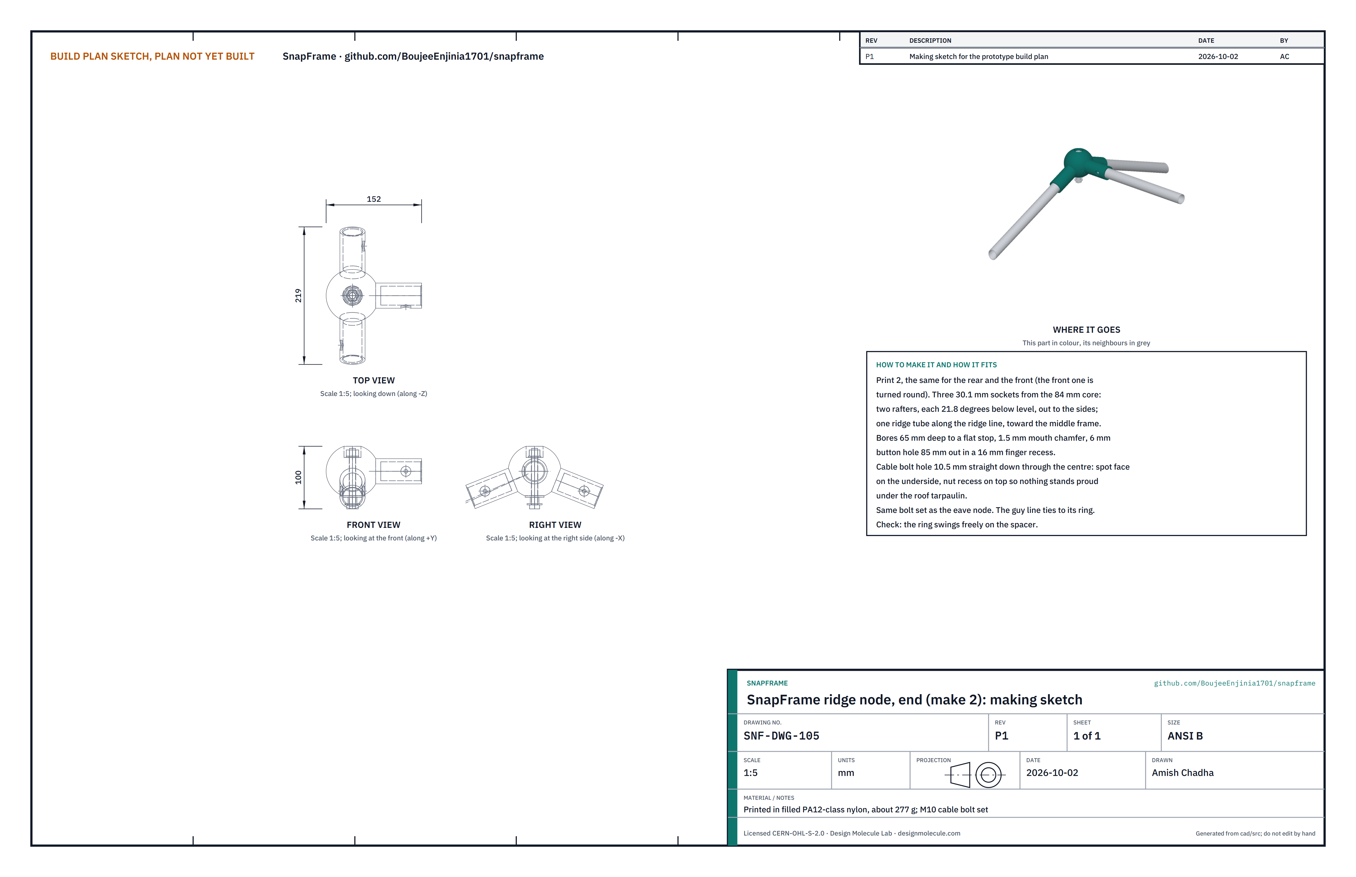
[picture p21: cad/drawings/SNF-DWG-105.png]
Figure 11. Making sketch of the end ridge node


*Figure 11. End ridge node making sketch (SNF-DWG-105).*

**What it is and what it is made from.** The node at the top of the rear frame and of the front frame: two rafter sockets sloping down to the sides at 21.8° and one ridge tube socket pointing along the ridge toward the middle frame, all for 1 in conduit. The rear and front nodes are the same; the front one is turned round. Printed, about 277 g, with a cable bolt set pointing straight down.

**How to make it.**

1. Print two, with supports; clean and check each socket with a 1 in offcut.
2. Fit the cable bolt set as for the eave node (section 3.3, steps 4 and 5), from below: the spot face is on the underside and the nut recess on top, so nothing stands proud under the roof tarpaulin.

**How it fits the parts next to it.** The two rafters and the ridge tube click in as in Figure 5. The guy line for that gable ties to the ring.

**Check before moving on.** The ring swings freely; the top of the node is smooth.

### 3.6 Ridge node, middle (make 1)

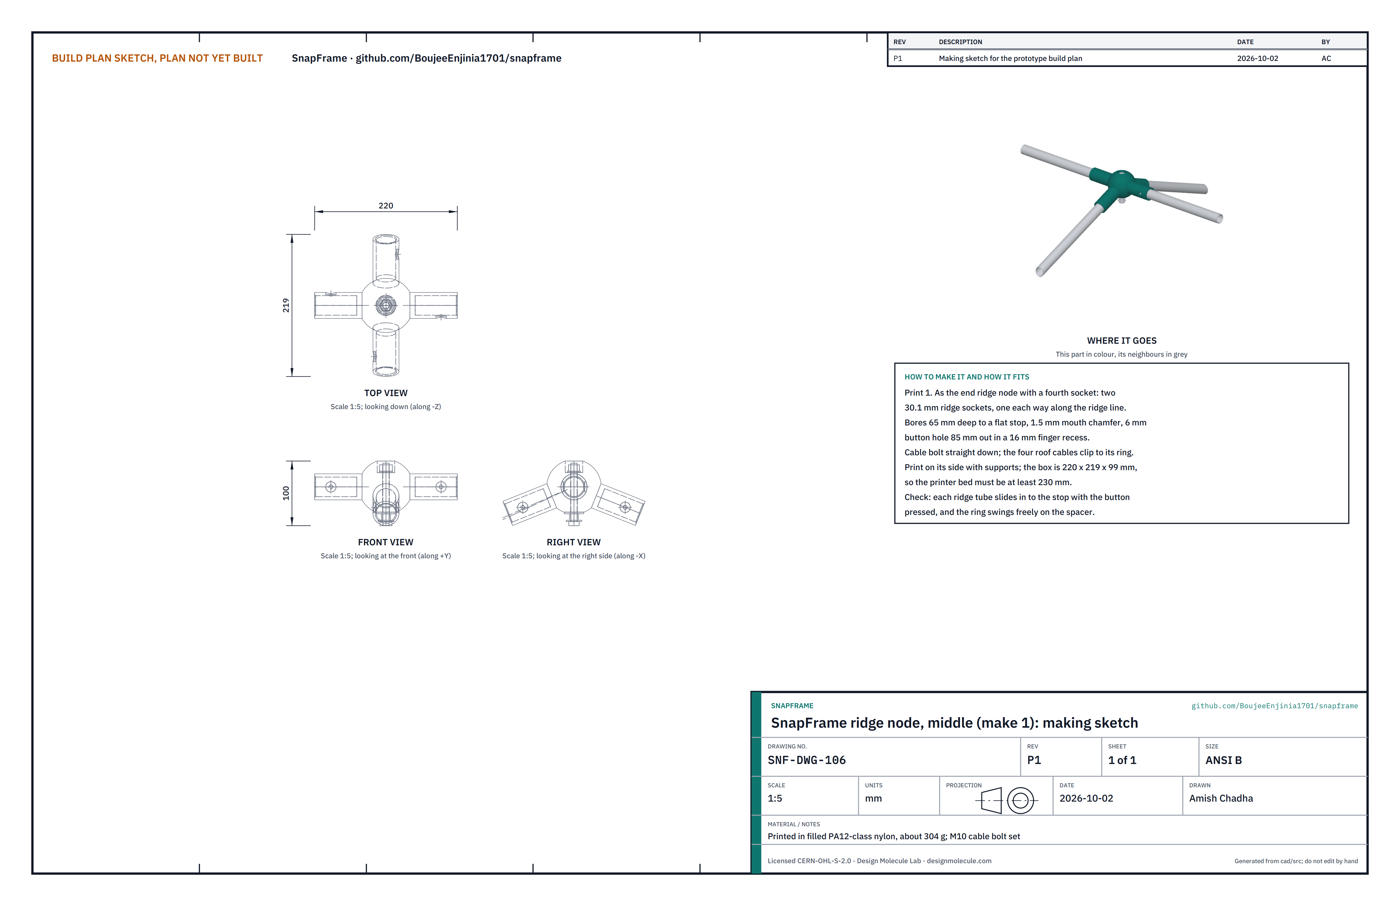
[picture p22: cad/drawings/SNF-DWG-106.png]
Figure 12. Making sketch of the middle ridge node


*Figure 12. Middle ridge node making sketch (SNF-DWG-106).*

**What it is and what it is made from.** As the end ridge node, with a fourth socket so that a ridge tube goes each way along the ridge. Printed, about 304 g (220 x 219 x 99 mm), with a cable bolt set pointing straight down.

**How to make it.** Print one and fit its cable bolt set as in section 3.5.

**How it fits the parts next to it.**

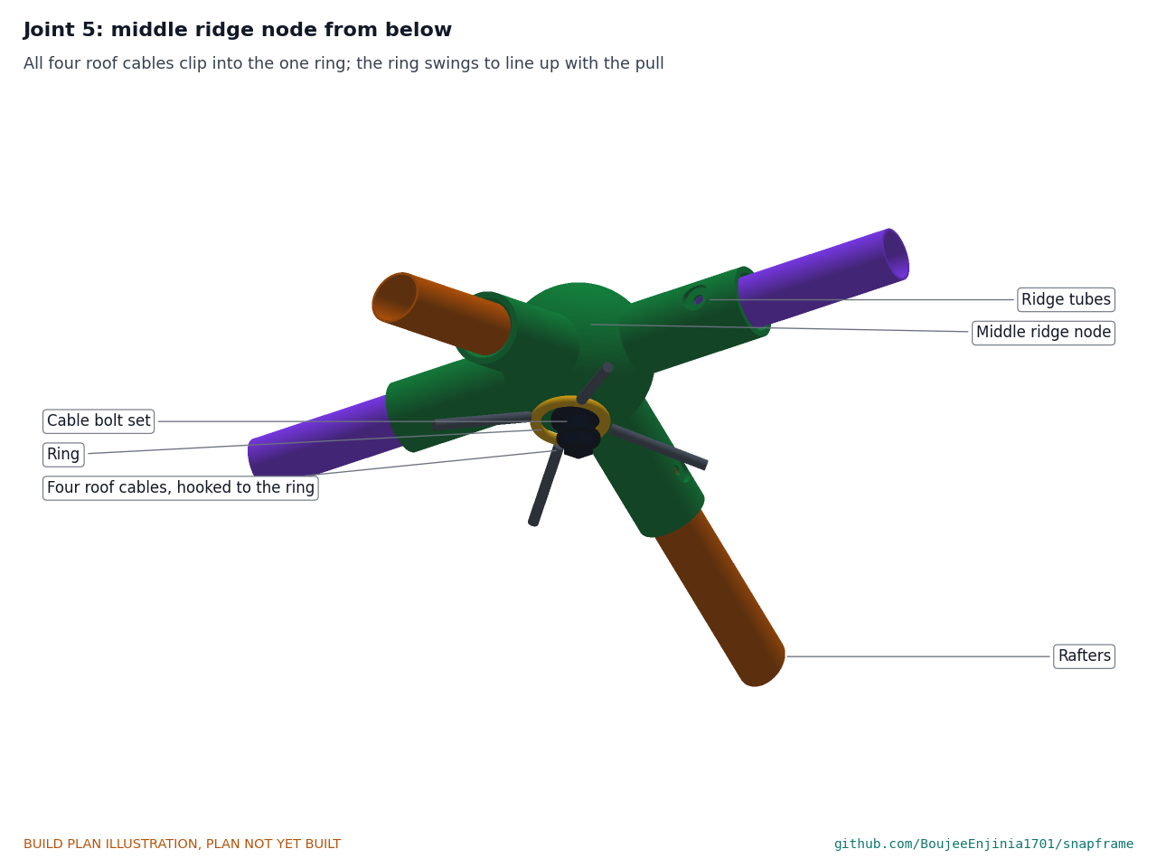
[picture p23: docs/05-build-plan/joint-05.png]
Figure 13. Joint 5: the middle ridge node from below


*Figure 13. All four roof cables clip into the one ring below the middle ridge node.*

**Check before moving on.** Each ridge socket takes a 1 in offcut to the stop; the ring swings freely.

### 3.7 Eave tubes (make 4)

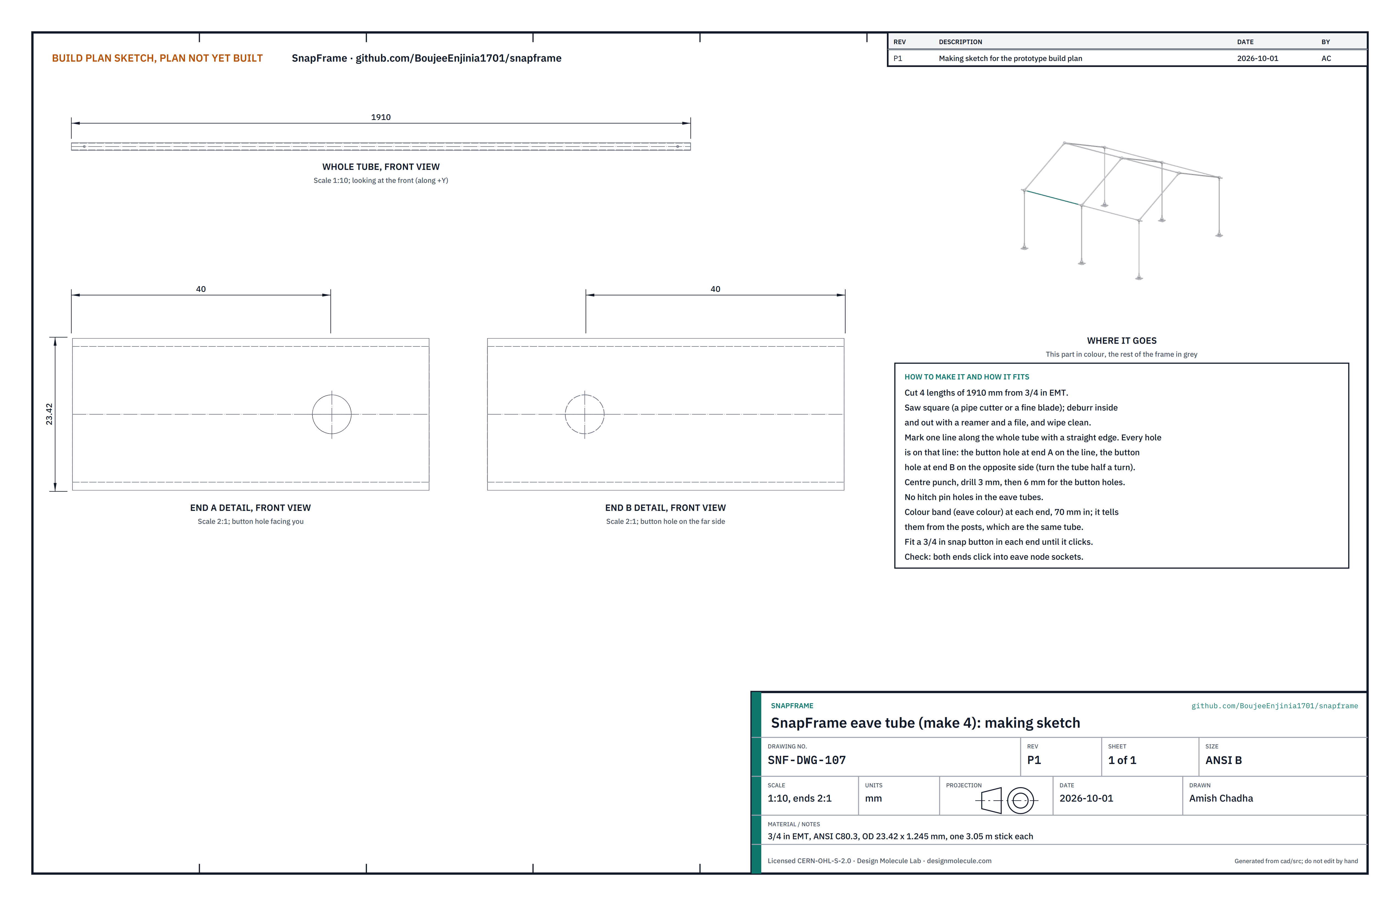
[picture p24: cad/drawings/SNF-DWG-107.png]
Figure 14. Making sketch of the eave tube


*Figure 14. Eave tube making sketch (SNF-DWG-107).*

**What it is and what it is made from.** The level tube along the top of each side wall, from eave node to eave node. 3/4 in EMT, cut to 1,910 mm.

**How to make it.** As the rafter (section 3.4) with 3/4 in conduit and length 1,910 mm: button holes 40 mm from each end on opposite sides, no hitch pin holes, the eave colour band at each end (it tells them from the posts, which are the same conduit), and a 3/4 in snap button in each end.

**How it fits the parts next to it.** Each end clicks into an eave node's level socket (Figure 5).

**Check before moving on.** Length within 1 mm; both ends click in.

### 3.8 Ridge tubes (make 2)

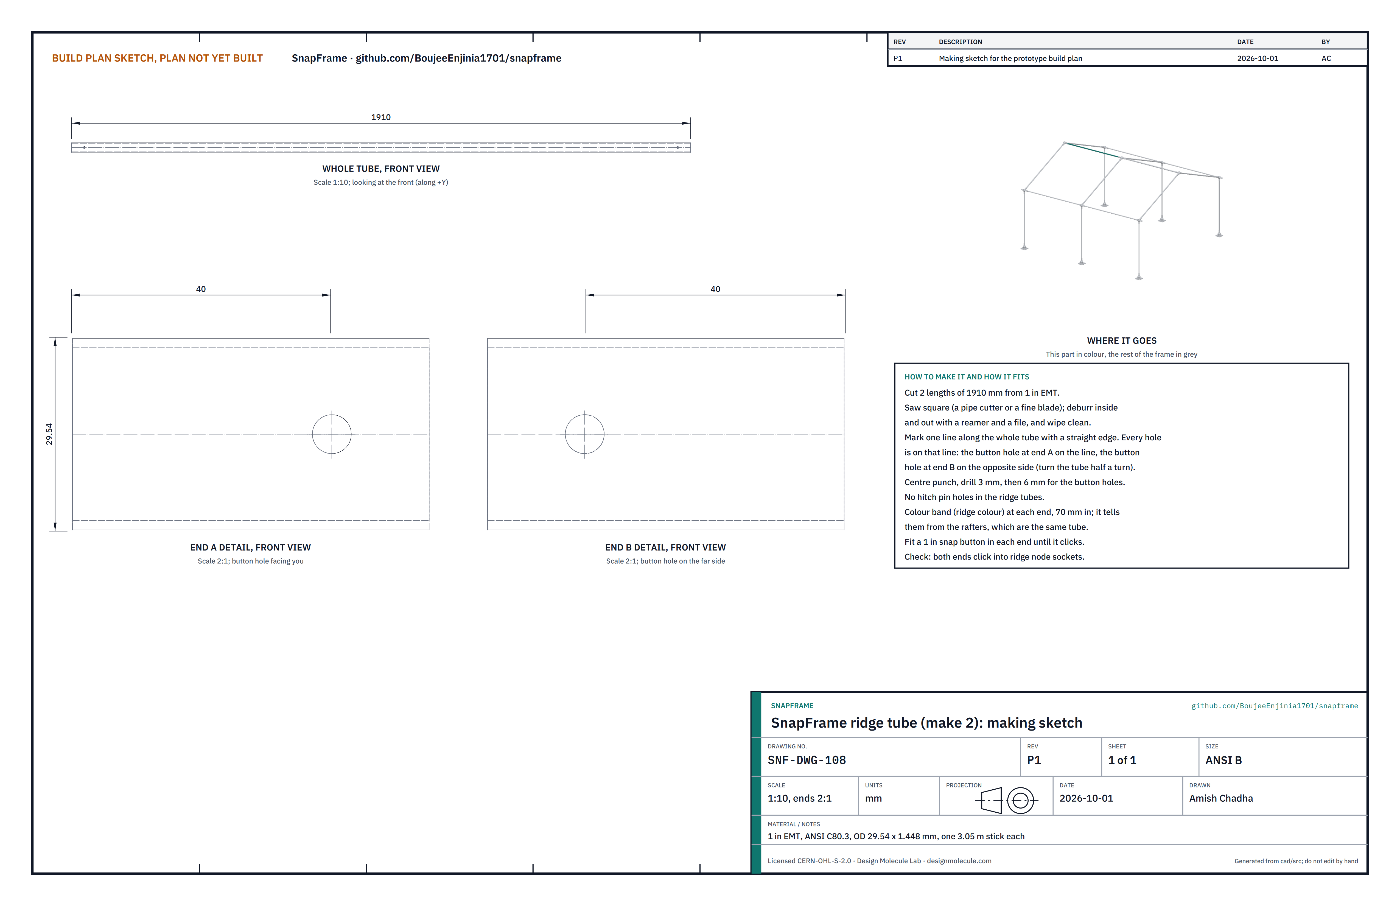
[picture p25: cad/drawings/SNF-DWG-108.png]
Figure 15. Making sketch of the ridge tube


*Figure 15. Ridge tube making sketch (SNF-DWG-108).*

**What it is and what it is made from.** The level tube along the ridge between ridge nodes. 1 in EMT, cut to 1,910 mm.

**How to make it.** As the rafter (section 3.4), length 1,910 mm, with the ridge colour band at each end (it tells them from the rafters, which are the same conduit).

**How it fits the parts next to it.** Each end clicks into a ridge node's ridge socket (Figure 5).

**Check before moving on.** Length within 1 mm; both ends click in.

### 3.9 Brace cables (make 10)

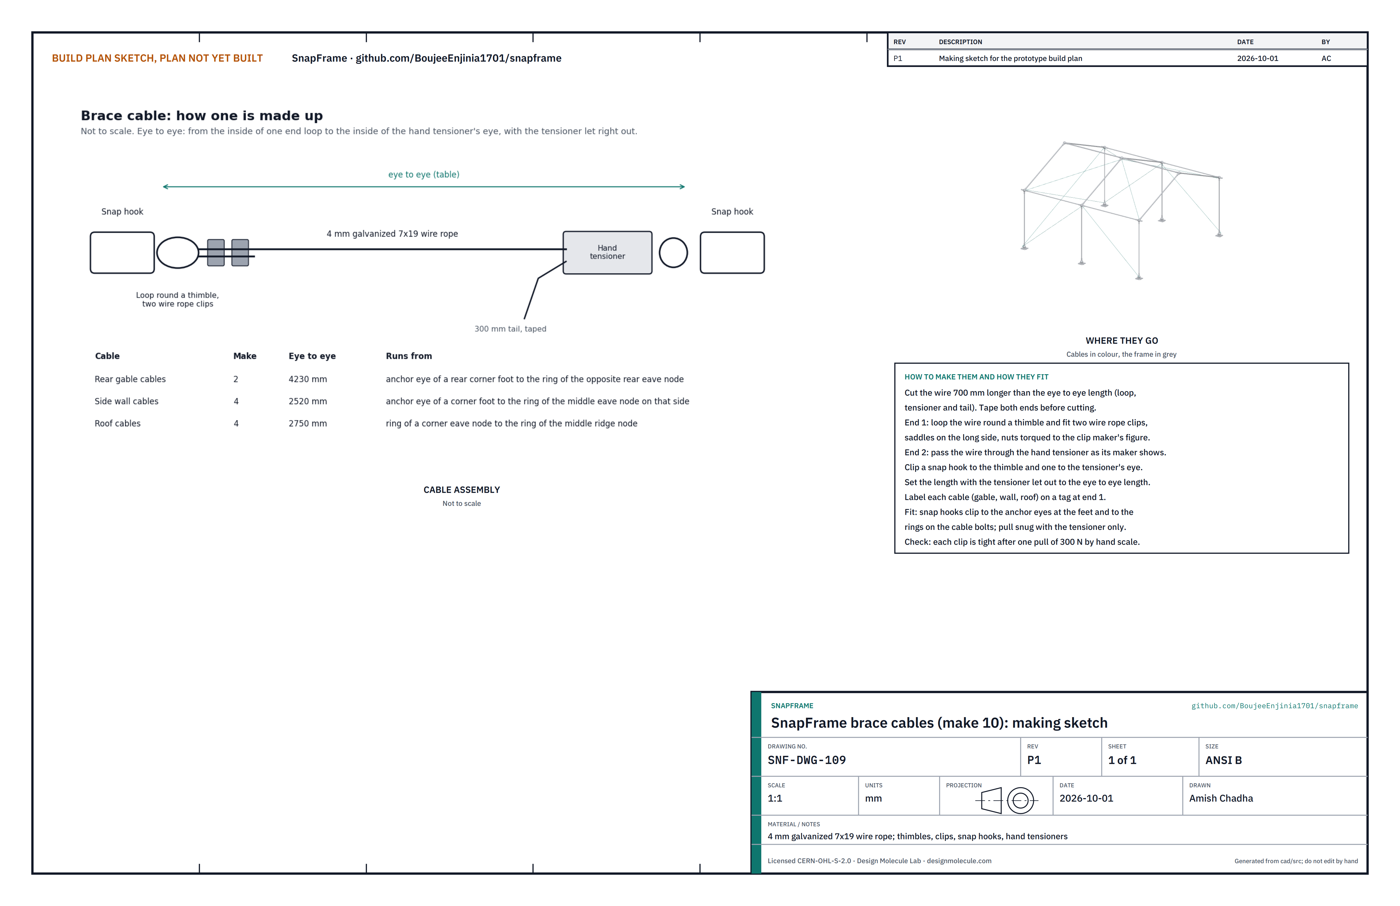
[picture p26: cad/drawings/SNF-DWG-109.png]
Figure 16. Making sketch of the brace cables


*Figure 16. Brace cable making sketch (SNF-DWG-109).*

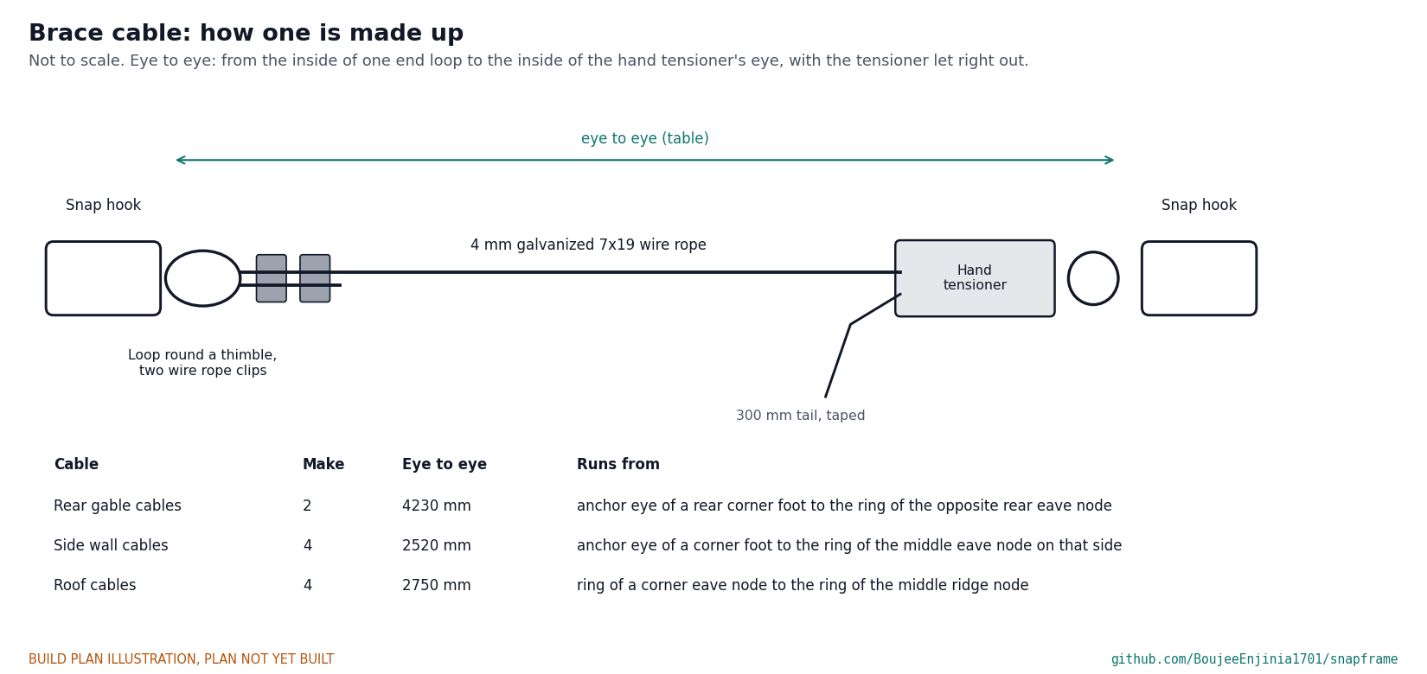
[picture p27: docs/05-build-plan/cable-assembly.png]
Figure 17. How a brace cable is made up


*Figure 17. One brace cable, with the three lengths needed.*

**What it is and what it is made from.** A steel wire rope with a snap hook at each end and a hand tensioner at one end, that braces the frame against wind. Ten are needed: two for the rear gable (4,230 mm eye to eye), four for the side walls (2,520 mm) and four for the roof (2,750 mm). 4 mm galvanized 7x19 wire rope, thimbles, wire rope clips, hand tensioners and snap hooks.

**How to make it.**

1. Tape the wire where you will cut it and cut each length 700 mm longer than its eye-to-eye length, to allow for the loop, the tensioner and a tail.
2. At one end, bend the wire round a thimble and fit two wire rope clips, the saddles on the long side of the wire. Tighten the clip nuts to the clip maker's figure.
3. Thread the other end through the hand tensioner as its maker shows. Set the tensioner let right out and adjust the wire so the cable measures its eye-to-eye length. Tape the tail.
4. Clip a snap hook to the thimble and one to the tensioner's eye.
5. Tag each cable "gable", "wall" or "roof" at the thimble end.

**How it fits the parts next to it.** The gable and side wall cables run from an anchor eye at a corner foot (Figure 3) up to the ring of an eave node; the roof cables run from the ring of a corner eave node to the ring of the middle ridge node (Figure 13). They are pulled snug with the tensioner only.

**Check before moving on.** Each cable within 20 mm of its eye-to-eye length; the clips do not slip when the cable is pulled to 300 N on a hand scale.

### 3.10 Bought components

Buy to specification, not brand. Line numbers are those of the bill of materials.

- **Screw anchors (line 9).** Six galvanized screw anchors about 380 mm long with a 90 mm helix and an eye of about 12 mm wire and 56 mm across, so the eye straddles the 18 mm slot. Four go at the middle and front feet, two for the guys.
- **Long screw anchors (line 16).** Two of the same design, 560 mm long, rated for 1.5 kN uplift in firm soil, for the two rear corner feet, where the gable cable and the side wall cable both pull on the eye.
- **Guy lines (line 10).** Two 3.5 m lengths of 6 mm polyester rope, each with a slide tensioner and reflective tape.
- **Tarpaulins (line 11).** Three 4 x 6 m reinforced woven polyethylene tarpaulins with eyelets, relief agency class, from agency stock. They are cut to the plan in section 3.11.
- **Snap buttons, hitch pins and caps (line 12).** 36 stainless spring snap buttons with a 6 mm button: 20 for 3/4 in conduit and 16 for 1 in conduit, each with its spring reaching no more than 45 mm beyond the button and the button standing at least 3.5 mm above the tube. Twelve 8 mm hitch pins on lanyards. Four push-in caps for the 24.0 mm corner sockets.
- **Bundle straps and bag (line 13).** Four 25 mm cam straps, two for each tube bundle, and a duffel bag of about 0.08 m³.
- **Folding step (line 15).** A light two-tread folding step of steel or aluminum, top tread 0.50 m above the floor, about 450 x 500 mm on the floor and 80 mm thick folded, about 1.5 kg, rated for 100 kg or more.
- **Cable bolt sets (line 14).** Nine sets, stainless A4-70: an M10 x 90 hex bolt with 26 mm of thread, an M10 nyloc nut, washers of 30, 24 and 20 mm outside diameter, a spacer 14 mm outside and 10 mm long, and a welded ring of 6 mm wire and 32 mm bore.
- **Snap hooks (line 8).** Galvanized or stainless, gate opening 14 mm or more so they pass over the anchor eye wire; two per cable.

### 3.11 Tarpaulins: cutting plan (cut 3 tarpaulins into 6 pieces)

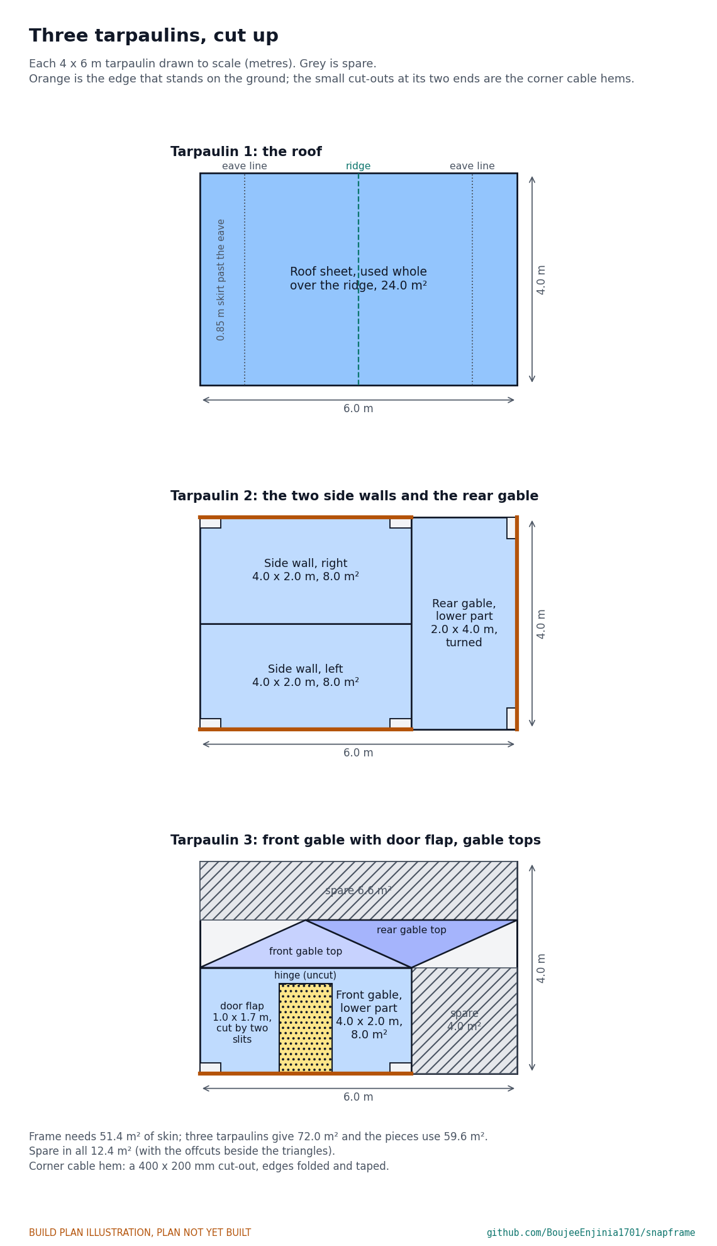
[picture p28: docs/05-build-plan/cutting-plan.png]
Figure 18. The three tarpaulins cut up


*Figure 18. Cutting plan for the three 4 x 6 m tarpaulins (SNF-DEC-001, 2026-10-02). Orange edges stand on the ground; the small cut-outs at their ends are the corner cable hems.*

**What it is and what it is made from.** The skin that closes the roof, both side walls and both gables, cut from three standard 4 x 6 m reinforced polyethylene tarpaulins from agency stock. The frame needs 51.4 m² of skin; the three tarpaulins give 72 m² and the pieces use 59.6 m² of it, leaving 12.4 m² for patches.

**How to make it.**

1. Tarpaulin 1 is not cut. It goes over the ridge as the roof, with its 6.0 m side across the slopes (the two slopes need 4.3 m, which leaves a skirt of 0.85 m past each eave) and its 4.0 m side along the ridge.
2. Cut tarpaulin 2 across the 6.0 m side into three strips of 4.0 x 2.0 m. Two are the side walls (the wall is 1.8 m high, so 0.2 m tucks under the roof sheet's skirt) and the third is the lower part of the rear gable, turned so its 4.0 m side runs across the gable.
3. From tarpaulin 3 cut a strip of 4.0 x 2.0 m for the lower part of the front gable. Mark a door flap 1.0 m wide and 1.7 m high in the middle of it, and cut the two slits from the ground edge up to 1.7 m. Leave the top of the flap uncut, as its hinge. Roll the flap up from the bottom and tie it with its eyelet ties when the door is open.
4. Also from tarpaulin 3 cut two gable tops, each a triangle with a 4.0 m base and 0.9 m height. They fit together in a 6.0 x 0.9 m strip, one pointing up and one pointing down, so cut the strip first and then cut it along the two sloping lines.
5. At the two ground corners of each of the four lower strips, cut out a corner cable hem: a rectangle of 0.40 m along the ground edge and 0.20 m up. Fold the cut edges over by 40 mm and tape them, so the anchor eye and the first part of each cable stay clear of the skin.
6. Put eyelets or reinforced tape along every edge that is tied to a tube, 0.5 m apart, and a pair of ties at each door slit.

**How it fits the parts next to it.** The gable and side wall cables leave the anchor eyes just outside the wall line and climb to the eave rings. Each leaves its hem within 0.31 m of the eye, so a 0.40 m hem is wide enough; above it the cable lies behind the skin. The pieces overlap at the eaves, the corners and the gable tops by about 0.2 m, and are tied through their eyelets to the tubes, never to the nodes or the cables.

**Check before moving on.** Each piece is within 20 mm of its size; the strips lie flat on a flat floor; the door flap rolls up and ties.

### 3.12 Packing the kit

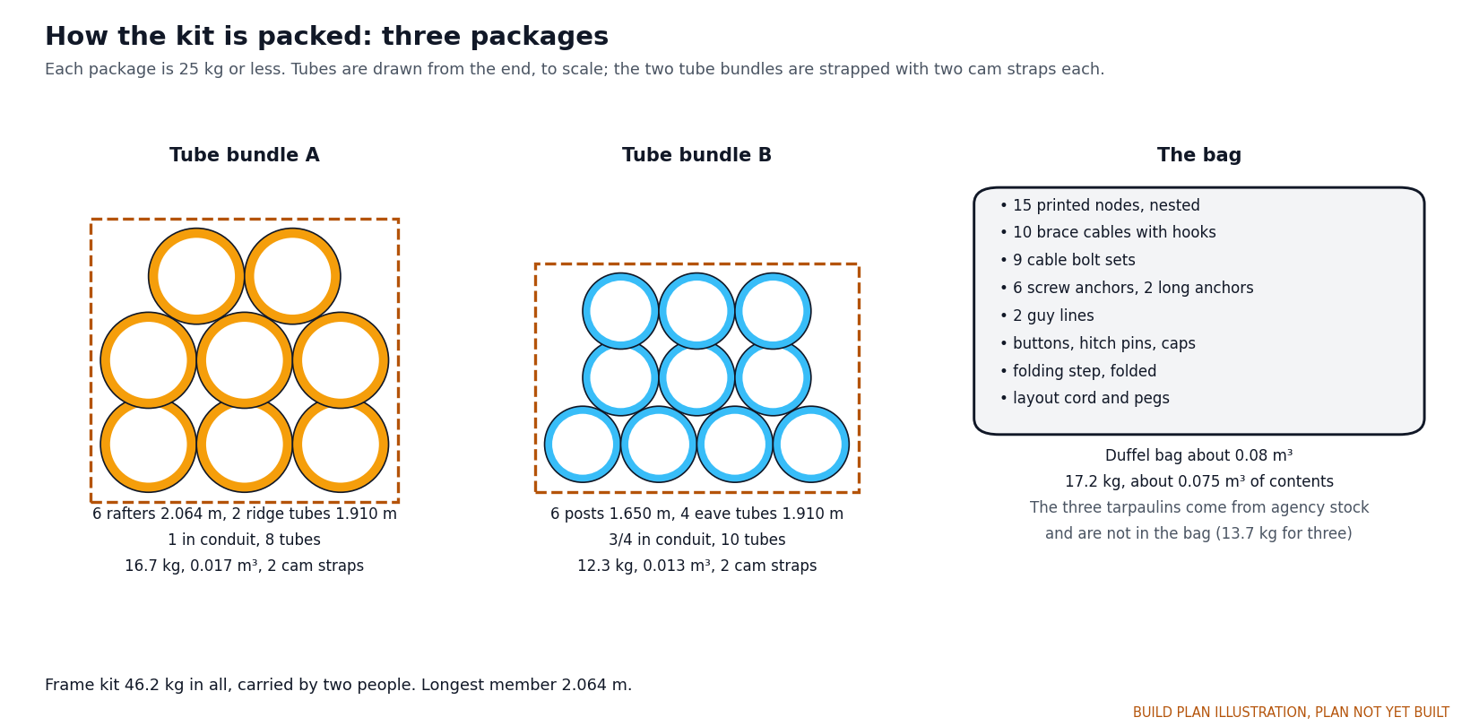
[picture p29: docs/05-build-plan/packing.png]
Figure 19. The three packages


*Figure 19. The kit in three packages: two tube bundles and a bag. The tarpaulins come separately from agency stock.*

Pack the rafters (6) and ridge tubes (2) as bundle A, with two cam straps, and the posts (6) and eave tubes (4) as bundle B, with two cam straps; each is 25 kg or less. Put the nodes, cables, cable bolt sets, anchors, guy lines, hardware, folded step, layout cord and pegs in the bag. About 16.7 kg, 12.3 kg and 17.2 kg are expected; weighing them is a first check (Table 2).

## 4. Putting it together

In each picture the parts already fitted are grey and the parts being fitted are in colour, with an arrow showing the way they go in. Work with two people, in light wind only.

### Step 1: mark out the floor

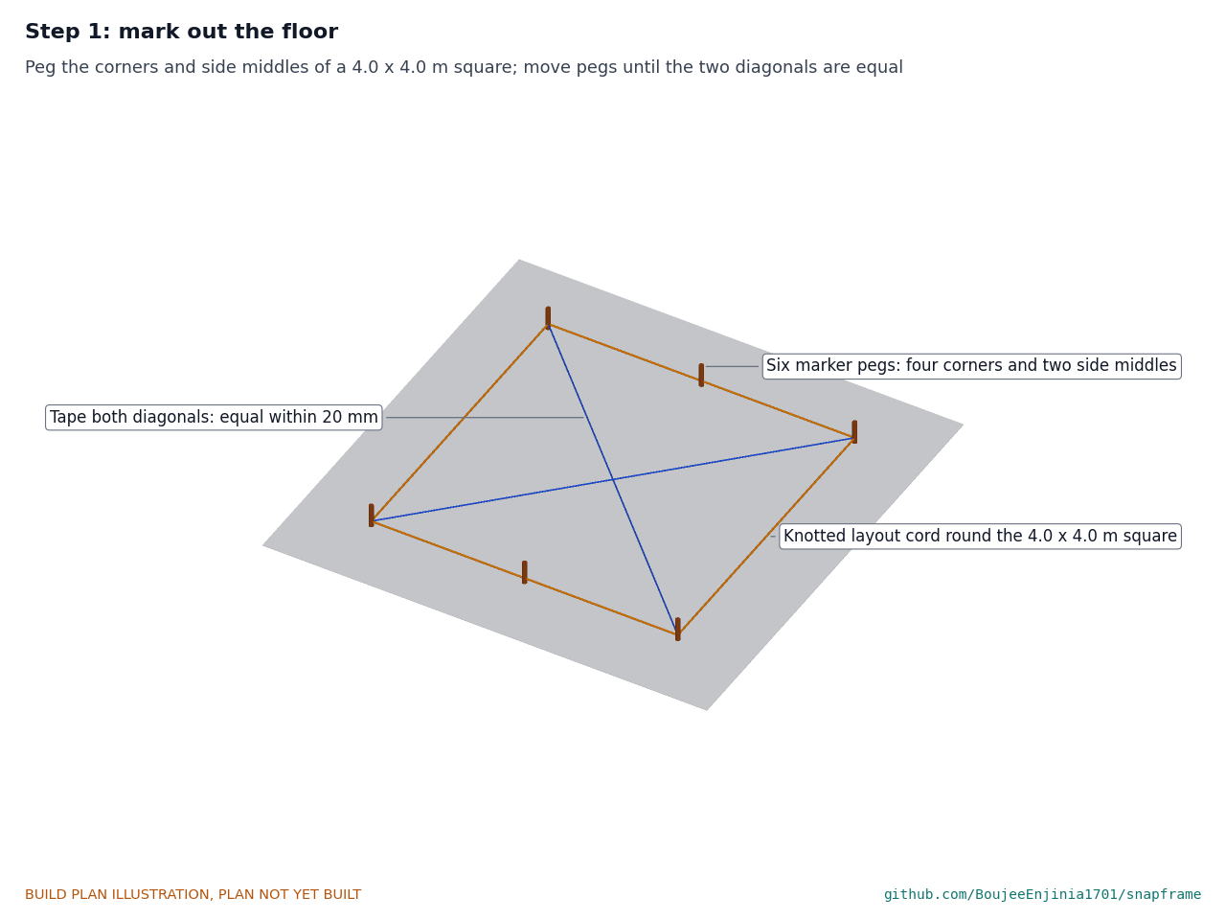
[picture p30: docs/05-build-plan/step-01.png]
Step 1


Peg the four corners and the two middles of the side walls of a 4.0 x 4.0 m square with the knotted layout cord. Measure both diagonals; move pegs until they are equal.

### Step 2: build the rear frame flat on the ground

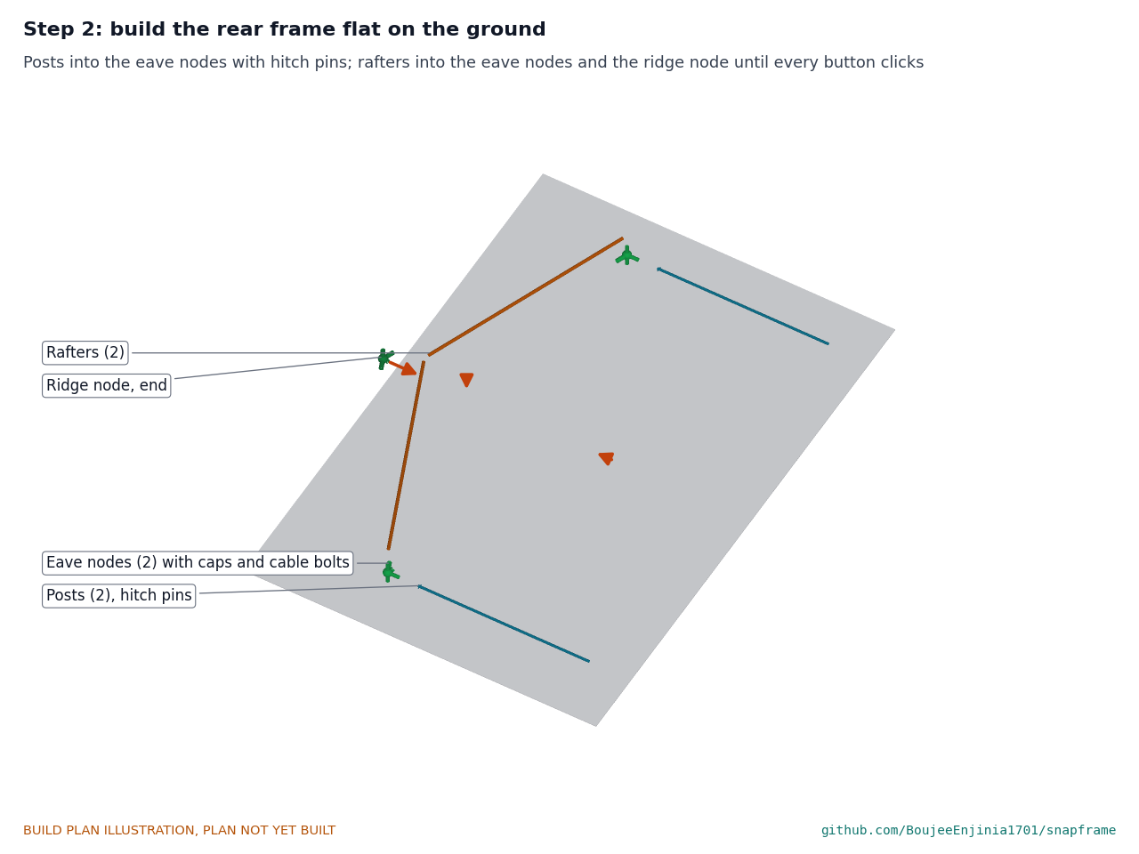
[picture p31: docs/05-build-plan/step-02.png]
Step 2


Lay the two eave nodes, two posts, two rafters and one end ridge node on the ground behind the rear pegs, as the frame will stand. Push each post into the post socket of an eave node until it clicks and put a hitch pin through. Push the rafters into the eave nodes and then into the ridge node until every button clicks. Push a cap into the socket that points away from the shelter on each eave node.

### Step 3: foot nodes onto the post ends

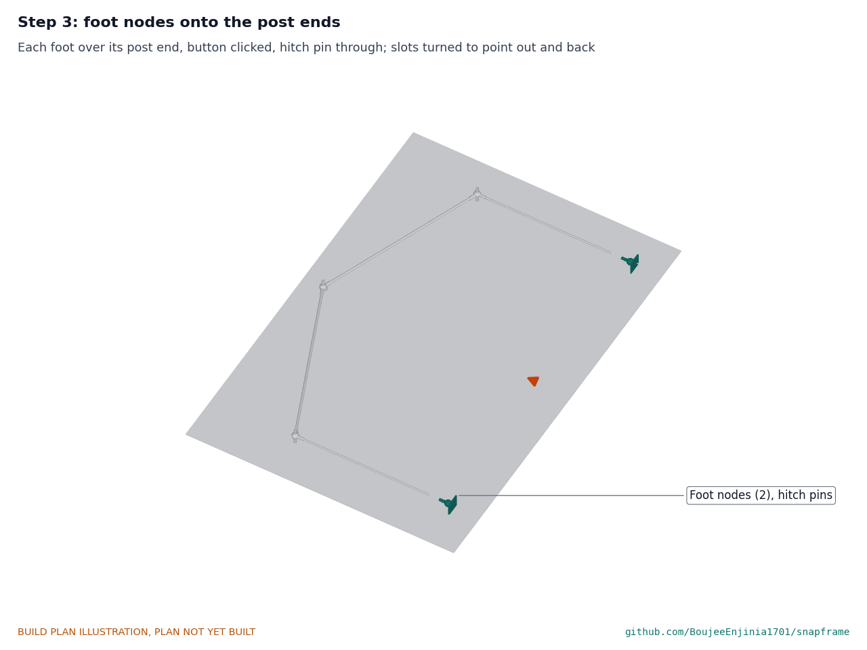
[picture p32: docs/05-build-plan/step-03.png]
Step 3


Push a foot node onto each post end until it clicks and put a hitch pin through. Turn each foot so its slots point outboard. Build the middle frame (no caps) and the front frame (with caps) the same way.

### Step 4: stand the rear frame on its marks

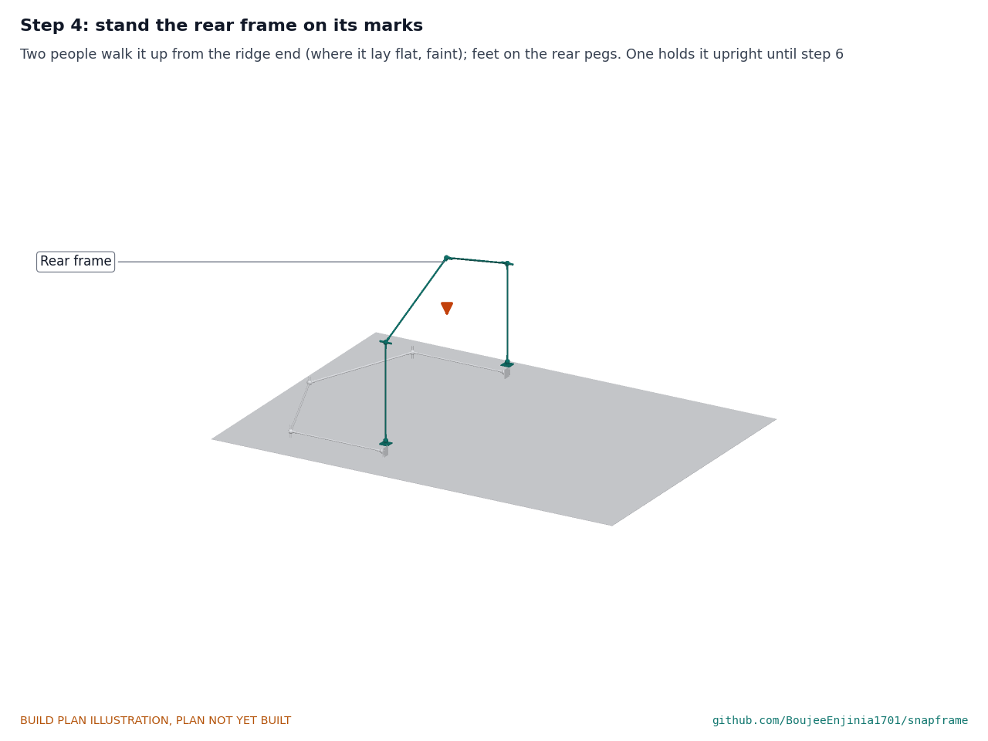
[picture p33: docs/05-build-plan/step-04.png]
Step 4


One person lifts the ridge end and walks toward the feet while the other holds the feet down; stand the frame upright with its feet on the rear pegs (pull the pegs). One person holds it upright until step 6.

### Step 5: eave tubes and ridge tube into the rear frame

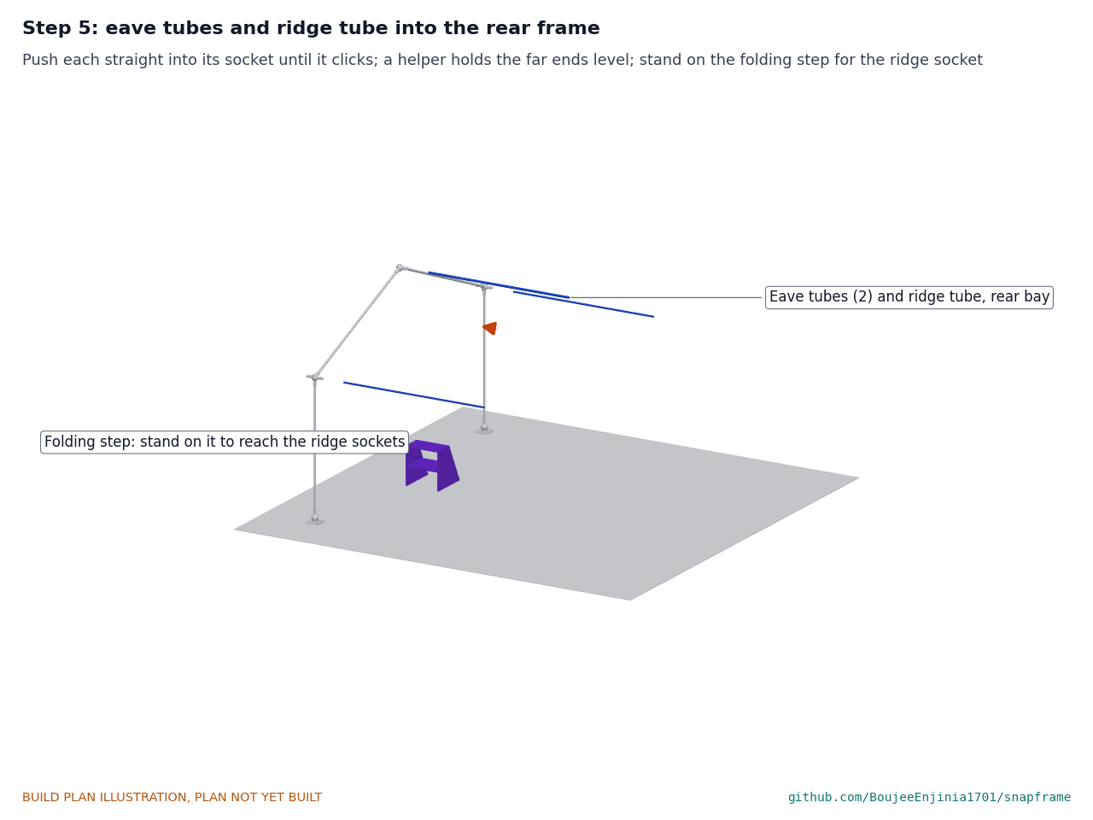
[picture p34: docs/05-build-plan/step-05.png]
Step 5


Push the two eave tubes and the ridge tube into the rear frame's sockets that point along the shelter, until each clicks. Hold the far ends level; stand on the folding step (shown in the picture) to reach the ridge socket, with one person on the step at a time.

### Step 6: slide the middle frame onto the tube ends

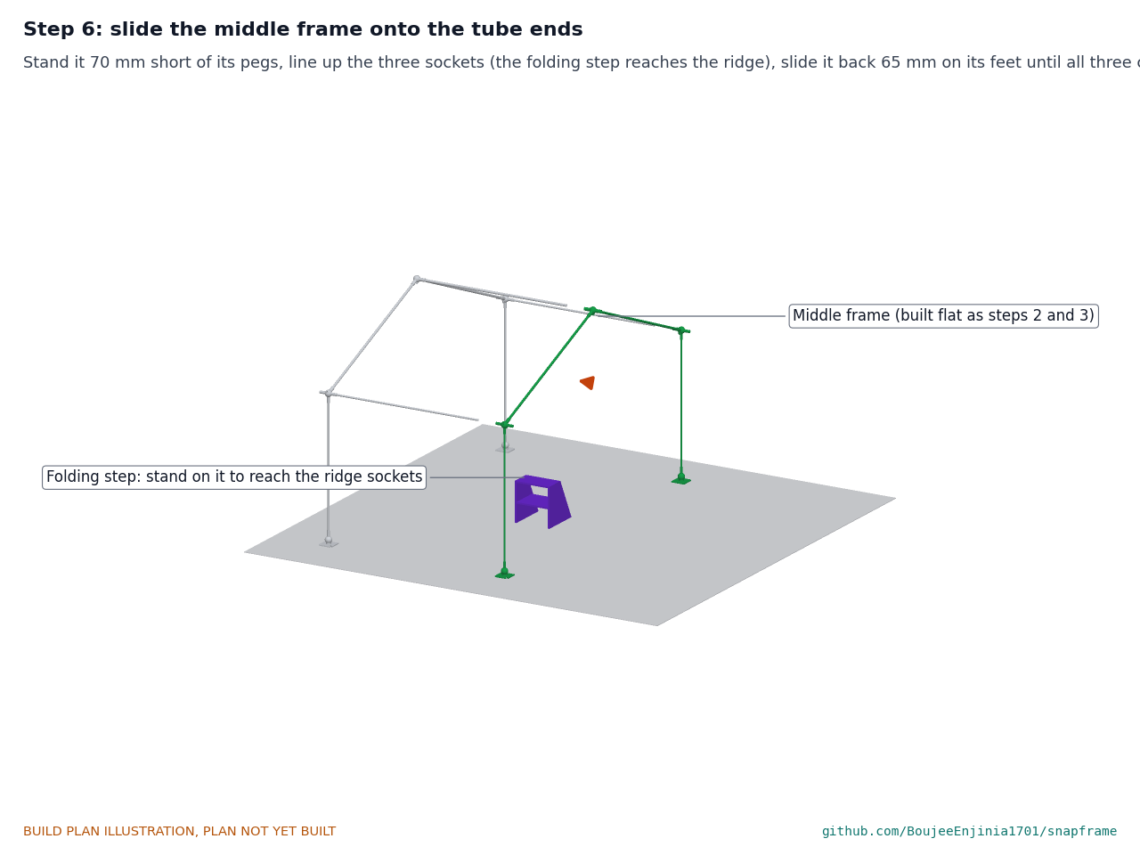
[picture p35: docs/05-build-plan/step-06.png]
Step 6


Stand the middle frame about 70 mm beyond its pegs. Line up its three sockets with the three tube ends (move the folding step under the middle ridge node), then slide the whole frame 65 mm on its feet toward the rear frame until all three buttons click. **Hold point:** all three joints clicked before anyone lets go.

### Step 7: front bay: tubes, then the front frame

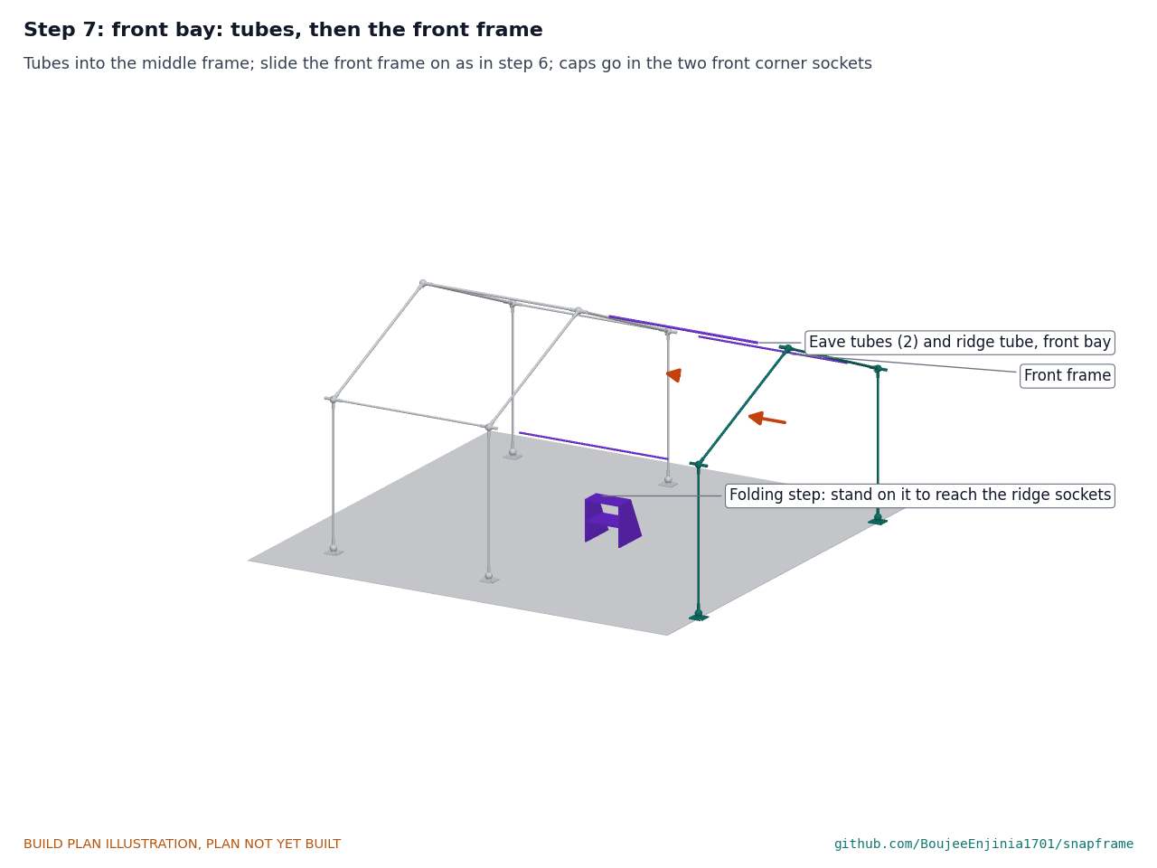
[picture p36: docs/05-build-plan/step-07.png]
Step 7


Push the front bay's two eave tubes and ridge tube into the middle frame, then slide the front frame onto them as in step 6, with the folding step moved into the front bay.

### Step 8: square the frame and turn in the anchors

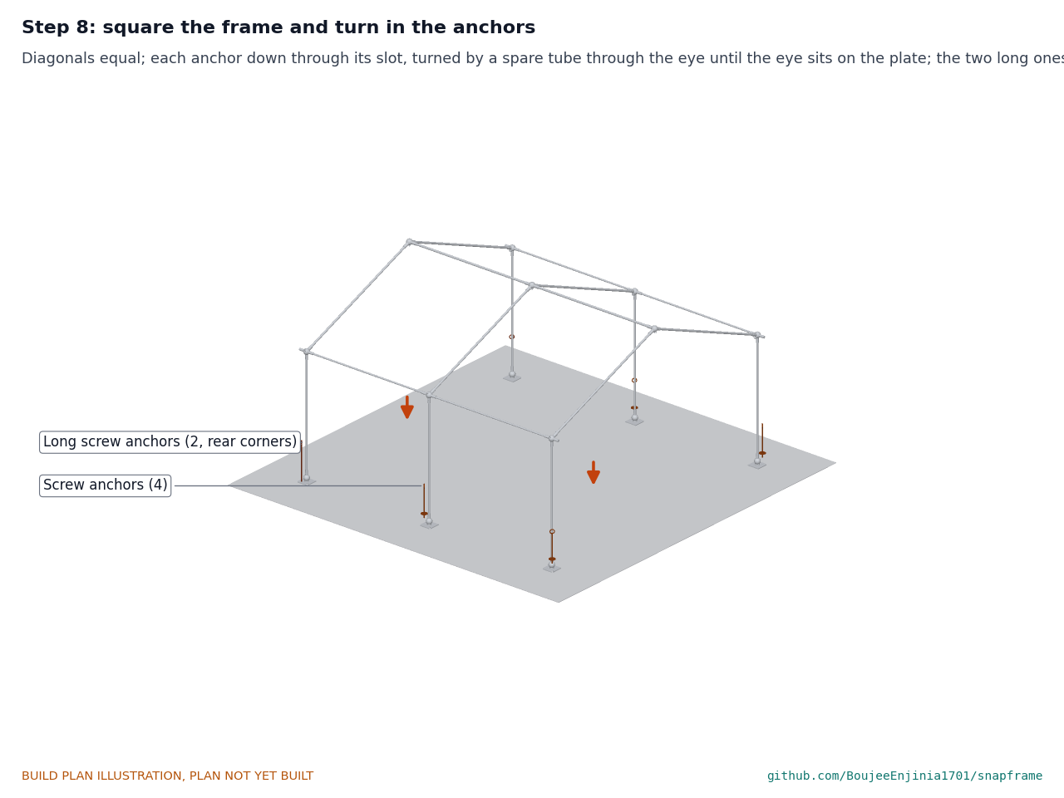
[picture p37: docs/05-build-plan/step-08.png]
Step 8


Check that both floor diagonals are equal within 20 mm; slide feet to suit. At each foot, put a screw anchor through the slot that points away from the middle of the shelter and turn it in by hand, using a spare tube through the eye as a lever, until the eye sits down on the plate across the slot. Use the two long anchors at the rear corner feet and the standard ones at the other four. **Hold point:** safety stop S4.

### Step 9: rear gable cables

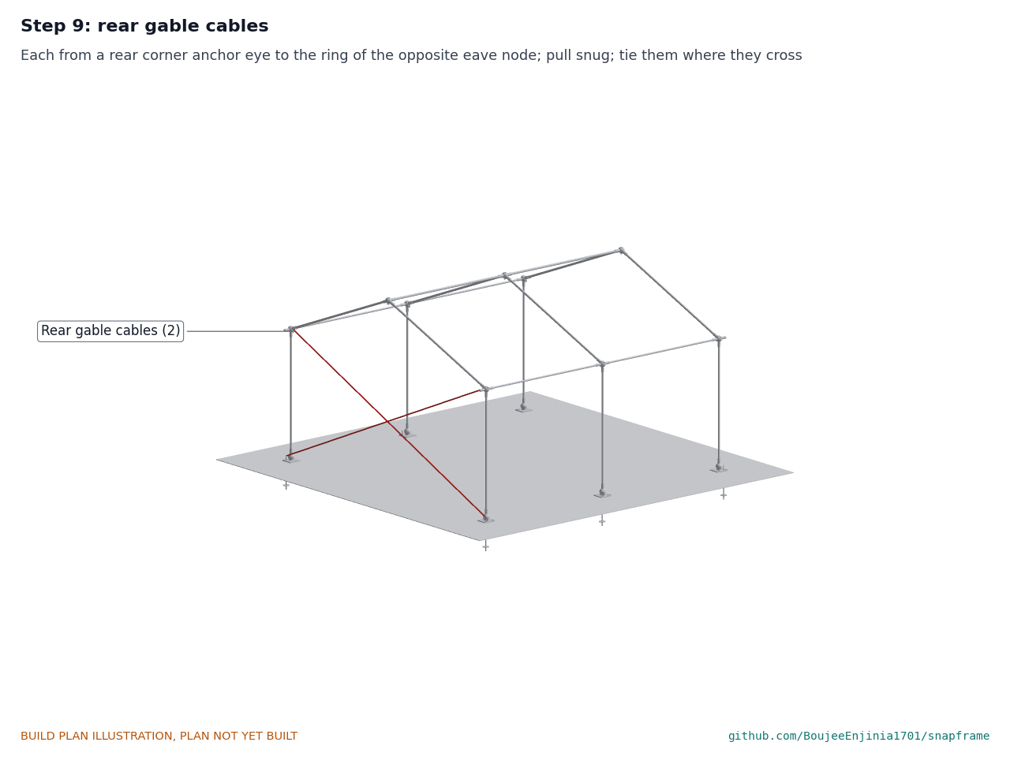
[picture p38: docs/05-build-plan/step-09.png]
Step 9


Seen from behind. Clip each gable cable's hook at the thimble end into a rear corner anchor eye and the other hook into the ring of the opposite rear eave node. Pull both snug with their tensioners, evenly, and tie them together with a cable tie where they cross.

### Step 10: side wall cables

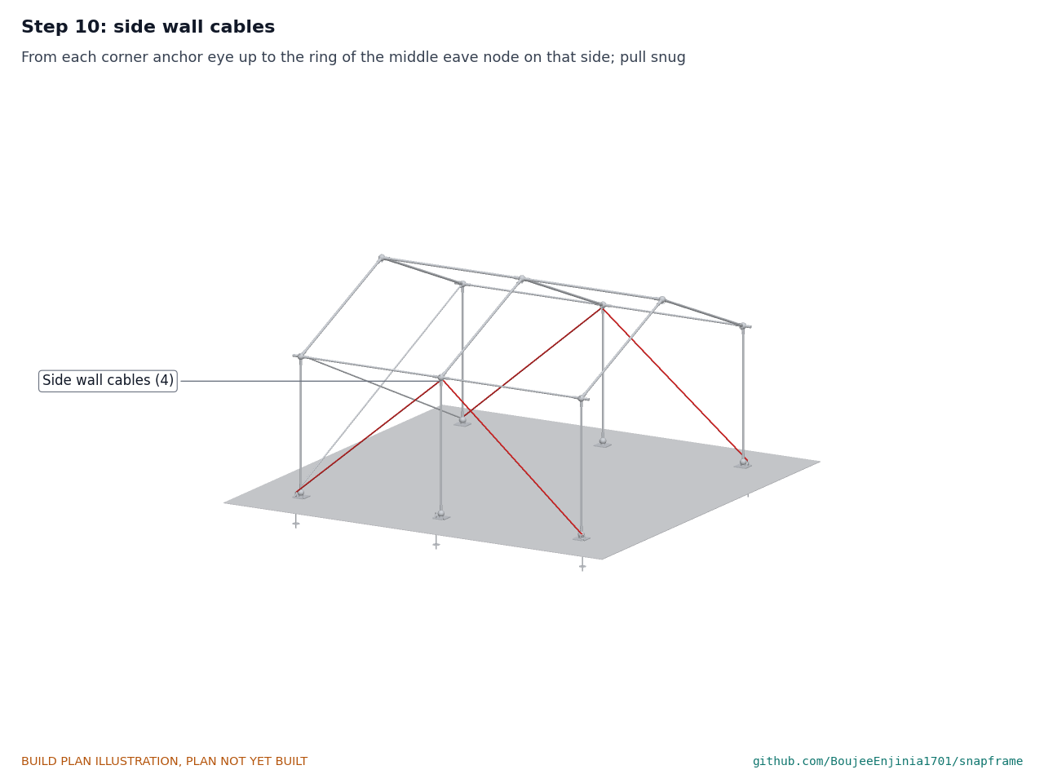
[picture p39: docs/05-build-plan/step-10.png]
Step 10


On each side, clip a wall cable from each corner anchor eye up to the ring of the middle eave node on that side. Pull snug.

### Step 11: roof cables

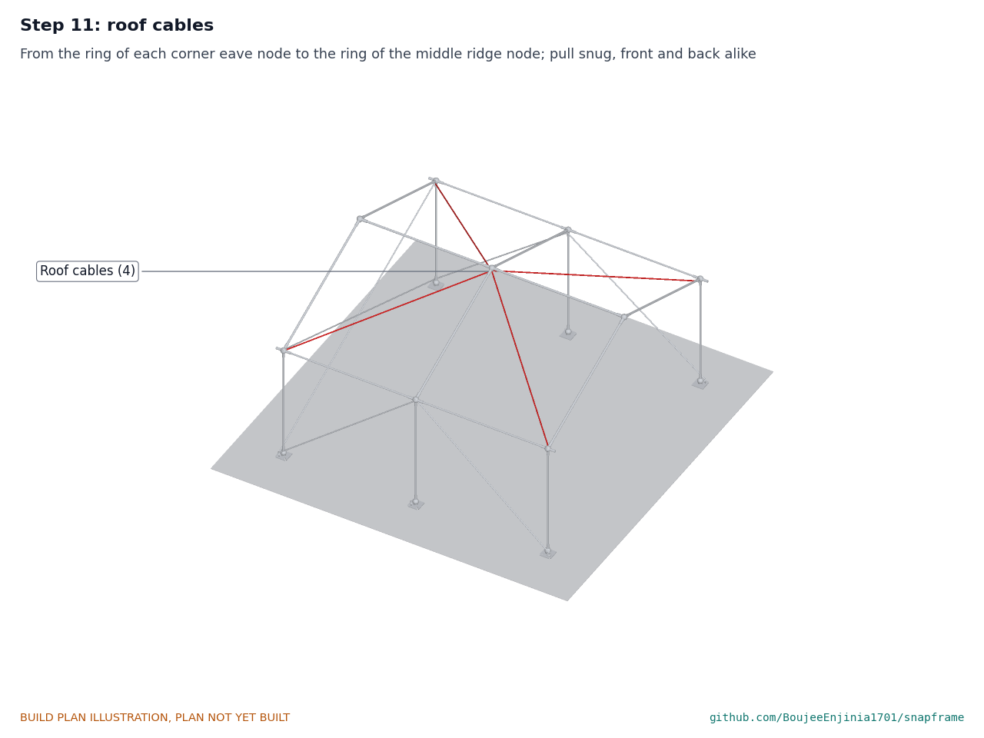
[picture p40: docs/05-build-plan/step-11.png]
Step 11


Clip a roof cable from the ring of each corner eave node to the ring of the middle ridge node. Pull all four snug, front and back alike, so the ridge stays straight.

### Step 12: guy anchors and guy lines

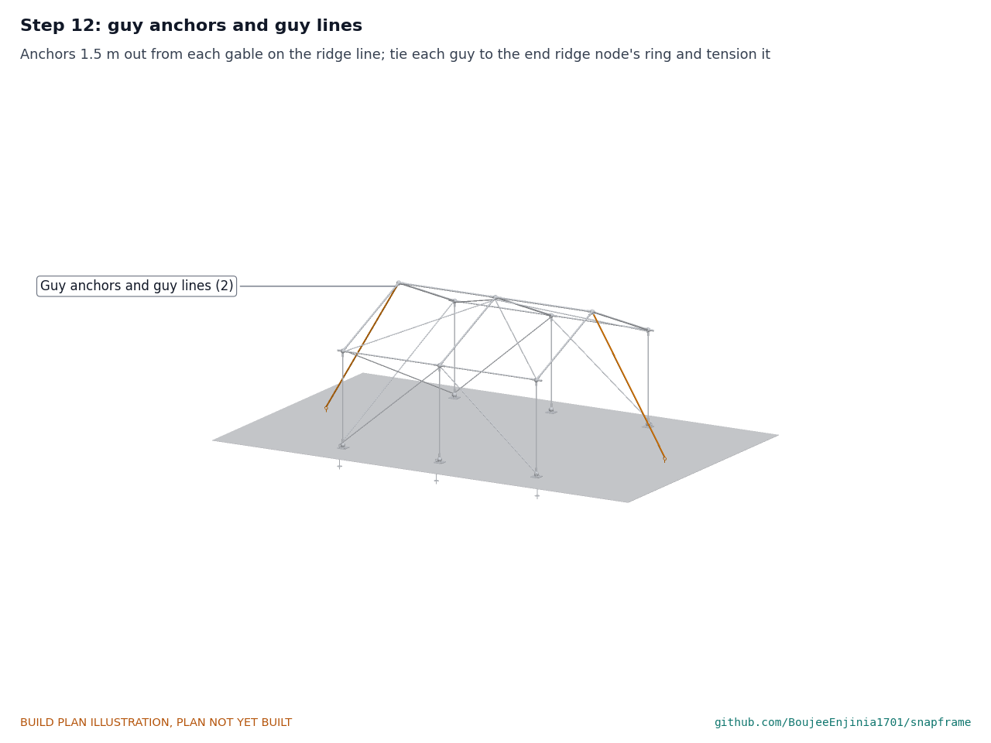
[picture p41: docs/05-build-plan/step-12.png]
Step 12


Turn in a guy anchor on the ridge line 1.5 m out from each gable. Tie each guy line to the ring of its end ridge node and to the guy anchor, and tension it with its slide tensioner. **Hold point:** safety stop S5.

### Step 13: tarpaulins

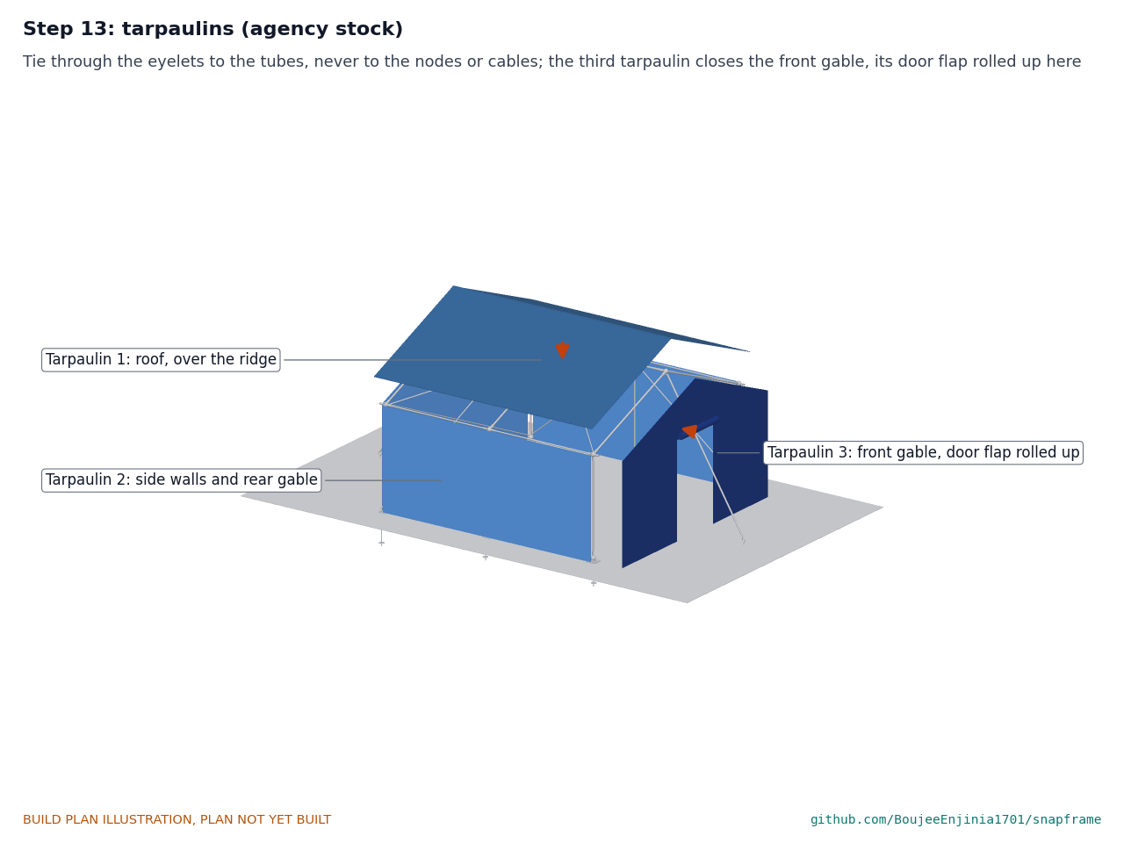
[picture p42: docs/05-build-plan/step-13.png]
Step 13


Throw the first tarpaulin over the ridge as the roof. Hang the three strips of the second on the two side walls and the rear gable, and the front gable strip of the third, with its door flap, across the front. Tie the gable tops in above them. Tie everything through the eyelets to the tubes, never to the nodes or the cables, with the corner cable hems round the anchor eyes (Figure 18). Roll the door flap up and tie it when the door is open. **Hold point:** safety stop S6.

## 5. First checks

These are the checks a TRL 4 test report would record; this plan only lists them. Requirement numbers are those of SNF-REQ-001.

*Table 2. First checks.*

| Check | Requirement | How | Pass when |
| --- | --- | --- | --- |
| Floor and squareness | R1 | Tape the sides and diagonals between the foot centres | 4.0 x 4.0 m within 20 mm; diagonals equal within 20 mm |
| Headroom | R2 | Measure from the floor to the underside of the rafters across the span | 2.0 m or more over the middle 2.9 m |
| Joints by hand | R4, R12 | Undo and remake one joint of each tube type with a fingertip only | Each button presses flush and the tube comes out and clicks back without tools |
| Part replacement | R12 | Replace one post and one rafter in the standing frame | Each in 5 minutes or less |
| Anchors | R8 | Pull one middle or front anchor and one long rear corner anchor up with a hand scale or a lever and scale | The standard anchor holds 1.0 kN and the long one 1.5 kN; record the soil |
| Cables | R6 | Pull each cable to about 300 N with its tensioner and a hand scale | No clip or tensioner slips; the frame stands plumb |
| Frame stiffness | R6 | Push sideways at an eave node and along the ridge with about 100 N | The frame moves a little and returns; no joint opens |
| Tarpaulin fit | R7 | Cut and fit the three tarpaulins as section 3.11 and step 13 | Roof, both side walls and both gables closed; the door flap opens and ties |
| Mass and packages | R5, R11 | Weigh the two tube bundles and the bag | Bundles about 16.7 and 12.3 kg, bag about 17.2 kg (all recorded), each 25 kg or less |
| Erection time | R4 | Two adults who have not seen the kit, with the picture guide | Frame and skin up in 60 minutes or less |

## 6. Safety stops

Stop at each point. Carry on only when everything listed is true.

- **S1. Before cutting and drilling.** Safety glasses on; tube clamped in a vice or vee block, never held by hand under the drill; gloves for handling cut ends.
- **S2. Before printing.** The printer is in a ventilated space or has a filtered enclosure; nylon and other engineering polymers give off fumes while printing.
- **S3. Before a frame is stood up.** Every button clicked and every hitch pin in; two people; wind light (no tarpaulin on the frame). The folding step stands level on firm ground with one person on it at a time.
- **S4. Before any anchor is turned in.** The site is checked for buried cables and pipes with whoever owns them; no anchor within 0.5 m of a marked service.
- **S5. Before the cables and guys are tensioned.** Gloves on; nobody stands in line with a cable while it is being tensioned; tensioners pulled by hand only, never with a bar; guy lines marked with reflective tape.
- **S6. Before the tarpaulins go on.** All anchors, cables and guys fitted and tensioned; wind light. A tarpaulin on an unbraced frame is a sail.
- **S7. Before anyone shelters in it (outside this plan).** The wind rating (about 19.5 m/s, and about 14.7 m/s with the door flap open and wind blowing into it) is posted on the frame; no snow or standing water on the roof; cooking and open flames kept outside; at least 2 m to the next shelter where the site allows; low-voltage lighting only.

## 7. Tools, skills and workspace

**Tools.** Pipe cutter for 3/4 in and 1 in conduit, or a hacksaw with a 32 teeth per inch blade; inside reamer and flat file; tape measure, steel rule, marker, a 2 m straight edge (a length of aluminium angle) for the hole line, and a centre punch; bench drill or a drill in a stand, with a vee block and drills of 3, 6 and 8 mm; deburring tool; 3D printer with a bed of at least 230 mm and a hardened nozzle that prints glass- or carbon-filled PA12-class nylon (or a print farm); 16 or 17 mm spanner and a deep socket that fits a 27 mm recess; wire rope cutters and a 10 mm spanner for the rope clips; hand scale to 50 kg; knotted layout cord and six pegs; the folding step (line 15); a sharp knife or hot knife and a straight edge for cutting the tarpaulins, and a punch or eyelet tool; gloves and safety glasses.

**Skills.** No certified trade is needed. Basic metalwork (measuring, cutting and drilling thin-wall tube), running a 3D printer, bolting, and making up wire rope ends with clips. No electrical work is part of this build.

**Workspace.** A bench about 2.5 m long for the tubes, or two trestles; a ventilated place for the printer; and a flat, open site at least 8 x 7 m clear of overhead lines and buried services for the first erection, including the guy anchors 1.5 m beyond each gable.

**Personal protective equipment.** Safety glasses for cutting, drilling and anchor work; cut-resistant gloves for conduit ends and wire rope; hearing protection when sawing; no gloves near a turning drill.

## 8. Where the numbers come from

- Model and constructability checks: `cad/src/model.py` (`python cad/src/model.py --check`, 214 checks); STEP and STL exports in `cad/step/` and `cad/stl/`.
- Pictures: `cad/src/build_plan_media.py`, using `.kit/build_views.py`; written to `docs/05-build-plan/` and `cad/drawings/SNF-DWG-101` to `SNF-DWG-109`. The cutting plan is checked by `cad/src/skin_plan.py` (19 checks).
- General arrangement: `cad/drawings/SNF-DWG-001.pdf`, Rev P5.
- Calculations: `docs/04-calcs/01-sizing.md` (SNF-CAL-001 v0.6) and `docs/04-calcs/sizing.py`; frame analysis, section 5; cable bolt and hitch pin, section 6; masses and costs, section 7; skin, section 8.
- Bill of materials: `bom/bom.csv` and `bom/bom-notes.md`.
- Decisions: `docs/decisions/0003-design-for-construction.md` (SNF-DDR-003), with SNF-DDR-001 and SNF-DDR-002; open items in `docs/06-design-decisions.md` (SNF-DEC-001).
- Requirements: `docs/03-requirements.md` (SNF-REQ-001 v0.8).

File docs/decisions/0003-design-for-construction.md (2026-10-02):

---
doc_id: SNF-DDR-003
title: SnapFrame design for construction
project: SnapFrame
doc_type: Design decision record
version: "0.2"
status: Draft
date: '2026-10-02'
author: Amish Chadha
license: CERN-OHL-S-2.0
revisions:
- version: "0.1"
  date: '2026-10-01'
  author: Amish Chadha
  change: Changes that make the concept physically buildable, with the reason for each; made under Amish's 2026-09-30 instruction to make the design physically buildable; open for his review
- version: "0.2"
  date: '2026-10-02'
  author: Amish Chadha
  change: "Accepted by Amish on 2026-10-02, with A1 sharpened (folding step for the first prototype) and A2 as recommended"
---

# 0003: Design for construction

- **Date:** 2026-10-01
- **Status:** accepted. Amish, 2026-10-02: "i approve your recommendations for all 555 open decisions." This covers the changes C1 to C9 and items A1 and A2 in Table 3, now decided and recorded in the design decisions register (SNF-DEC-001). A1 is decided in a sharpened form: the first prototype uses a folding step, ground guiding is timed at TRL 4, and the step stays in the kit if ground guiding is slower or needs a third person. A2 is decided as recommended, with the front gable closed by part of a third tarpaulin cut to include a door flap.

## Context

On 2026-09-30 Amish asked for every repo's build plan to show how each component is made and how it fits the next, with pictures, and wrote: "If you are realising that the design cannot be built as per concept - fix the design assumptions to match and be physically feasible as you draw the illustrations." The concept model of SNF-DDR-002 shows what SnapFrame does, but checking it with build123d and walking through the build found nine places where it could not be made, fixed or put up as drawn (C1 to C9 below).

The changes keep what the frame does: the same size M gable, floor, heights, tube sizes and lengths, node family (three types in four printed variants, none handed), spring buttons at every tube end, hitch pins at the 12 tension joints, cable bracing layout, anchors and tarpaulins. Nothing here changes the pitch or the safety case. Every change is in `cad/src/model.py`, which now also runs 203 constructability checks (`python cad/src/model.py --check`): parts that must touch do touch, parts that must stay apart are apart by at least the stated clearance, the button holes of every tube line up with its sockets, and every node fits a 256 mm print bed. All 203 pass.

## Decision

*Table 1. Changes made to the model, the BOM and the calculations.*

| # | Problem in the concept | Change made | Why this way |
| --- | --- | --- | --- |
| C1 | Spring button 25 mm and hitch pin hole 50 mm from the tube end. The V spring of a snap button runs from about 5 mm nearer the end than its button to about 45 mm deeper (20 to 65 mm), so the 8 mm hitch pin would pass through the spring. | Button hole 40 mm and hitch pin hole 15 mm from the tube end (85 mm and 60 mm from the node centre). The spring now lies 35 to 80 mm from the end, 16 mm clear of the pin. | Keeps both locks of SNF-DDR-001 D4. The pin moves toward the tube end rather than the button toward it, so the spring never crosses the pin. The steel behind the pin still resists 9.0 kN of shear-out (was 37.8 kN), seven times the 1.28 kN worst foot load [SNF-CAL-001 section 6]. |
| C2 | A 6 mm button hole through a 5 mm socket wall: the button sits below the outer surface and a fingertip cannot press it, so the joint could not be undone by hand (R4, R12). The socket mouths had square edges for the button to catch on. | A 16 mm finger recess round every button hole, leaving 1.5 mm of wall, so the button stands about 2 mm proud of the recess floor; a 1.5 mm lead-in chamfer at every socket mouth. | The tent-pole arrangement: press the button with a fingertip and pull. The chamfer pushes the button in as the tube enters. |
| C3 | Brace cables were drawn from node centre to node centre, through the printed cores. The eave nodes had an 18 mm printed tab pointing outward and down, away from most of the cables it was meant to hold; at the 1.21 kN gable cable load it would carry about 46 MPa in bending, more than printed polymer can take with the factor of 2 of R9. The middle ridge node, which takes four roof cables, and the foot nodes had no fixing at all. | Every eave node and ridge node gets a cable bolt set through its core: a stainless M10 x 90 bolt with a 30 mm washer on a flat spot face, a 14 mm spacer carrying a welded 6 mm steel ring of 32 mm bore, a 24 mm washer under the head, and a washer and nyloc nut in a recess on the far side. On the eave nodes the bolt points inward and 35° down, between the post and rafter sockets; on the ridge nodes it points straight down. The cables have a snap hook at each end that clips into the ring. The printed tabs are removed. | A bolt through the core carries cable pulls from any direction; the ring swings to line up with them, and up to four snap hooks share it. The shank sees 171 MPa at the worst node (factor 2.6 on A4-70 stainless) and the polymer about 5.6 MPa in bearing. Nothing is loaded in printed bending. The nut sits below the surface, so nothing stands proud under the tarpaulins. |
| C4 | The lower ends of the cables had nowhere to attach at the feet. | The lower snap hook of each gable and side wall cable clips into the screw anchor eye at that foot. | The cable's uplift goes straight into the anchor, which is how SNF-CAL-001 already added up the worst foot load (1.28 kN). |
| C5 | The screw anchor eye stood 32 mm above the foot plate, so a foot could lift 32 mm before its anchor held it. | Each anchor is turned in until its eye sits down on the plate across the slot (eye centre about 45 mm above the ground). | The eye clamps the plate as soon as it is snug. Any turn of the eye except along the slot bears on both slot edges. |
| C6 | One anchor slot, straight out to the side. The rear gable cable leaves its anchor inward and up at about 23°, and from a slot straight out to the side it would pass 33 mm from the foot node's centre, through the 84 mm core. | Two slots in the plate, at 45° either side of straight out, each open to a plate corner and round-ended 62 mm from the centre. Rear feet use the slot that points backward, front feet the one that points forward, middle feet either. | The gable and side wall cables then pass 10 mm or more clear of the foot nodes, posts and sockets. The foot node stays one printed variant and is not handed (R12). |
| C7 | The concept put the anchors in first, dropped the frames into the anchored feet, then joined them with eave and ridge tubes. A 1,910 mm eave or ridge tube cannot be fitted between two fixed sockets whose mouths are 1,780 mm apart; it needs 65 mm of movement at one end. | Each gable frame is built flat with its feet on, stood on its marks unanchored, and the eave and ridge tubes go into the frame already standing. The next frame is stood 70 mm short of its marks and slid 65 mm on its feet onto the three tube ends. The anchors go in last, after the frame is squared. | No part changes; only the order. A frame of about 7 kg on two foot plates slides easily on the ground. |
| C8 | The guy lines were tied to printed tabs on the end ridge nodes, as in C3. | Each guy line ties to the ring on the end ridge node's cable bolt. | Same part as C3, no extra fixing. |
| C9 | The concept did not say where each tube's holes go. | The two button holes of every tube are on opposite sides of the tube, on one marked line; hitch pin holes in the posts go through on that line. This holds for all 18 members, so every tube of a type is the same and fits any position. | One drilling rule for every tube, checked in the model for each member. |

*Table 2. Knock-on changes.*

| Item | Change | Reason |
| --- | --- | --- |
| BOM | Line 5 to 7: node specs updated (finger recesses, chamfers, cable bolt holes, two anchor slots) and node prices from the new volumes. Line 8: cables now with a snap hook at each end, thimble and clips, eye-to-eye lengths, $4.20 each (was $3.50). Line 12: snap buttons sized for each tube. New line 14: nine cable bolt sets at $2.60. | Parts added and specified for construction. |
| Mass | Frame kit 42.0 to 43.3 kg; with tarpaulins 51.1 to 52.5 kg (R11 now 2.5 kg over, was 1.1 kg); bag 13.4 to 14.7 kg without tarpaulins. Printed nodes 4.97 to 4.76 kg. | The cable bolt sets add 1.17 kg and the second snap hooks about 0.5 kg; the removed tabs and the new recesses save 0.2 kg of print. |
| Cost | Frame kit $443.30 to $469.14 against the unchanged $445 value-engineering target (`budget_usd`): $24.14 over the target. | Cable bolt sets $23.40, second snap hooks $7.00, nodes $4.56 cheaper. |
| Cable lengths | Eye to eye: gable 4,230 mm, side wall 2,520 mm, roof 2,750 mm; 29.5 m of wire in all (31.1 m node to node in v0.3). | Measured between the real attachment points in the model. |
| Drawings | SNF-DWG-001 Rev P4; making sketches SNF-DWG-101 to 109 added. | Follows the model. |
| Documents | SNF-CAL-001 v0.4, SNF-REQ-001 v0.6, SNF-PRC-001 v0.6: mass, cost, cable, pin and erection-order figures updated; cost reported against the value-engineering target. No met requirement became not met; R10 is now reported against the value-engineering target. | Follows the model. |
| Wind, anchors, snow | Unchanged: tube sizes, node positions and cable layout are the same. | |

*Table 3. Proposed, then decided by Amish on 2026-10-02.*

| # | Question | Options | Recommendation |
| --- | --- | --- | --- |
| A1 | Guiding the ridge tubes into their sockets at 2.6 m during the slide-on of C7. R4 asks for erection without tools; a person standing on the ground reaches about 2.2 m. | (a) a folding step in the kit (about 1.5 kg); (b) guide the ridge tube from the ground with a spare tube; (c) build the roof low and lift it onto the posts. | (b), and time it in the TRL 4 user trial before adding a step; the build plan uses a step for the first prototype. **Decided 2026-10-02:** a folding step for the first prototype; (b) timed in the TRL 4 user trial; the step stays in the kit if (b) is slower or needs a third person. |
| A2 | Where the side wall tarpaulin's lower edge passes the cables at the corner anchors (the cables leave the anchor eyes just outside the wall line). | (a) tuck the hem inside the cable at each corner; (b) a short slit with an eyelet; (c) settle it in the cutting and folding plan of R7 (open item O3). | (c), since R7 already needs a tarpaulin plan. **Decided 2026-10-02: (c)**, in the cutting plan that closes the front gable with part of a third tarpaulin. |

## Consequences

- `design_state: constructable` in `project.yaml`. The build plan SNF-BLD-001 shows every component and step in pictures generated from the model (`cad/src/build_plan_media.py`).
- Requirement status (SNF-CAL-001 v0.4, before the decisions of 2026-10-02): 4 met, 5 not met, 2 at risk, 1 not verifiable at TRL 3, and R10 reported against the value-engineering target, $24.14 over (in v0.3 R10 was counted as met within the $445 figure). R11 is further from its target: 2.5 kg over, was 1.1 kg. With R5, R7, R8 and R11 restated on 2026-10-02 (SNF-DEC-001): 7 met, 2 not met (R6, R13), 2 at risk (R8, R9), 1 not verifiable at TRL 3 (R4).
- The photoreal renders (`media/render-*.png`), the storefront images and the appearance model `cad/src/product_model.py` still show the printed cable tabs, the old button and pin positions and the single anchor slot; they need updating on Amish's Mac, where Blender is.
- Bought parts to confirm before buying are listed in the design decisions register (SNF-DEC-001): snap button spring length and height, snap hook gate opening, ring and tensioner ratings, anchor eye fit on the plate.

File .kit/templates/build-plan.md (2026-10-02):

---
doc_id: PRJ-BLD-001
title: Project prototype build plan
project: Project name
doc_type: Build plan
version: "0.1"
status: Draft
date: YYYY-MM-DD
author: Amish Chadha
license: CERN-OHL-S-2.0
revisions:
  - version: "0.1"
    date: YYYY-MM-DD
    author: Amish Chadha
    change: First build plan; design made constructable
---

# Project prototype build plan

**Plan, not yet built.** How to build the first proof-of-concept prototype, component by component. Building and testing to it is TRL 4 work. Decisions still to be made are kept in the design decisions register (`docs/06-design-decisions.md`), not here.

## 1. What you are building

Every component, pulled apart and numbered in build order

One short paragraph: what the prototype is, how many components, which are made and which are bought, and the main ways they are made.

## 2. What changed to make it buildable

| Component | The concept had | The buildable design has | Why |
| --- | --- | --- | --- |

## 3. Making the components

### 3.1 Component name

Making sketch

**What it is and what it is made from.**

**How to make it.**

1. Mark out ...
2. Cut ...

**How it fits the parts next to it.**

Close-up of the joint

**Check before moving on.**

## 4. Putting it together

### Step 1: ...

Step 1

## 5. First checks

| Check | Requirement | How | Pass when |
| --- | --- | --- | --- |

## 6. Safety stops

## 7. Tools, skills and workspace

## 8. Where the numbers come from

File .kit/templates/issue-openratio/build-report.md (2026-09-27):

---
name: Build report
about: Tell us what happened when you built, printed or tested part of this design
title: "Build report: "
labels: build-report
---

This is a research and educational prototype, not a medical device. It is a TRL 3 concept and is not released for fabrication. If you build any part of it, you do so at your own risk. Reports help everyone.

**What you built** (part, sub-assembly or test)

**Materials, tools and settings**

**What worked**

**What did not work, with photos or measurements if you have them**

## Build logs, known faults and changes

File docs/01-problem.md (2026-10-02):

---
doc_id: SNF-PRB-001
title: SnapFrame problem statement
project: SnapFrame
doc_type: Problem statement
version: "0.7"
status: Draft
date: '2026-10-02'
author: Amish Chadha
license: CERN-OHL-S-2.0
revisions:
- version: "0.1"
  date: '2026-09-24'
  author: Amish Chadha
  change: Initial scaffold
- version: "0.2"
  date: '2026-09-25'
  author: Amish Chadha
  change: Populate to TRL 2 (problem, users, context, constraints, out of scope, prior work, open questions)
- version: "0.3"
  date: '2026-09-25'
  author: Amish Chadha
  change: Apply SNF-DDR-001 (budget covers the frame kit, snow and cyclone out of scope); citations checked and deep-linked
- version: "0.4"
  date: '2026-09-25'
  author: Amish Chadha
  change: Recommendations accepted by Amish (DDR-002)
- version: "0.5"
  date: '2026-09-26'
  author: Amish Chadha
  change: Stronger sources
- version: "0.6"
  date: '2026-09-26'
  author: Amish Chadha
  change: Budget approved by Amish ($445, SNF-DDR-002)
- version: "0.7"
  date: '2026-10-02'
  author: Amish Chadha
  change: "First partners decided by Amish on 2026-10-02; IFRC Shelter Research Unit and Field Ready named as first candidates to approach"
---

# SnapFrame problem statement

After a disaster, families need a covered, weather-tight space within days, and the frame that holds up the sheeting is the hard part: it must ship compactly, go up without tools or skilled labor, and survive wind. Standard relief tarpaulins are everywhere; a frame that fits them, built from a steel tube sold in almost every hardware store, is not. Design with, not for: requirements must come from co-design sessions and field trials with the intended users through a local partner.

## The problem

In the first weeks after an earthquake, flood or storm, the most common shelter response is plastic sheeting over whatever frame people can find. The International Federation of Red Cross and Red Crescent Societies (IFRC) shelter kit, for example, provides two 4 x 6 m woven plastic tarpaulins, rope, fixings and tools, but leaves the frame to locally found timber or bamboo ([IFRC and ICRC items catalogue, shelter kit KRELSHEK02](https://itemscatalogue.redcross.int/relief--4/shelter-and-construction-materials--23/shelter-and-construction-kits--104/shelter-kit--KRELSHEK02.aspx)). Where timber is scarce, costly or has been used up, the result is low, sagging shelters that collapse in wind and use the sheeting badly.

Purpose-built alternatives sit at the other extreme:

- **Family tents** are quick to deploy and familiar, but they are single-purpose. The UNHCR family tent gives 16 m² of main floor plus two 3.5 m² vestibules ([UNHCR family tent fact sheet](https://unis.unvienna.org/pdf/factsheets/UNHCR_tent.pdf)), and when the canvas wears out, the poles are rarely reused.
- **Flat-pack shelters** such as Better Shelter give 17.5 m² with a steel frame and rigid panels ([Better Shelter, Relief Housing Unit](https://bettershelter.org/relief-housing-unit-rhu/)). They are robust, but cost far more than a tent, arrive as a large crate and depend on one supplier for spare parts.
- **Improvised steel frames** from electrical metallic tubing (EMT) conduit are already common for event shade and geodesic domes, where tube ends are flattened, drilled and bolted ([Domerama, strut flattening](https://www.domerama.com/fabricating/making-the-struts/geodesic-dome-struts-flattening/)). They are cheap, but each needs a pipe bender, a drill, bolts and spanners on site, and bolted joints loosen.

The gap is a frame kit that uses a globally stocked tube (EMT, made to ANSI C80.3 in North America and to similar metric standards elsewhere), connects with pre-made nodes that lock by hand, ships as a bundle of straight tubes and a box of nodes, and is sized to the tarpaulins that relief agencies already stock. Nodes are generated from parameters so that one design covers several shelter sizes, and can be printed near the response or cast in aluminum at scale.

## Users and context

| User | Need | Context |
| --- | --- | --- |
| Displaced household (four to six people) | A covered living space of 3.5 m² or more per person, the Sphere minimum for warm climates ([UNHCR Emergency Handbook, shelter standards](https://emergency.unhcr.org/emergency-assistance/shelter-camp-and-settlement/shelter-and-housing/emergency-shelter-solutions-and-standards)), with standing headroom, up on the first day | Camps, host-family plots, the site of a damaged home; warm to temperate climates in the first release |
| Shelter team of a relief agency or NGO | A kit that fits existing tarpaulin stock, ships densely, can be put up by the family with a short demonstration, and can be counted and repaired | Pre-positioned stock, mixed logistics (truck, pickup, boat) |
| Community builder or local fabricator | Standard tube, printable or castable nodes, open files, no welding | Makerspace, university lab, small foundry or print farm near the response |
| Household moving from emergency to transitional shelter | A frame that can later carry better cladding (timber, corrugated sheet, woven mats) or be reused as a store or shade | The months after the emergency |
| Clinic, school or distribution point | A larger frame (about 24 m²) from the same parts | Temporary public buildings |

## Constraints

- Garage-buildable prototype, concept budget $445 USD for one size M frame kit (approved by Amish, 2026-09-26). Tarpaulins come from agency stock and are costed separately (SNF-DDR-001 D1).
- Members are trade-size EMT conduit, cut to length and drilled only. No bending, flattening or welding.
- No tools on site for erection. Hands only, plus parts of the kit itself (for example, a tube used as a lever to turn a screw anchor).
- Every package that a person carries weighs 25 kg (55 lb) or less (three packages for size M: two tube bundles and a bag, decided 2026-10-02), and no member is longer than about 2.1 m, so the kit fits a pickup bed and a standard pallet.
- Skin is standard relief tarpaulin (4 x 6 m reinforced polyethylene), tied on, not a custom-cut fabric.
- The frame must be understood and erected by people who have not seen it before, with a picture guide and no written language needed.
- Operating range about 0 to 50 °C air temperature, with node surfaces in full sun reaching higher.

## Out of scope

- Snow load (SNF-DDR-001 D7). The first release is for warm and temperate climates; cold-climate winterization needs a heavier frame and is a later variant.
- Cyclone and hurricane rating (SNF-DDR-001 D7). SnapFrame is an emergency shelter, not a storm refuge. Occupants must follow local evacuation guidance.
- Floors, insulation, doors that lock, and sanitation.
- Multi-story use or hanging loads beyond a lamp and a mosquito net.

## Prior work

- **IFRC shelter kit.** Two 4 x 6 m tarpaulins plus rope, fixings and tools; the frame comes from local material ([IFRC and ICRC items catalogue](https://itemscatalogue.redcross.int/relief--4/shelter-and-construction-materials--23/shelter-and-construction-kits--104/shelter-kit--KRELSHEK02.aspx)). SnapFrame is sized so the same two tarpaulins cover the roof, both side walls and one gable.
- **UNHCR family tent.** 16 m² main floor plus two 3.5 m² vestibules, canvas over poles, for a family of five ([UNHCR family tent fact sheet](https://unis.unvienna.org/pdf/factsheets/UNHCR_tent.pdf)). SnapFrame size M matches the main floor area.
- **Better Shelter (Relief Housing Unit).** 17.5 m², steel frame, polymer panels, supplied as a flat pack; panels are rated for at least three years and the frame for at least ten ([Better Shelter](https://bettershelter.org/relief-housing-unit-rhu/)). It shows that a flat-pack frame works in the field, and that fire performance of the cladding must be addressed early; Zurich set the units aside over fire concerns in 2015 ([Humanosphere](https://www.humanosphere.org/basics/2015/12/ikea-shelters-fail/)).
- **EMT geodesic domes and shade structures.** Widely built by hobbyists and event crews from EMT with flattened, drilled and bolted ends ([Domerama](https://www.domerama.com/fabricating/making-the-struts/geodesic-dome-struts-flattening/)). They prove the tube is available, cheap and strong enough for light cladding, and show the weakness of site-drilled, bolted joints.
- **MERO space frame.** Max Mengeringhausen's tube construction method from the end of the 1930s builds structures from industrially prefabricated series elements ([MERO](https://mero.de/en/the-company/)): tubular rods screwed into near-spherical node pieces ([EP0475216B1, MERO Raumstruktur](https://patents.google.com/patent/EP0475216B1/de)). SnapFrame applies the same principle at family-shelter scale, with hand-locking joints in place of screwed ones.
- **Tent pole snap buttons.** Spring-loaded buttons that pop into a hole to lock two tubes, as used in camping gear and walking aids. SnapFrame uses the same part at every tube end.
- **Wind loading.** Design pressures follow the method of ASCE/SEI 7 ([ASCE](https://www.asce.org)) at first order: dynamic pressure q = ½ρv² times a pressure coefficient.

## Open questions

- Which partner and region to design with first (an IFRC national society shelter team, an NGO with a print farm, or a university humanitarian engineering group)? Decided 2026-10-02: the first candidate to approach is the IFRC Shelter Research Unit, for a technical review of the kit with standard relief tarpaulins, with Field Ready as the printing partner; the region is taken from the first warm-climate response the review points to. Nothing is agreed (SNF-DEC-001).
- Tarpaulins come from agency stock (decided, SNF-DDR-001 D1). Do partner agencies stock a fire-retardant tarpaulin (R13)?
- Nodes are printed for the prototype and designed for casting later (decided, SNF-DDR-001 D3). Which polymer, and are printed nodes acceptable to a partner for a first field trial?
- The frame is rated at about 19.7 m/s by calculation with 1 in ridge tubes (SNF-CAL-001 v0.2, SNF-DDR-002 D8), just below the 20 m/s target. What rating do partners need, and what is the procedure above it (drop the skin, add guys, evacuate)?
- Is metric EMT or other thin-wall steel tube of similar diameter stocked in the target region, and at what price?

## User research and co-design

This design is for communities the author is not part of, so requirements come from the people who will use it.

- [ ] Identify a local partner organization (Helpful Engineering network, NGO or university)
- [ ] Run co-design sessions with intended users; record who, where and what was learned
- [ ] Validate floor area, headroom, erection time, wind exposure and cost assumptions in the field
- [ ] Revise requirements (REQ) from findings before freezing the design

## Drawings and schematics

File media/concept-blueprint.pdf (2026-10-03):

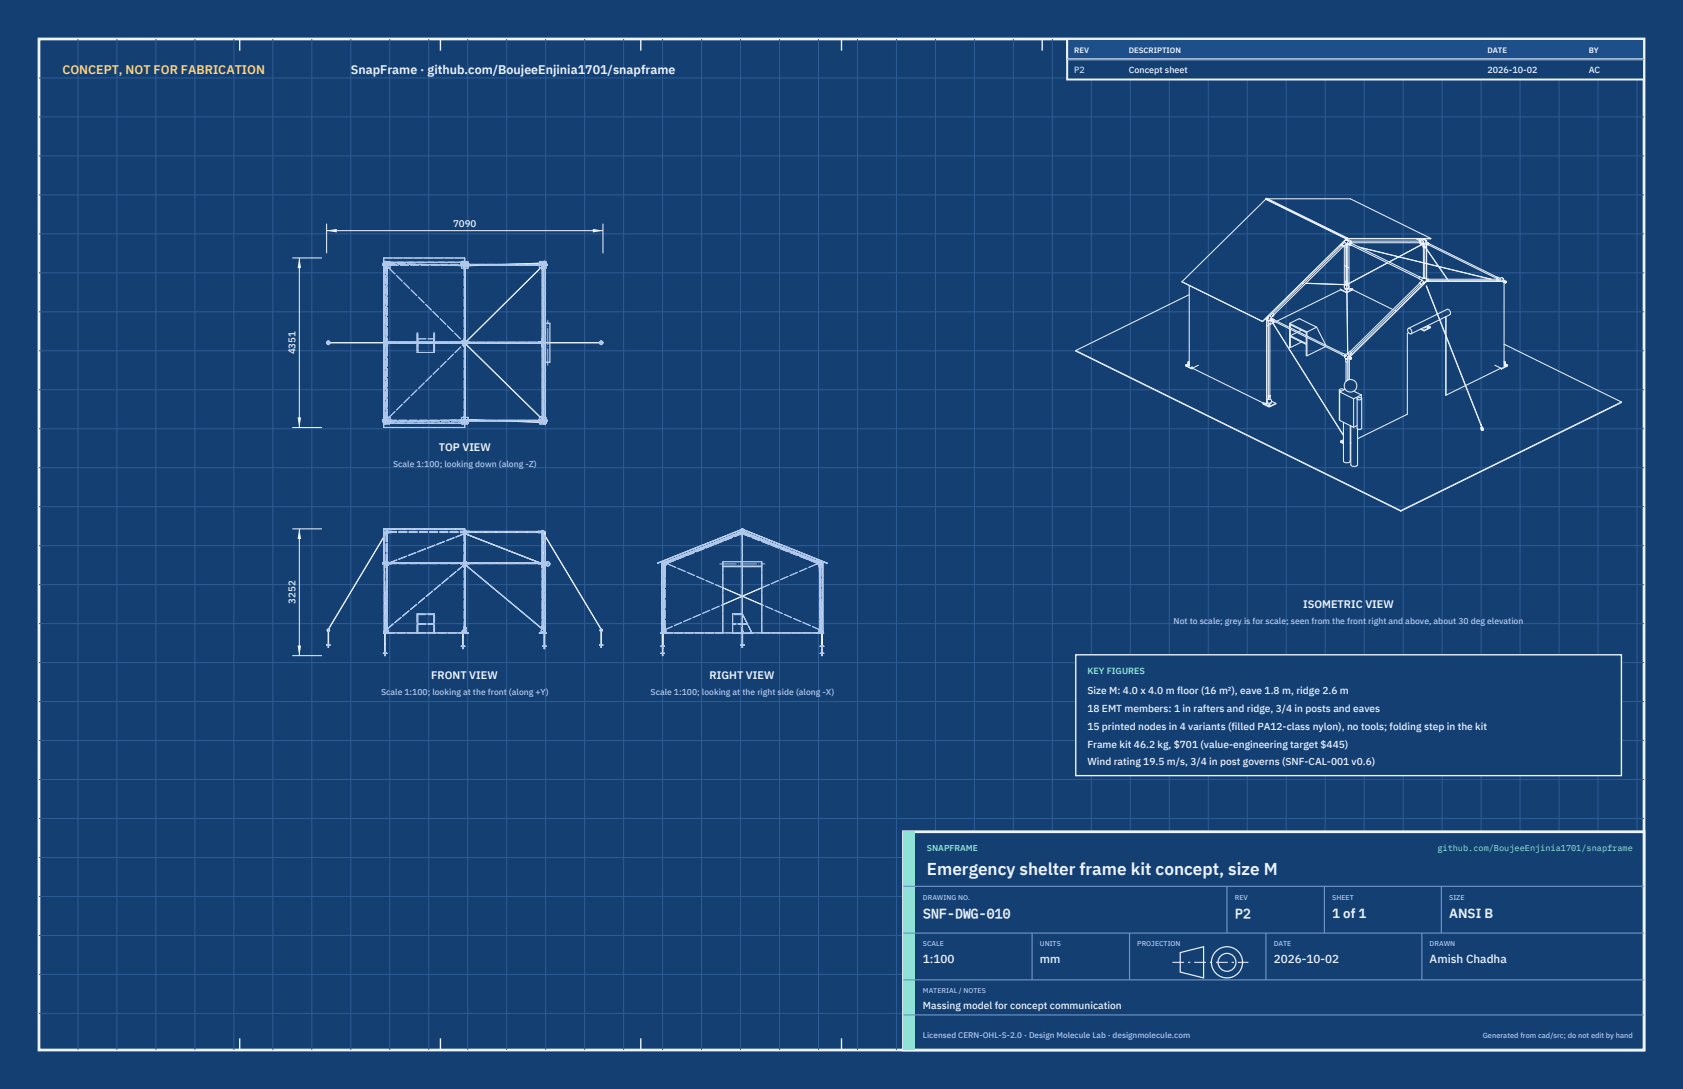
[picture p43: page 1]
CONCEPT, NOT FOR FABRICATION; SnapFrame · github.com/BoujeeEnjinia1701/snapframe; FRONT VIEW; TOP VIEW; RIGHT VIEW; ISOMETRIC VIEW; REV; DESCRIPTION; DATE; Concept sheet; SNAPFRAME; github.com/BoujeeEnjinia1701/snapframe; DRAWING NO. SNF-DWG-010; REV P2; SHEET 1 of 1; SIZE ANSI B; SCALE 1:100; UNITS mm; PROJECTION; DRAWN Amish Chadha; Licensed CERN-OHL-S-2.0 · Design Molecule Lab · designmolecule.com; Generated from cad/src; do not edit by hand

Scale 1:100; looking down (along -Z)

Not to scale; grey is for scale; seen from the front right and above, about 30 deg elevation

KEY FIGURES
Size M: 4.0 x 4.0 m floor (16 m²), eave 1.8 m, ridge 2.6 m
18 EMT members: 1 in rafters and ridge, 3/4 in posts and eaves
15 printed nodes in 4 variants (filled PA12-class nylon), no tools; folding step in the kit
Frame kit 46.2 kg, $701 (value-engineering target $445)
Wind rating 19.5 m/s, 3/4 in post governs (SNF-CAL-001 v0.6)

Scale 1:100; looking at the front (along +Y)

Scale 1:100; looking at the right side (along -X)

Emergency shelter frame kit concept, size M

MATERIAL / NOTES
Massing model for concept communication

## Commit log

2026-09-24 Initial scaffold: standard open hardware layout, CERN-OHL-S v2 + MIT licenses
    Claude-Session: https://claude.ai/code/session_01XuhhSU4W6fYhgCfURbrkut
    [bom.csv]
2026-09-25 Adopt portfolio kit v1.3.0: session commands, scale figure, 3D viewer, flow diagrams
    Adds .claude/commands (/populate, /advance-trl3, /rein-in, /refresh-media)
    so every Claude Code session starts from the standard prompts, and extends
    concept media with a 1.75 m scale figure, an interactive glTF viewer and
    system or energy flow diagrams. TRL cap 3 unchanged.
    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
2026-09-25 Kit v1.3.1: renderer fixes from the TremorTrace pilot
    Context scale parts for small objects, cutaway exclusions, and text
    labels in flow diagrams.
    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
2026-09-25 Populate snapframe to a strong TRL 2 with concept media (batch 7)
    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
    [bom.csv]
2026-09-25 Advance snapframe to TRL 3 (batches 7 and 8)
    Decisions approved by Amish 2026-09-25 recorded in DDR-001. TRL 4 is on hold.
    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
    [bom.csv, snapframe-L-eave-corner-L.stl, snapframe-L-eave-corner-R.stl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]
2026-09-26 Accept all recommendations (DDR-002), switch footer to designmolecule.com, add README write-up with new inspiration point
    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
    [bom.csv, snapframe-L-eave-corner-L.stl, snapframe-L-eave-corner-R.stl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]
2026-09-27 Product appearance model and photoreal renders
    Adds cad/src/product_model.py (appearance model for renders only, all main
    dimensions from model.py) and Blender renders in media/render-*.png,
    captioned with the project, repository and viewing direction. README leads
    with the product render; trl stays 3.
    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
2026-10-01 Image quality pass: legible exploded views, flow diagrams and drawing sheets
    Kit 1.6.1 image layout: the parts list sits in its own column, number bubbles sit on visible parts and never overlap, small parts get a leader, pictures are cropped to the subject, flow labels keep numbers with their units, and sheet captions and the revision table no longer overprint. Concept images, blueprint and general arrangement sheet regenerated; repo-specific labels moved clear of other text and lines.
2026-10-02 Kit 1.7.0: constructable design, illustrated build plan and design decisions register
    The design is now constructable: every part can be made and fits its neighbours, with each change recorded in a Design for construction decision record (made under Amish's 2026-09-30 instruction; ope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
    FlexHand also credits Dr. Geeti Chadha as a contribut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
    [bom.csv, snapframe-L-eave.stl, snapframe-L-foot.stl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]
2026-10-02 Record Amish's approval of the open-decision recommendations
    Amish approved the recommendation on every open decision in the design decisions register ("i approve your recommendations for all 555 open decisions.", 2026-10-02). Each decision is moved to Decisio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
2026-10-03 Carry approved follow-ups into the design and redo photoreal renders
    Amish approved the follow-up actions from the open-decision sign-off ("APPROVED CHANGES, COMPLETE THESE", 2026-10-02), the design-for-construction change tables in ten repos, the last wave's open dec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
    [bom.csv, snapframe-L-nodes.step, snapframe-M-assembly.step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]
2026-10-03 Record Amish's 2026-10-03 decisions; FlatTrike fork and PotPress guard fixes
    Amish, 2026-10-03: "PalletPilot - i accept it"; "FlatTrike - i accept your design recommendation, proceed and execute the solution for fork direction or caster"; "PotPress - move forward with the four guard fixes. I accept the cost."; "GravitySort - i accept your recommendation"; "TIght Margins - i accept the margins"; "Cost over target - i accept all the cost variations and overruns". FlatTrike knuckle forks turned to trail (35 mm trail); PotPress finer mesh, small-hole plates, top beam and crank bracket covers, ISO 13857 desk check now met on paper. Registers, requirements, drawings, pictures, renders and PDFs upd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

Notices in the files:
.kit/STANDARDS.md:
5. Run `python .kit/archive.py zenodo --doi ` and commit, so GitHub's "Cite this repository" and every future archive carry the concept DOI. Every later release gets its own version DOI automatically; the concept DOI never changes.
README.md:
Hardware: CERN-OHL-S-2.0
